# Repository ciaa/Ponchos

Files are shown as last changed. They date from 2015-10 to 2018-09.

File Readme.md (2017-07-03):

Ponchos
=======
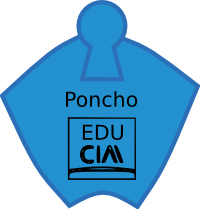
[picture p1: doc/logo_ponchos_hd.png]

Repositorio de Ponchos para la EDU-CIAA.

Llamamos **Ponchos** a los módulos conectables para montarse sobre el 
módulo procesador EDU-CIAA. 
Esperamos que el nombre “Poncho” se utilice como “Shield” en Arduino 
entre la comunidad del proyecto CIAA.

La documentación adicional sobre Ponchos se encuentra en la 
[Wiki del proyecto CIAA](http://www.proyecto-ciaa.com.ar/devwiki/doku.php?id=desarrollo:edu-ciaa:ponchos).

---

Estructura de directorios
-------------------------

* kicad: Bibliotecas de Kicad que utilizan los Ponchos.
  *libPonchos: Símbolos de esquemático (.lib) para crear un Poncho.
  *libModelos: Símbolos de esquemático (.lib) que usan los modelos.
  *Poncho_Esqueleto.pretty: Módulos que ayudan a crear un Poncho.
  *Poncho_Modelos.pretty: Módulos que utilizan los modelos.

* doc: Documentación común a todos los Ponchos.

* modelos: Ponchos básicos de ejemplo.
  * doc: Documentación particular.
  * Poncho_Grande: Un Poncho del mismo tamaño que la CIAA, con área de prototipado.
  * Poncho_Chico: Un Poncho que usa ambos conectores, pero ningún agujero de sujeción.

* ethernet_LAN8720A: Poncho Ethernet con el LAN8720A de MicroChip.
  * doc: Documentación particular del Poncho Ethernet.
  * info: Información adicional.
  * kicad: Archivos Kicad del Poncho Ethernet
    * hdatos: Hojas de datos relacionadas.
    * 3D: Modelos 3D. 

Ponchos nuevos
--------------

Al poner un Poncho en este repositorio intentar respetar como está organizado (abierto a debate). 
Las pautas al momento son las siguientes:

* Se abre un subdirectorio con el nombre del poncho: Por ejemplo, xyz.
* Dentro se ponen los archivos kicad y subdirectorios para la documentación, hojas de datos, etc.
* Los símbolos utilizados se ponen a partir de la raíz principal del repo en /kicad/libXyz.
* Los módulos utilizados se ponen a partir de la raíz principal del repo en /kicad/Poncho_Xyz.pretty

Idioma
------
El idioma de documentación de las EDU-CIAA es el castellano, por lo tanto los 
ponchos seguirán esa misma pauta. Se recomienda usar UTF-8 para los textos.

---
Proyecto CIAA http://www.proyecto-ciaa.com.ar/

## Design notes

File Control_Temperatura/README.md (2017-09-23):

# TPdesign_poncho
Nombre corto del proyecto: 
Interfaz de termocupla K mas salidas a Relay

Autor:
Francisco Suárez

Fecha de este documento::

28 Mayo de 2017

Licencia:
BSD
GPL V3, Open Hardware

Descripción:
Es una poncho destinado a intermediar con termocuplas mas el control de dos interruptores a traves de relays, pensado para hacer control de temperatura en un tanque de agua a travez de resistencias.

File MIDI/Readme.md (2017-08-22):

Poncho MIDI
===========
Poncho interfaz MIDI para la EDU-CIAA.

Este poncho fue diseñado con el objetivo de otorgar al proyecto CIAA de una interfaz MIDI acorde a las especificaciones eléctricas presentes en la _Especificación detallada del estándar MIDI 1.0_ y su posterior modificación en la _Actualización de Especificación Electrica (CA-033)_ del año 2014.

La documentación de las especificaciones citadas puede encontrarse en [Especificaciones Oficiales de la Asociación MIDI](https://www.midi.org/specifications).

Además de **12 pulsadores**, **3 encoders** (con pulsadores cada uno) y los **conectores para** las funcionalidades **MIDI IN**, **MIDI THRU** y **MIDI OUT**; se incluye un par de conectores tipo header para _stackear_ otros módulos para agregar funcionalidad a través de **_I2C_** o **entradas y salida analógicas** en caso de no poder acceder a conectores del tipo [Elevated socket](https://www.digikey.com/product-detail/en/samtec-inc/ESQ-120-14-G-D/SAM8767-ND/2640978) para fabricar el poncho y permitir otro nivel de _stacking_.

<p align="center">
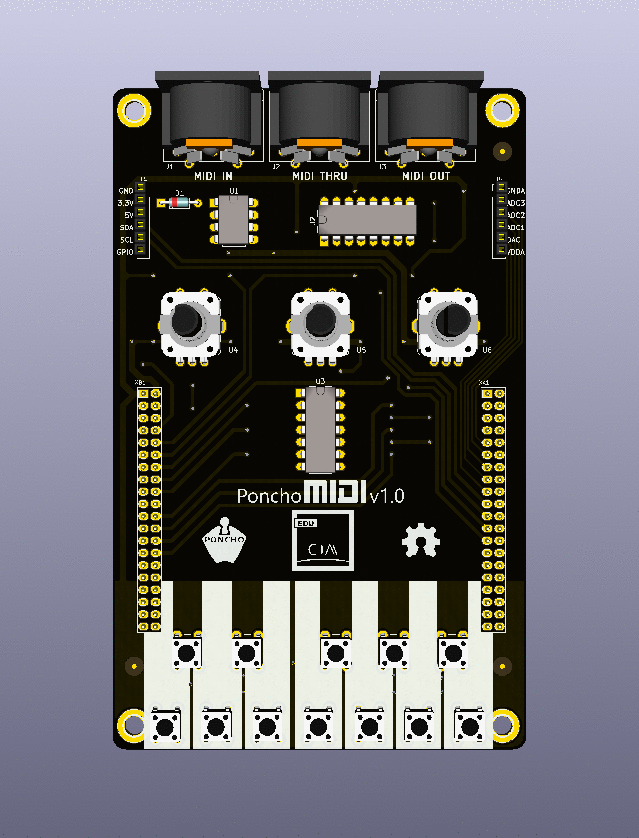
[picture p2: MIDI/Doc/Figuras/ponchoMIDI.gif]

</p>

---

Releases
--------

* **v1.0**
  * Release inicial para fabricación de serie piloto para validación de diseño.

* **v0.9**
  * Primera y última versión del poncho manteniendo como requisito la posibilidad de manufactura casera y artesanal. Si bien su realización sería compleja, el circuito presenta vias redundantes para cambiar de capa y que eliminan la necesidad de utilizar orificios metalizados.

Requisitos de diseño
--------------------

* Requisitos comunes a todos:
  * Licencia abierta (se tiene que poder publicar los archivos KiCad y la funcionalidad del circuito).
  * Utilizar Kicad 4.0.x. 
  * Consolidar toda la documentación en forma organizada dentro del directorio de proyecto de KiCad.
  * Aplicar una licencia o aclarar el Copyright.
  * Considerar en cada caso, los aspectos vistos referente a documentación.
  * Realizar diseño jerárquico salvo en circuitos muy pequeños.
  * Siempre que sea posible, considerar para los diseños componentes que se consigan en el mercado local.
  * Se utilizará como proveedor de referencia a Mayer (para las reglas de diseño).
  * Indicar que tipo/calidad de placa se considera para el diseño, intentando siempre que sea posible, seleccionar la de menor costo. 

* Requisitos específicos:
  * Debe realizarse en un circuito de 2 capas.
  * Debe cumplir con los requerimientos y recomendaciones de **(CA-033) MIDI 1.0 Electrical Specification Update [2014]**, que modifica a **MIDI 1.0 Detailed Specification (Document Version 4.2)** en el apartado de hardware.
  * Debe contener conectores para funcionalidades: MIDI IN, MIDI THRU y MIDI OUT.
  * Debe integrar 12 interruptores SPST, NO y sin retención.
  * Debe integrar 3 encoders rotativos con interruptor SPST, NO y sin retención incluido.
  * Debe facilitar la utilización de los conversores A/D de la EDU-CIAA.
  * Debe facilitar la utilización del conversor D/A de la EDU-CIAA.
  * Debe ocupar, como máximo, la superficie del poncho grande.

Asignación de pines
-------------------
<p align="center">

| Elemento	| Nombre EDU-CIAA	| Puerto	|
| --- |:---:|:---:|
| pulsador 0 	| GPIO8			| P6_12		|
| pulsador 1 	| GPIO7			| P6_11		|
| pulsador 2 	| GPIO5			| P6_9		|
| pulsador 3	| GPIO3			| P6_7		|
| pulsador 4	| GPIO1			| P6_4		|
| pulsador 5	| LCD1  		| P6_4		|
| pulsador 6	| CAN_TD 		| P3_2 		|
| pulsador 7	| T_COL1 		| P7_4 		|
| pulsador 8	| T_FIL0 		| P4_0 		|
| pulsador 9	| T_FIL3 		| P4_3 		|
| pulsador 10	| T_FIL2 		| P4_2 		|
| pulsador 11	| T_COL0 		| P1_5 		|
| encoder0_sw	| CRS_DV		| P1_16 	|
| encoder1_sw	| MDIO			| P1_17 	|
| encoder2_sw	| TXD0			| P1_18 	|
| encoder0_A	| SPI_MISO		| P1_3 		|
| encoder0_B	| TXD1 			| P1_20 	|
| encoder1_A	| LCD4 			| P4_10 	|
| encoder1_B	| LCD_RS 		| P4_8 		|
| encoder2_A	| LCD_3 		| P4_6 		|
| encoder2_B	| LCD_2 		| P4_5 		|
| MIDI_IN	| RS232_RXD		| P2_4 		|
| MIDI_OUT	| RS232_TXD		| P2_3 		|

</p>

Los puertos de expansión son una extensión sin cambios de la asignación de la EDU-CIAA.

Figuras
-------

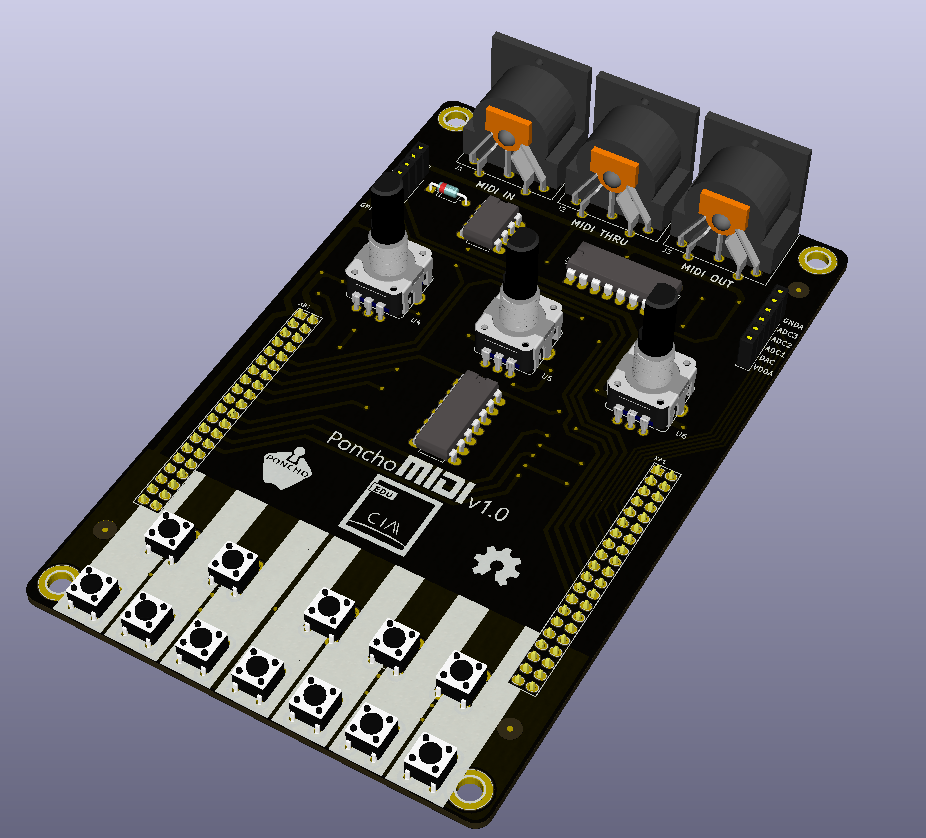
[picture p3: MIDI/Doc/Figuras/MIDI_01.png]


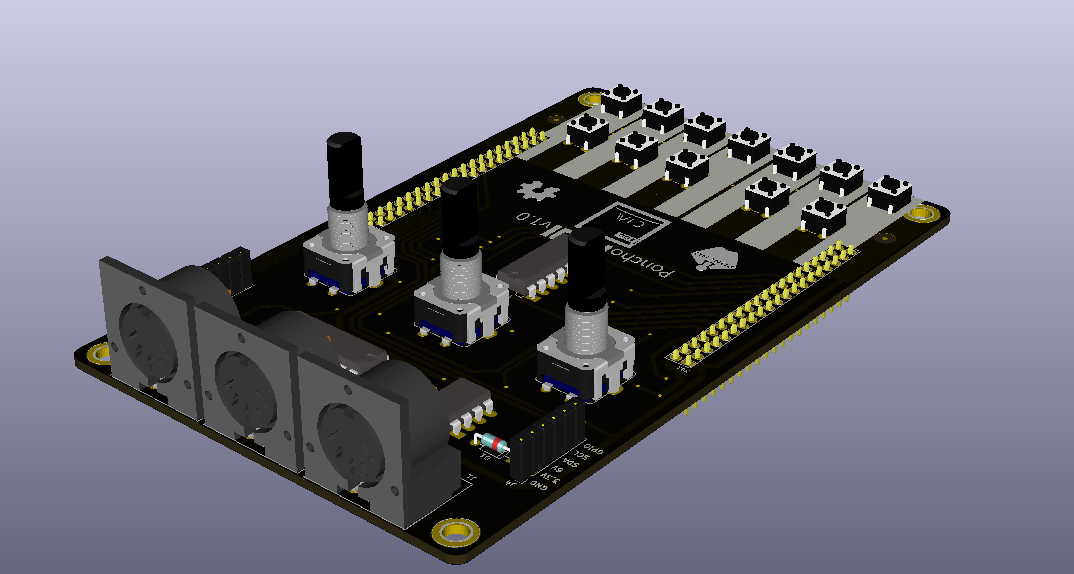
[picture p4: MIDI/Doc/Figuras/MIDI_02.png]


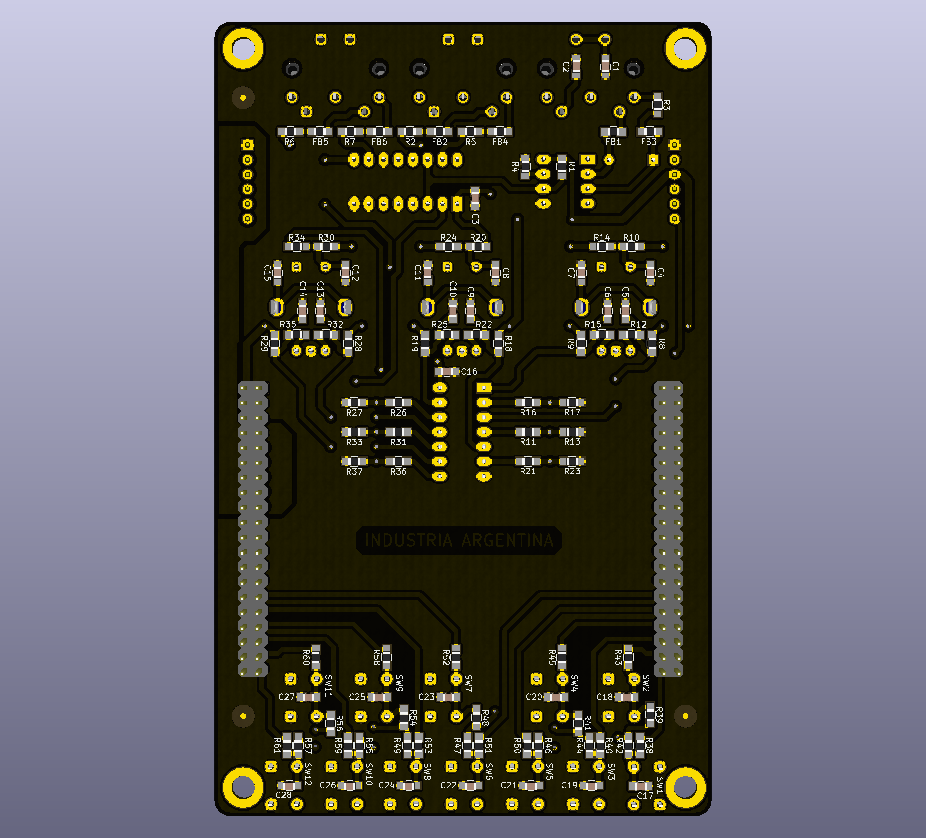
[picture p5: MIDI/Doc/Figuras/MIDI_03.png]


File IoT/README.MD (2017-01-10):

#Poncho IOT (Internet Of Things) para EDU-CIAA-NXP 

##Características Poncho

  - Módulo Wifi RN1810. Se utiliza mediante comandos por el puerto serial.
  - Dos salidas a Rele 220V-10A
  - Dos entradas optoacopladas
  - Sensor de temperatura analógico LM35
  
##Características PCB

El PCB fue pensado para ser construido manualmente, por lo que solo posee una capa (BOTTOM). La capa TOP solo indica jumpers que deben soldarse. Tambien es posible fabricarla en dos capas.
  
##Modelo 3D

<p align="center">
  
</p>

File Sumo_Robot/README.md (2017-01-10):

# PONCHO EDU-CIAA ROBOT SUMO #
 
RESPONSABLE:  
 
## ACTIVIDAD ##
Realizar un Poncho para la Edu-CIAA que permita controlar un robot sumo. 
 
## PAUTAS ##
  * PCB de doble capa (se manda a fabricar).  
  * Ver restricciones de Mayer S.A, de 12 Mils, pero se podría ver uno más barato. 
  * Manejo de dos motores en ambos sentidos, con relés. 
  * Manejo de 4 sensores de línea infrarrojos. 
  * Entrada de dos pulsadores. 
  * Manejo de un relé o salida transistor adicional. 
  * Posibilidad de manejar un servo. 
  * Posibilidad de conectar uno o dos módulos de ultrasonido FR04. 
  * Opción acelerómetro I2C. 
  * Considerar alimentación de 12 Volts. 
  * Considerar protecciones en el manejo de potencia: Motores, bobinas de relés y 
servos.

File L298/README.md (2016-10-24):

Desarrollo de un Modulo para motores basado en el L298.
Por: Juan Carlos Suarez Baron

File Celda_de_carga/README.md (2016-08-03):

# LoadCellShield

Proyecto de modulo externo (Poncho) de una celda de carga para la EDU-CIAA, durante el curso de Diseño de PCB del CESE.

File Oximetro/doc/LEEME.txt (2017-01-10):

Poncho oxímetro
=============

La función del poncho es implementar un oximetro de pulso basado en el integrado AFE4490 de Texas Instruments y usando como configuración del sensor el estándar introducido por Nellcor. 

URL: (URL en la wiki de la CIAA)
FUNCIÓN: Poncho de oxímetro de pulso.
AUTORES/INSTITUCIONES: Fernando Meira- CESE

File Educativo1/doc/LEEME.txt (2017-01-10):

EDUPONCHO
=============

Este circuito tiene una  variedad de componentes para realizar ensayos variados y poder aplicar los conceptos aprendidos en la carrera.
Implementa entradas Analógicas, salidas PWM, salidas a relé y  entradas optoacopladas.

URL: (URL en la wiki de la CIAA)
FUNCIÓN: Poncho Educativo.
AUTORES/INSTITUCIONES: Evangelista Guillermo- CESE

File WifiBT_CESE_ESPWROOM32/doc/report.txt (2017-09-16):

Info: Reading netlist file "E:\Embebidos\Materias\Diseño de PCB\Proyectos\PonchoEDUCIAA_WIFI_BLT\PonchoEDUCIAA_WIFI_BLT.net".

Info: Using references to match components and footprints.

Info: Checking netlist component footprint "C1:/591B3730:Capacitors_SMD:C_0603_HandSoldering".

Info: Checking netlist component footprint "C2:/591B36A3:Capacitors_SMD:C_0603_HandSoldering".

Info: Checking netlist component footprint "C3:/591B3654:Capacitors_SMD:C_0603_HandSoldering".

Info: Checking netlist component footprint "C4:/591B3D46:Capacitors_SMD:C_0603_HandSoldering".

Info: Checking netlist component footprint "C5:/591BA60B:Capacitors_SMD:C_0603_HandSoldering".

Info: Checking netlist component footprint "D1:/5915C6BB:LEDs:LED_0805".

Replacing component "D1:/5915C6BB" footprint "LEDs:LED_0402" with "LEDs:LED_0805".

Changing component "D1:/5915C6BB" pin "2" net name from "" to "Net-(D1-Pad2)".

Changing component "D1:/5915C6BB" pin "1" net name from "" to "GND".

Info: Checking netlist component footprint "D2:/5915C18C:LEDs:LED_0805".

Replacing component "D2:/5915C18C" footprint "LEDs:LED_0402" with "LEDs:LED_0805".

Changing component "D2:/5915C18C" pin "2" net name from "" to "Net-(D2-Pad2)".

Changing component "D2:/5915C18C" pin "1" net name from "" to "GND".

Info: Checking netlist component footprint "D3:/5915C2A8:LEDs:LED_0805".

Replacing component "D3:/5915C2A8" footprint "LEDs:LED_0402" with "LEDs:LED_0805".

Changing component "D3:/5915C2A8" pin "2" net name from "" to "Net-(D3-Pad2)".

Changing component "D3:/5915C2A8" pin "1" net name from "" to "GND".

Info: Checking netlist component footprint "F1:/592DFF9B:PonchoEDUCIAA_WIFI_BLTH:Fiducial_1mm".

Info: Checking netlist component footprint "F2:/592E0238:PonchoEDUCIAA_WIFI_BLTH:Fiducial_1mm".

Info: Checking netlist component footprint "F3:/592E4AA5:PonchoEDUCIAA_WIFI_BLTH:Fiducial_1mm".

Info: Checking netlist component footprint "J1:/591B2551:PonchoEDUCIAA_WIFI_BLTH:CON_PALETA_3".

Info: Checking netlist component footprint "R1:/5915C673:Resistors_SMD:R_0805_HandSoldering".

Info: Checking netlist component footprint "R2:/591B3C47:Resistors_SMD:R_0805_HandSoldering".

Info: Checking netlist component footprint "R3:/591B39FC:Resistors_SMD:R_0805_HandSoldering".

Info: Checking netlist component footprint "R4:/5915C27A:Resistors_SMD:R_0805_HandSoldering".

Info: Checking netlist component footprint "R5:/5915BEE9:Resistors_SMD:R_0805_HandSoldering".

Info: Checking netlist component footprint "R6:/591BB74F:Resistors_SMD:R_0805_HandSoldering".

Info: Checking netlist component footprint "R7:/591BB4D7:Resistors_SMD:R_0805_HandSoldering".

Info: Checking netlist component footprint "R8:/594ED4F2:Resistors_SMD:R_0805_HandSoldering".

Info: Checking netlist component footprint "SW1:/591BAB0F:Buttons_Switches_THT:SW_PUSH_6mm".

Info: Checking netlist component footprint "SW2:/591BBB9C:Buttons_Switches_THT:SW_Micro_SPST".

Info: Checking netlist component footprint "U1:/5911A5F3:PonchoEDUCIAA_WIFI_BLTH:ESP32-WROOM".

Info: Checking netlist component footprint "XA1:/5911AAD2:PonchoEDUCIAA_WIFI_BLTH:Conn_Poncho_Derecha".

Removing unused component "G1:".

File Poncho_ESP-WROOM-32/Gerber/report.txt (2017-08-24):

Se ha creado el archivo de trazado 'D:\Proyectos\Poncho_ESP-WROOM-32\Gerber\Poncho_ESP32-F.Cu.gbr'.
Se ha creado el archivo de trazado 'D:\Proyectos\Poncho_ESP-WROOM-32\Gerber\Poncho_ESP32-B.Cu.gbr'.
Se ha creado el archivo de trazado 'D:\Proyectos\Poncho_ESP-WROOM-32\Gerber\Poncho_ESP32-B.Paste.gbr'.
Se ha creado el archivo de trazado 'D:\Proyectos\Poncho_ESP-WROOM-32\Gerber\Poncho_ESP32-F.Paste.gbr'.
Se ha creado el archivo de trazado 'D:\Proyectos\Poncho_ESP-WROOM-32\Gerber\Poncho_ESP32-B.SilkS.gbr'.
Se ha creado el archivo de trazado 'D:\Proyectos\Poncho_ESP-WROOM-32\Gerber\Poncho_ESP32-F.SilkS.gbr'.
Se ha creado el archivo de trazado 'D:\Proyectos\Poncho_ESP-WROOM-32\Gerber\Poncho_ESP32-B.Mask.gbr'.
Se ha creado el archivo de trazado 'D:\Proyectos\Poncho_ESP-WROOM-32\Gerber\Poncho_ESP32-F.Mask.gbr'.
Se ha creado el archivo de trazado 'D:\Proyectos\Poncho_ESP-WROOM-32\Gerber\Poncho_ESP32-Edge.Cuts.gbr'.

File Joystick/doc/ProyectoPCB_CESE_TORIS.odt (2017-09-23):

Curso de Diseño de PCBs - CESE

Hoja de presentación de proyecto

Nombre corto del proyecto:

Joystick con edu-ciaa

Autor:

Alan Toris

Fecha de este documento:

14 de Mayo de 2017

Licencia:

BSD

Repositorio de trabajo:

https://gitlab.com/alantoris/poncho-joystick-edu-ciaa

Descripción:

Este circuito implementa un poncho de la edu-ciaa con funcionalidad de Joystick que puede ser usado como interface de control de otros sistemas como juegos en pantallas o proyectos con motores.

Requisitos del profesor:

Colocar los requisitos acordados con el profesor. Por ejemplo funciones mínimas, número de capas, tipo de fabricación, tipo de componentes y tecnología de montaje, circuitos de referencia charlados en clase, etc.

Requisitos comunes a todos:

1. Licencia abierta (se tiene que poder publicar los archivos KiCad y la funcionalidad del circuito).
2. Utilizar Kicad 4.0.x.
3. Consolidar toda la documentación en forma organizada dentro del directorio de proyecto de KiCad.
4. Aplicar una licencia o aclarar el Copyright.
5. Considerar en cada caso, los aspectos vistos referente a documentación.
6. Realizar diseño jerárquico salvo en circuitos muy pequeños.
7. Siempre que sea posible, considerar para los diseños componentes que se consigan en el mercado local.
8. Se utilizará como proveedor de referencia a Mayer (para las reglas de diseño).
9. Indicar que tipo/calidad de placa se considera para el diseño, intentando siempre que sea posible, seleccionar la de menor costo.

Tareas y Alcance:

Las tareas y alcance del proyecto serán:

1. Búsqueda de los esquemáticos de referencia.
2. Adaptaciones y agrupacion de los esquemático.
3. Ingreso de esquemático a Kicad.
4. Revisión del esquemático por Fabrizio Gelsi.
5. Cálculo de presupuesto y proveedores de componentes.
6. Selección de footprints.
7. Ubicación de componentes.
8. Ruteo.
9. Generación de Gerbers.

Enlaces:

Esquematico de un Joystick básico compatible con Arduino:

http://image.dfrobot.com/image/data/DFR0008/Input%20Shield%20V2%20sch.pdf
Se cambiara los pines de coneccion al modulo zigbee por pines de coneccion a un modulo acelerometro para agregar una funcionalidad de movimiento al Joystick.
Esquematico de un motor vibrador:

https://github.com/Arduinolibrary/DFRobot_Vibration_Module/raw/master/Vibration%20Schematic.pdf

Esquematico de un modulo speaker digital:

https://github.com/Arduinolibrary/DFRobot_Vibration_Module/raw/master/Vibration%20Schematic.pdf

Imágenes:

Modulo en los cuales se basa el proyecto:

Joystick básico compatible con Arduino:

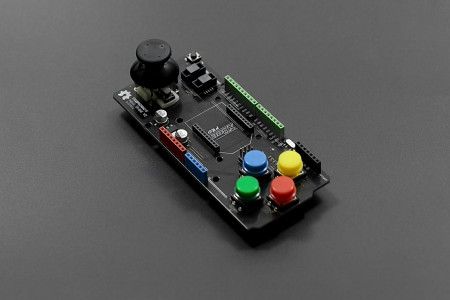
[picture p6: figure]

Modulo de motor vibrador:

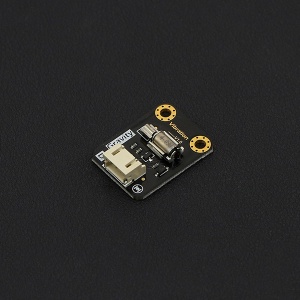
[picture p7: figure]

Modulo de speaker digital:

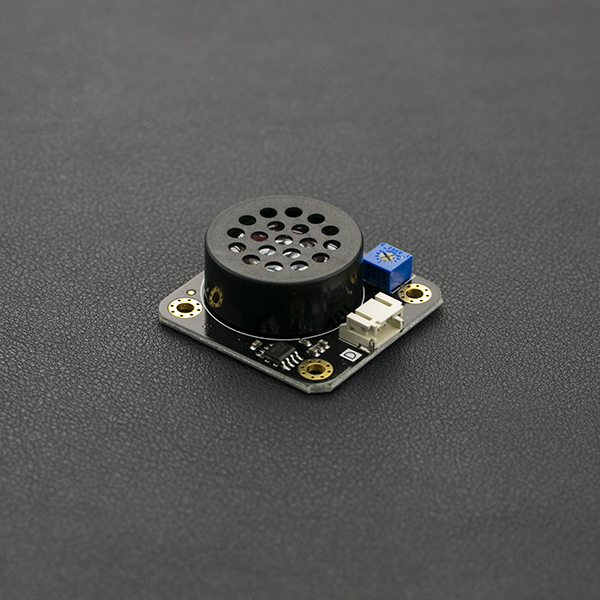
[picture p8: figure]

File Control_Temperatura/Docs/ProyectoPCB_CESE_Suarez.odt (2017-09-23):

Curso de Diseño de PCBs - CESE

Hoja de presentación de proyecto

Nombre corto del proyecto:

Interfaz de termocupla K mas salidas a Relay

Autor:

Francisco Suárez

Fecha de este documento::

28 Mayo de 2017

Licencia:

BSD

GPL V3, Open Hardware

Repositorio de trabajo:

https://github.com/fransuarez/TPdesign_poncho.git

Descripción:

Es una poncho destinado a intermediar con termocuplas mas el control de dos interruptores a traves de relays, pensado para hacer control de temperatura en un tanque de agua a travez de resistencias.

Requisitos del profesor:

Requisitos comunes:

1. Licencia abierta (se tiene que poder publicar los archivos KiCad y la funcionalidad del circuito).
2. Utilizar Kicad 4.0.x.
3. Consolidar toda la documentación en forma organizada dentro del directorio de proyecto de KiCad.
4. Aplicar una licencia o aclarar el Copyright.
5. Considerar en cada caso, los aspectos vistos referente a documentación.
6. Realizar diseño jerárquico salvo en circuitos muy pequeños.
7. Siempre que sea posible, considerar para los diseños componentes que se consigan en el mercado local.
8. Se utilizará como proveedor de referencia a Mayer (para las reglas de diseño).
9. Indicar que tipo/calidad de placa se considera para el diseño, intentando siempre que sea posible, seleccionar la de menor costo.

10. Pcb de dos capas.

Tareas y Alcance:

Indicar hasta donde se pretende llegar con el diseño y que tareas involucra. Por ejemplo:

1. Búsqueda de esquemáticos de referencia. (Obligatorio)
2. Adaptaciones de esquemático.
3. Ingreso de esquemático a Kicad. (Obligatorio)
4. Revisión del esquemático por un tercero. (Obligatorio)
5. Cálculo de presupuesto y proveedores de componentes. (Obligatorio)
6. Selección de footprints. (Obligatorio)
7. Ubicación de componentes. (Necesario para una buena calificación)
8. Ruteo. (Depende lo acordado)
9. Generación de Gerbers. (Depende lo acordado)

Enlaces:

http://ospid.com/blog/download/

https://github.com/osPID

Imágenes:

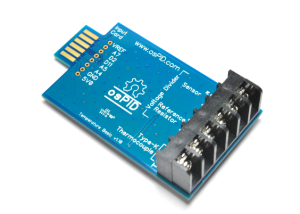
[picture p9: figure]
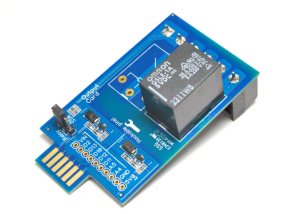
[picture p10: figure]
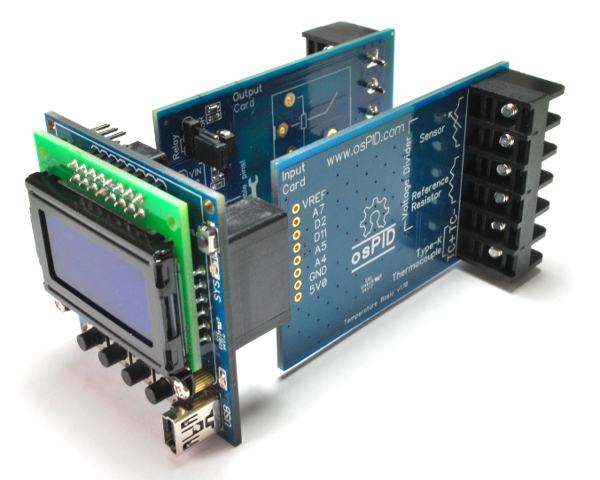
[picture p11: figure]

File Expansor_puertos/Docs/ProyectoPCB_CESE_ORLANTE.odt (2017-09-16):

Curso de Diseño de PCBs - CESE

Hoja de presentación de proyecto

Nombre corto del proyecto:

EduCiaa Port's Expander

Autor:

Orlante Mariano Damián

Fecha de este documento:

15 Mayo de 2017

Licencia:

BSD

Repositorio de trabajo:

https://marianoo2001@gitlab.com/marianoo2001/EduCiaaPE.git

Descripción:

Este circuito implementa un expansor de entradas y salidas digitales, y adaptador de nivel de tensión Low Voltage (3V3) a RS232 para puerto serie.

Las entradas digitales son del tipo a transistor NPN “sinking” y se activan con tensión de continua externa en el rango de entre 3,5 a 25VDC. Las entradas se pueden activar a través de contactos secos o salidas transistorizadas “sourcing”.

Las salidas digitales son del tipo a transistor NPN “sinking” a colector abierto. Una salida activada implica que el dispositivo entrega masa a la carga externa. Se deberá alimentar la carga con una tensión de entre 3,5 a 45VDC. alimentará con baterías y podrá usarse en aplicaciones con la EDU-CIAA.

Requisitos del profesor:

1. Licencia BSD.
2. Utilizar Kicad 4.0.x.
3. Consolidar toda la documentación en forma organizada dentro del directorio de proyecto de KiCad.
4. Aplicar una licencia o aclarar el Copyright.
5. Considerar en cada caso, los aspectos vistos referente a documentación.
6. Realizar diseño jerárquico salvo en circuitos muy pequeños.
7. Siempre que sea posible, considerar para los diseños componentes que se consigan en el mercado local.
8. Se utilizará como proveedor de referencia a Mayer (para las reglas de diseño).
9. Placa de dos capas, con componentes SMD, mascara antisoldante, serigrafías y todo realizado sobre soporte de FR4.
10. Al menos 8 entradas digitales.
11. Al menos 8 salidas digitales.
12. Al menos un puerto serie nivel RS232.

Tareas y Alcance:

1. Búsqueda de esquemáticos de referencia.
2. Adaptaciones de esquemático.
3. Ingreso de esquemático a Kicad.
4. Revisión del esquemático por un tercero.
5. Cálculo de presupuesto y proveedores de componentes.
6. Selección de footprints.
7. Ubicación de componentes.
8. Ruteo.
9. Generación de Gerbers.

Enlaces:

http://www.st.com/content/ccc/resource/technical/document/application_note/38/85/01/85/d2/2d/4d/45/CD00165404.pdf/files/CD00165404.pdf/jcr:content/translations/en.CD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

Imágenes:

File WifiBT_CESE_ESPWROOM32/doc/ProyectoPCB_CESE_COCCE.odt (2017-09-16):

Curso de Diseño de PCBs - CESE

Hoja de presentación de proyecto

Nombre corto del proyecto:

Poncho EDU-CIAA wifi-bluetooth

Autor:

Julio Gastón Coccé

Fecha de este documento::

11 de Mayo de 2017

Licencia:

BSD

Repositorio de trabajo:

https://github.com/gcocce/poncho_EDU-CIAA_wifi_blth

Descripción:

El circuito de este proyecto permite realizar un poncho para la EDU-CIAA usando el módulo ESP-WROOM-32 que cuenta con conectividad WIFI y BLUETOOTH. El circuito se alimenta con energía de la placa EDU-CIAA y se comunicará con la EDU-CIAA por UART.

Requisitos del profesor:

Colocar los requisitos acordados con el profesor. Por ejemplo funciones mínimas, número de capas, tipo de fabricación, tipo de componentes y tecnología de montaje, circuitos de referencia charlados en clase, etc.

Requisitos comunes a todos:

- Licencia abierta (se tiene que poder publicar los archivos KiCad y la funcionalidad del circuito).
- Utilizar Kicad 4.0.x.
- Consolidar toda la documentación en forma organizada dentro del directorio de proyecto de KiCad.
- Aplicar una licencia o aclarar el Copyright.
- Considerar en cada caso, los aspectos vistos referente a documentación.
- Realizar diseño jerárquico salvo en circuitos muy pequeños.
- Siempre que sea posible, considerar para los diseños componentes que se consigan en el mercado local.
- Se utilizará como proveedor de referencia a Mayer (para las reglas de diseño).
- Indicar que tipo/calidad de placa se considera para el diseño, intentando siempre que sea posible, seleccionar la de menor costo.

Tareas y Alcance:

Indicar hasta donde se pretende llegar con el diseño y que tareas involucra. Por ejemplo:

- Búsqueda de esquemáticos de referencia. (Obligatorio)
- Adaptaciones de esquemático.
- Ingreso de esquemático a Kicad. (Obligatorio)
- Revisión del esquemático por un tercero. (Obligatorio)
- Cálculo de presupuesto y proveedores de componentes. (Obligatorio)
- Selección de footprints. (Obligatorio)
- Ubicación de componentes. (Necesario para una buena calificación)
- Ruteo. (Depende lo acordado)
- Generación de Gerbers. (Depende lo acordado)
- Fabricación de prototipo. (Depende lo acordado, normalmente no se incluye)
- Validación funcional. (Depende lo acordado, normalmente no se incluye)

Enlaces:

https://espressif.com/en/producttype/esp-wroom-32

Imágenes:

Colocar imágenes ilustrativas, por ejemplo diseño o estado actual, producto similar o a copiar, etc.

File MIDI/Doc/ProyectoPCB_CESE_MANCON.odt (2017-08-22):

Nombre corto del proyecto:

Poncho MIDI

Autor:

Carlos I. Mancón

Fecha de este documento::

14 de Mayo de 2017

Licencia:

BSD

Repositorio de trabajo:

https://github.com/cmancon/Ponchos

Descripción:

Este circuito implementa una interfaz MIDI conforme a la especificación de dicho estándar y un conjunto de actuadores para el disparo de paquetes e interacción con dispositivos compatibles. Se alimentará a través de USB o fuente externa.

Requisitos:

Requisitos comunes a todos:

1. Licencia abierta (se tiene que poder publicar los archivos KiCad y la funcionalidad del circuito).
2. Utilizar Kicad 4.0.x.
3. Consolidar toda la documentación en forma organizada dentro del directorio de proyecto de KiCad.
4. Aplicar una licencia o aclarar el Copyright.
5. Considerar en cada caso, los aspectos vistos referente a documentación.
6. Realizar diseño jerárquico salvo en circuitos muy pequeños.
7. Siempre que sea posible, considerar para los diseños componentes que se consigan en el mercado local.
8. Se utilizará como proveedor de referencia a Mayer (para las reglas de diseño).
9. Indicar que tipo/calidad de placa se considera para el diseño, intentando siempre que sea posible, seleccionar la de menor costo.
  Requisitos específicos
10. Debe realizarse en un circuito de 2 capas.
11. Debe cumplir con los requerimientos y recomendaciones de "(CA-033) MIDI 1.0 Electrical Specification Update [2014]", que modifica a "MIDI 1.0 Detailed Specification (Document Version 4.2)" en el apartado de hardware.
12. Debe contener conectores para funcionalidades: MIDI IN, MIDI THRU y MIDI OUT.
13. Debe integrar 12 interruptores SPST, NO y sin retención.
14. Debe integrar 3 encoders rotativos con interruptor SPST, NO y sin retención incluido.
15. Debe facilitar la utilización de los conversores A/D de la EDU-CIAA.
16. Debe facilitar la utilización del conversor D/A de la EDU-CIAA.
17. Debe ocupar, como máximo, la superficie del poncho grande.

Tareas y Alcance:

1. Búsqueda de esquemáticos de referencia.
2. Adaptaciones de esquemático.
3. Ingreso de esquemático a Kicad.
4. Revisión del esquemático por un tercero.
5. Cálculo de presupuesto y proveedores de componentes.
6. Selección de footprints.
7. Ubicación de componentes.
8. Ruteo.
9. Generación de Gerbers.

Enlaces:

https://www.midi.org/specifications

https://www.sparkfun.com/products/12898

https://www.olimex.com/Products/Duino/Shields/SHIELD-MIDI/open-source-hardware

Imágenes:

Ejemplos de productos similares:

Sparkfun

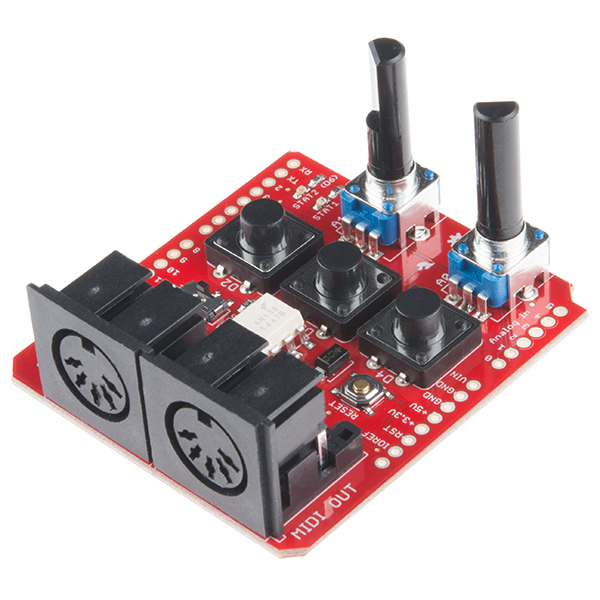
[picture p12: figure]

OLIMEX

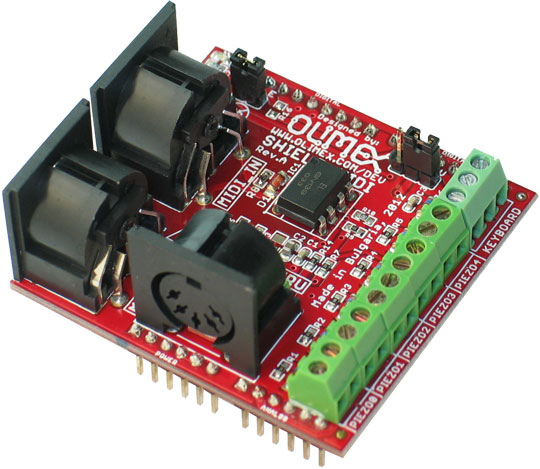
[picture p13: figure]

Curso de Diseño de PCBs - CESE Hoja de presentación de proyecto

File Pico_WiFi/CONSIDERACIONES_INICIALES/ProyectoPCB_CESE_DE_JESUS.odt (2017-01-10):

Curso de Diseño de PCBs - CESE

Hoja de presentación de proyecto

Nombre corto del proyecto:

Poncho wifi para la Pico-CIAA

Autor:

Sergio De Jesús

Fecha de este documento::

11 de noviembre de 2016

Licencia:

BSD

Repositorio de trabajo:

https://github.com/sergiordj/Poncho_wifi_picociaa

Descripción:

Se trata de una placa sencilla que contiene un módulo wifi ESP8266, conectores para la asociación a la picociaa y elementos de manejo del ESP.

Requisitos del profesor:

Colocar los requisitos acordados con el profesor. Por ejemplo funciones mínimas, número de capas, tipo de fabricación, tipo de componentes y tecnología de montaje, circuitos de referencia charlados en clase, etc.

Requisitos comunes a todos:

1. Licencia abierta (se tiene que poder publicar los archivos KiCad y la funcionalidad del circuito).
2. Utilizar Kicad 4.0.x.
3. Consolidar toda la documentación en forma organizada dentro del directorio de proyecto de KiCad.
4. Aplicar una licencia o aclarar el Copyright.
5. Considerar en cada caso, los aspectos vistos referente a documentación.
6. Realizar diseño jerárquico salvo en circuitos muy pequeños.
7. Siempre que sea posible, considerar para los diseños componentes que se consigan en el mercado local.
8. Se utilizará como proveedor de referencia a Mayer (para las reglas de diseño).
9. Indicar que tipo/calidad de placa se considera para el diseño, intentando siempre que sea posible, seleccionar la de menor costo.
10. Incluir en el diseño la plantilla de la pico-ciaa para el diseño de futuros ponchos.

Tareas y Alcance:

Indicar hasta donde se pretende llegar con el diseño y que tareas involucra. Por ejemplo:

1. Diseño de plantilla para ponchos de pico-ciaa
2. Búsqueda de esquemáticos de referencia.
3. Adaptaciones de esquemático.
4. Ingreso de esquemático a Kicad.
5. Revisión del esquemático por un tercero.
6. Cálculo de presupuesto y proveedores de componentes.
7. Selección de footprints.
8. Ubicación de componentes.
9. Ruteo.
10. Generación de Gerbers.

Enlaces:

https://github.com/ciaa/Hardware/tree/master/PCB/pico

https://github.com/ciaa/Ponchos

https://espressif.com/en/products/hardware/esp8266ex/overview

https:// (https://en.ai-thinker.com/)en.ai-thinker.com

Imágenes:

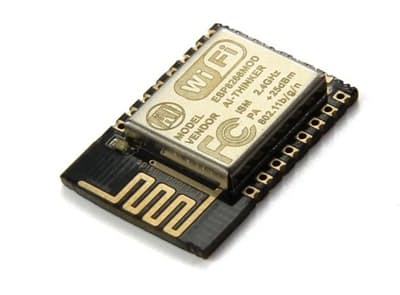
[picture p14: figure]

Módulo que será instalado en el poncho

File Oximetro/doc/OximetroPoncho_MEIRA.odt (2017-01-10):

Curso de Diseño de PCBs - CESE

Hoja de presentación de proyecto

Nombre corto del proyecto:

Poncho oxímetro

Autor:

Meira Fernando

Fecha de este documento::

19 de Diciembre de 2016

Licencia:

BSD

Repositorio de trabajo:

https://github.com/Fermeira/Oximetro_CESE.git

Descripción:

La función del poncho es implementar un oximetro de pulso basado en el integrado AFE4490 de Texas Instruments y usando como configuración del sensor el estándar introducido por Nellcor.

Requisitos del profesor:

Este es un circuito de dos capas, y solo una cara con componentes. Son componentes mixtos. SMT 0805 (capacitores y resistencias), 0603 (leds) y throughole para conectores, buzzer, reles y potenciometros.

Requisitos comunes a todos:

1. Licencia abierta (se tiene que poder publicar los archivos KiCad y la funcionalidad del circuito).
2. Utiliza Kicad 4.0.4.
3. Consolidar toda la documentación en forma organizada dentro del directorio de proyecto de KiCad.
4. Aplicar una licencia o aclarar el Copyright.
5. Considerar en cada caso, los aspectos vistos referente a documentación.
6. Realizar diseño jerárquico salvo en circuitos muy pequeños.
7. Siempre que sea posible, considerar para los diseños componentes que se consigan en el mercado local.
8. Se utilizará como proveedor de referencia a Mayer (para las reglas de diseño).
9. Indicar que tipo/calidad de placa se considera para el diseño, intentando siempre que sea posible, seleccionar la de menor costo.

Tareas y Alcance:

Indicar hasta donde se pretende llegar con el diseño y que tareas involucra. Por ejemplo:

1. Búsqueda de esquemáticos de referencia. (Obligatorio)
2. Adaptaciones de esquemático.
3. Ingreso de esquemático a Kicad. (Obligatorio)
4. Revisión del esquemático por un tercero. (Obligatorio)
5. Cálculo de presupuesto y proveedores de componentes. (Obligatorio)
6. Selección de footprints. (Obligatorio)
7. Ubicación de componentes. (Depende lo acordado)
8. Ruteo. (Depende lo acordado)

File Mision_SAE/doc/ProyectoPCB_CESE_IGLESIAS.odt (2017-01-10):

Curso de Diseño de PCBs - CESE

Hoja de presentación de proyecto

Nombre corto del proyecto:

Poncho Misión SAE

Autor:

Julián Iglesias

Fecha de este documento::

21 Noviembre de 2016

Licencia:

BSD

Repositorio de trabajo:

https://gitlab.com/julianmiglesias/MisionSAE

Descripción:

El Poncho misión SAE "Ingeniería Satelital en la Escuela" es una reimplementación en Kicad del Poncho utilizado para la actividad mencionada. Más información sobre el tema en http://www.suremptec.com/es/noticias-y-eventos/127-exitoso-cierre-de-la-primera-edicion-de-la-mision-sae.html . El Poncho posee un módulo ZigBee, un sensor de presión y un módulo acelerómetro.

Requisitos del profesor:

1. Diseño a dos capas.
2. Diseño del footprint de los módulos de sensores.
3. 4 agujeros de sujeción para la batería.
4. Placement de resistores del lado inferior.
5. Dejar libre el botón de reset.

Requisitos comunes a todos:

1. Licencia abierta (se tiene que poder publicar los archivos KiCad y la funcionalidad del circuito).
2. Utilizar Kicad 4.0.x.
3. Consolidar toda la documentación en forma organizada dentro del directorio de proyecto de KiCad.
4. Aplicar una licencia o aclarar el Copyright.
5. Considerar en cada caso, los aspectos vistos referente a documentación.
6. Realizar diseño jerárquico salvo en circuitos muy pequeños.
7. Siempre que sea posible, considerar para los diseños componentes que se consigan en el mercado local.
8. Se utilizará como proveedor de referencia a Mayer (para las reglas de diseño).
9. Indicar que tipo/calidad de placa se considera para el diseño, intentando siempre que sea posible, seleccionar la de menor costo.

Tareas y Alcance:

Indicar hasta donde se pretende llegar con el diseño y que tareas involucra. Por ejemplo:

1. Búsqueda de esquemáticos de referencia. (Obligatorio)
2. Adaptaciones de esquemático.
3. Ingreso de esquemático a Kicad. (Obligatorio)
4. Revisión del esquemático por un tercero. (Obligatorio)
5. Cálculo de presupuesto y proveedores de componentes. (Obligatorio)
6. Selección de footprints. (Obligatorio)
7. Ubicación de componentes. (Depende lo acordado)
8. Ruteo. (Depende lo acordado)
9. Generación de Gerbers. (Depende lo acordado)
10. Fabricación de prototipo. (Depende lo acordado)
11. Validación funcional. (Depende lo acordado)

Enlaces:

Colocar enlaces relevantes de referencia si los hay.

Imágenes:

Colocar imágenes ilustrativas, por ejemplo diseño o estado actual, producto similar o a copiar, etc.

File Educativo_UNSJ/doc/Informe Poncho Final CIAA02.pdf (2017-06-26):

### “Poncho educativo para la EDU-CIAA desarrollado por la UNSJ”

Autor: Sarmiento, Leandro Gustavo

Catedra: Microcontroladores

Carrera: Ingeniería Electrónica

Profesores: Dr. Ing. Eugenio Orosco, Ing. Carlos Gil, Ing. Gustavo Ensinck.

Laboratorio de Electrónica Digital

Dpto. de Electrónica y Automática

Facultad de Ingeniería – Universidad Nacional de San Juan (FI-UNSJ)

Resumen: En el marco de un proyecto de cátedra, se realizaron el diseño y la construcción de una placa tipo "poncho" complementando la reciente adquisición de EDU-CIAA para la enseñanza en el ámbito universitario. El poncho consta de elemento digitales y analógicos tales como: potenciómetro, buzzer, UART/RS-232, LCD 16x2, teclado matricial 4x3, y pinout para comunicaciones varias y pines de propósito general. Además, se desarrolló software mediante ejemplo para su uso y enseñanza en las cátedras relacionadas a los sistemas embebidos, en las carreras Ing. Electrónica y Bioingeniería. El diseño del hardware parte de la premisa de maximizar compatibilidad con los formatos pre-establecidos por el proyecto CIAA. El formato elegido es el poncho grande, el cual es de hardware libre como también lo es el presente proyecto. Se cumplió el objetivo principal planteado de aportar al proyecto EDU-CIAA funcionalidad adicional en el ámbito universitario.

Introducción

En este proyecto estudiantil se realizó un Poncho educativo para la EDU-CIAA desarrollado como un proyecto de cátedra. El concepto de poncho se refiere a módulos electrónicos montados sobre el módulo procesador principal, en este caso la EDU-CIAA.

La amplitud de campos de aplicación de la EDU-CIAA es muy extensa, sin embargo, ésta plataforma comprende lo que puede entenderse como un “módulo procesador” y no puede utilizarse por sí sola debido a que carece de interfaces. Es por eso que necesitamos otros módulos electrónicos que permitan ser la interfaz entre la EDU-CIAA y el mundo real. Estas interfaces pueden ser, de usuario, de comunicación, adquisición de datos a través de sensores, etc.

En base a la experiencia en otras plataformas (Arduino, Raspberry Pi, etc.), encontramos que utilizar estas interfaces es la forma en que se obtienen mejores y más rápidos resultados a la hora de desarrollar una aplicación nueva. De esta forma no se pierde tiempo y esfuerzo en desarrollar módulos de hardware ad-hoc y se implementan desarrollos modulares mediantes placas montadas sobre una placa base.

Interfaces prediseñadas, probadas y con cierto background de desarrollo (ejemplos, drivers, manuales, etc.) permiten disminuir la barrera de ingreso a la utilización de la EDU-CIAA / CIAA y concentrarse en el diseño de software. De esta manera facilitan la enseñanza de programación y acerca la aplicación de la electrónica a gente de otras ramas.

El diseño de los esquemáticos y del pcb se realizó con el software libre KiCad el cual también es utilizado en el proyecto EDU-CIAA. Al no tener experiencia en este software, se aprendió todo lo relacionado con este desde lo más básico a lo más avanzado para cumplimentar todas las tareas propuestas. El desarrollo de los drivers se hizo en lenguaje C con la ayuda de LPCOpen, esta es una extensa colección de bibliotecas de software libre y programas de ejemplo que permiten a los desarrolladores crear productos multifuncionales basados en microcontroladores LPC con editando de los códigos con el IDE LPCXpresso.

Especificaciones de diseño planteadas.

La idea de anexarle un poncho a la EDU-CIAA es brindarle más funcionalidad a la placa base para poder implementar diversos programas en el ámbito de la enseñanza a alumnos universitarios. En la Figura 1 se muestra el desarrollo final y las especificaciones de diseño propuestas son las siguientes:

- Potenciómetro
- Buzzer
- Display LCD 16x2.
- Teclado matricial 4 x 3.
- UART – RS232
- Salidas de propósitos generales.
- I2C
- SPI
- CAN

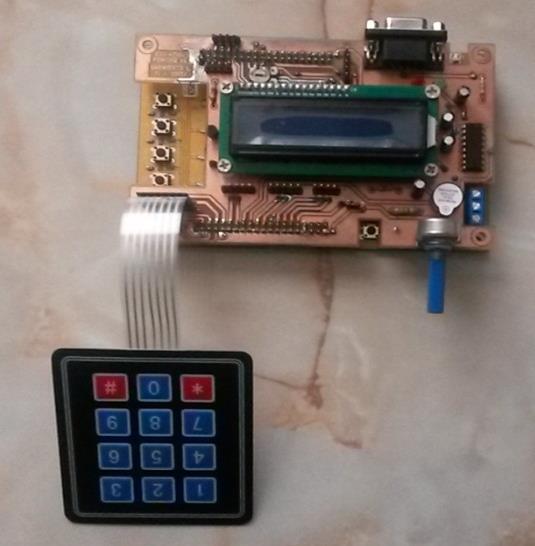
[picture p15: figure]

Figura 1. Vista general de placa base EDU-CIAA y poncho con teclado y otros elementos.

Desarrollo del hardware.

En el presente desarrollo se utilizó el modelo de Poncho Grande el cual se encuentra en el repositorio de ponchos del Proyecto CIAA cuyo autor es el Ing. Diego Brengi. Una vez que se obtuvo el modelo se empezó a editar el esquemático y posteriormente el pcb. Con la premisa que el proyecto de la CIAA se diseñó mediante el software KiCad, por lo que el punto de inicio en este proyecto fue aprender el uso de esta aplicación de diseño.

El programa KiCad tiene licencia GPL y sus principales ventajas son: disponibilidad de código fuente; gratuidad; formatos abiertos y documentables; formato en modo texto (ASCII); multiplataforma; utilizado en la mayoría de los proyectos actuales libre fuente actuales. Y desventajas como: documentación cambiante; cambios constantes en formatos (mejoras); diferencias entre distintas versiones; necesita seguir mejorando su interfaz; necesita incorporar funcionalidades para optimizar tiempos y para circuitos más complejos.

En virtud que el proyecto de cátedra incluye el objetivo de aprendizaje y difusión de las herramientas relacionadas al proyecto CIAA, tal como el desarrollo del hardware basado en KiCad, se presenta a continuación a modo informativo las partes principales de dicho software.

En la Figura 2(a) se muestran el administrado de proyecto, Eschema y Pcbnew, siendo el punto de entrada y manejos de archivos relacionados al proyecto, el diseño de los esquemáticos y del diseño de la placa de circuito impreso (PCB), respectivamente. Luego, el visor 3D es para observar el aspecto físico y el GerbView muestra el diseño en formato estándar Gerber (Figura 2(b)). Finalmente, en la Figura 2(c) se detallan el editor de Footprint y el de librería, para generar componentes nuevos o editar existentes. Toda la documentación oficial del programa se encuentra en http://kicad-pcb.org/help/documentation/.

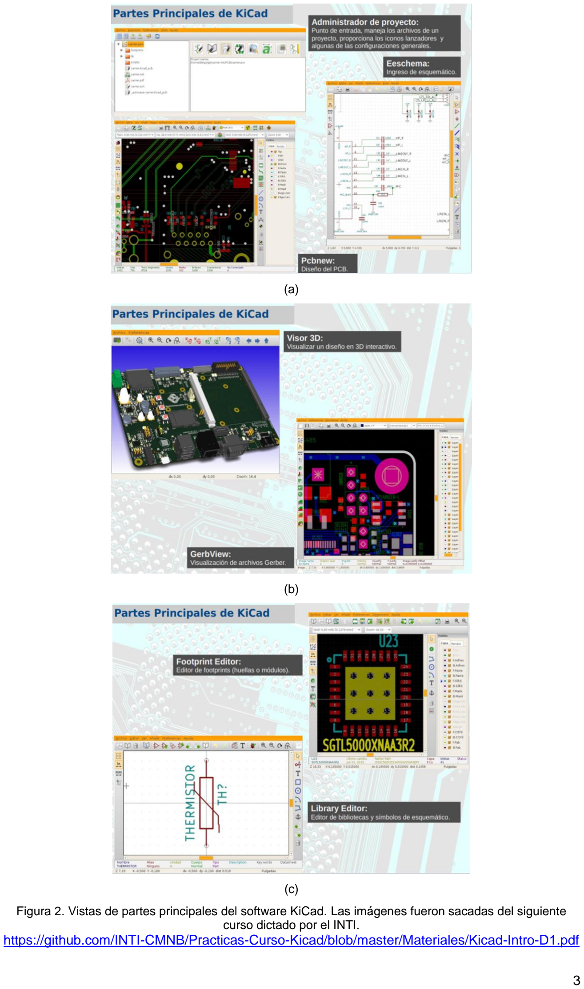
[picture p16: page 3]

(a)

(b)

(c)

Figura 2. Vistas de partes principales del software KiCad. Las imágenes fueron sacadas del siguiente curso dictado por el INTI. https://github.com/INTI-CMNB/Practicas-Curso-Kicad/blob/master/Materiales/Kicad-Intro-D1.pdf

Esquemáticos de poncho educativo.

ADC/DAC: Los tres ADC y el DAC se conectan a un conector de cuatro terminales (Figura 3). El ADC3 tiene la particularidad que a través de una Jumper se conecta al punto medio de un potenciómetro circular lineal. Esto se diseñó así para que el alumno pueda interactuar con dicho sensor para simular por ejemplo rotaciones angulares.

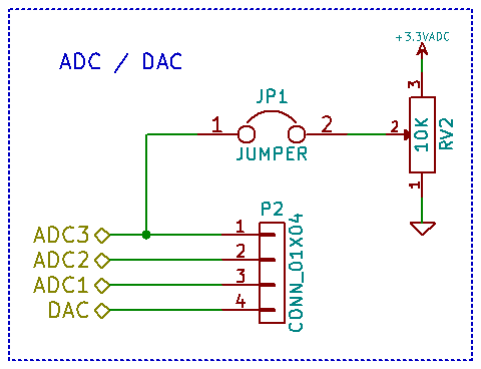
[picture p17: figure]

Figura 3. Esquemático ADC/DAC. LCD: Para la interacción visual con la EDU-CIAA se diseñó el circuito típico para manejar un LCD en la configuración de 4 bits. Además, se conectó un preset para poder ajustar el contraste del display (Figura 4).

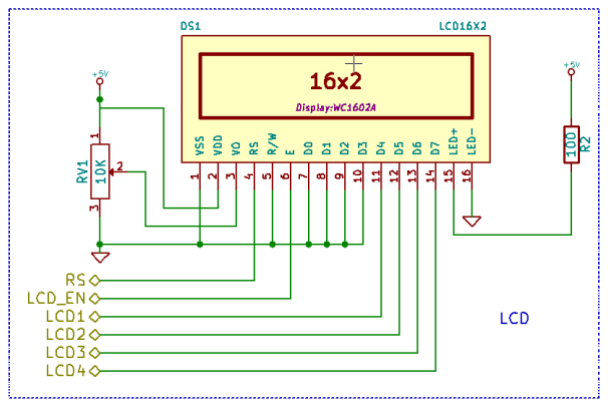
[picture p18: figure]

Figura 4. Esquemático para LCD. Teclado: El teclado matricial de 4x3 se diseñó de tal manera que las líneas tanto de las columnas como las filas están conectadas a un conector de siete terminales en el cual se conecta un teclado de membrana quedando externo al poncho (Figura 5).

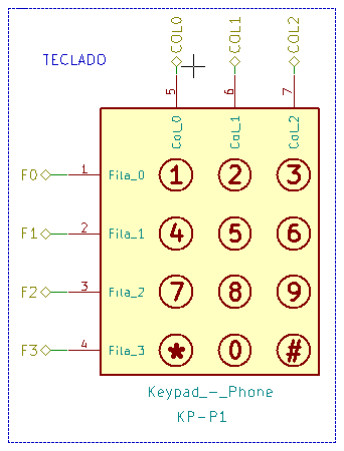
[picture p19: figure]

Figura 5. Esquemático de conexión a teclado matricial 4x3.

GPIO: Las Entrada/Salida de Propósito General son pines genéricos, cuyo comportamiento (incluyendo si es un pin de entrada o salida) se puede programar por el usuario en tiempo de ejecución (Figura 6). Se determinó poner dos conectores de cuatro terminales cada uno y el GPIO8 se usó para la configuración en la base de un transistor el cual enciende o apaga un Buzzer.

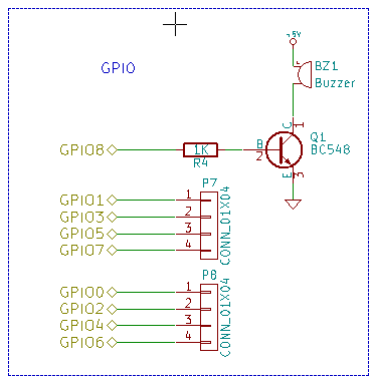
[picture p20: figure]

Figura 6. Esquemático de pines GPIO y Buzzer. RS232: Para la comunicación serie se decidió incorporar el circuito típico para la transmisión con la ayuda de un CI MAX232 añadiendo dos Leds para indicar lumínicamente cuando transmite y cuando recibe datos. El conector DB9 también se ubica en la placa el cual es hembra (Figura 7).

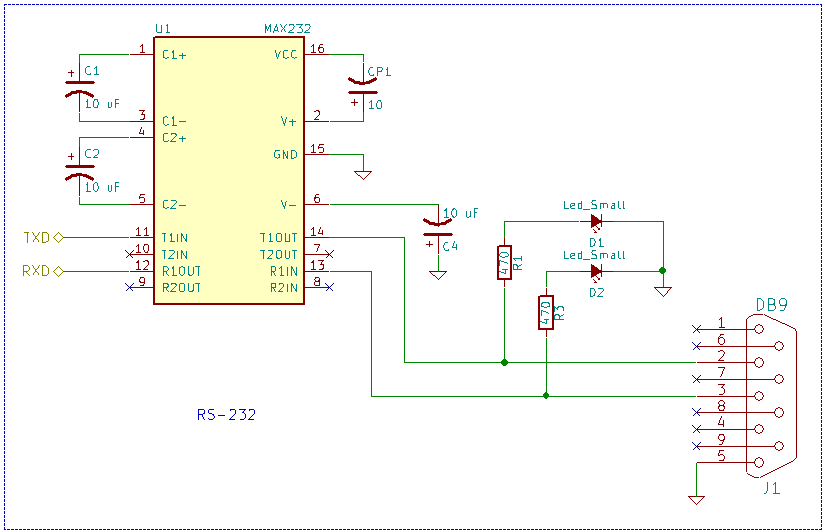
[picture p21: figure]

Figura 7. Esquemático para conexionados de RS-232. CAN Bus: El bus CAN es un protocolo de comunicaciones basado en una topología bus para la transmisión de mensajes en entornos distribuidos las señales además de las tensiones y de una señal de masa se conectan a un conector de cinco terminales (Figura 8(a)).

SPI: El Bus SPI es un estándar de comunicaciones, usado principalmente para la transferencia de información entre circuitos integrados en equipos electrónicos. El bus de interfaz de periféricos serie o bus SPI es un estándar para controlar casi cualquier dispositivo electrónico digital que acepte un flujo de bits serie regulado por un reloj (comunicación sincrónica) por ende estas líneas se conectan junto a señales de tensión y masa a un conector de cinco terminales (Figura 8(b)).

I

2C: Este Bus de datos serial se utiliza principalmente internamente para la comunicación entre
diferentes partes de un circuito. | El I²C está diseñado como un bus maestro-esclavo. La
transferencia de datos es siempre inicializada por un maestro; el esclavo reacciona. | Por

ende estas líneas se conectan junto a señales de tensión y masa a un conector de cinco terminales (Figura 8(c)).

Ethernet: Estos terminales no se usaron porque no aspiramos a tener comunicación Ethernet pero en un futuro tenemos ganas de diseñar un poncho para poder utilizar este tipo de comunicación ya que se puede usar tranquilamente para diseñar un sistema embebido IOT (Internet of Things) (Figura 8(d)).

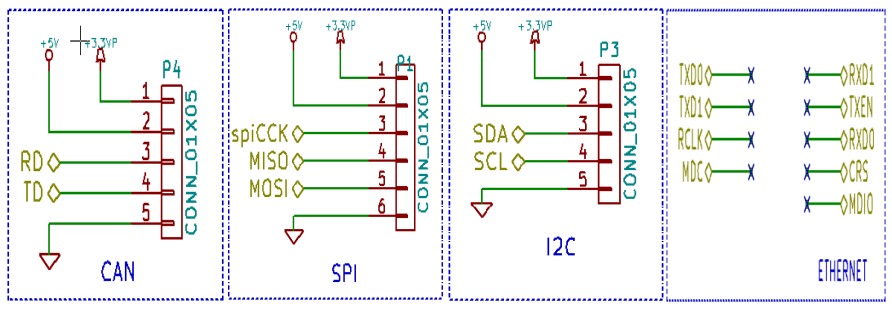
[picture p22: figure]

(a) | (b) | (c) | (d)

Figura 8. Esquemáticos de comunicaciones digitales. Placa de circuito impreso de poncho educativo (PCB).

Para llevar acabo el diseño del PCB se uso la plantilla de “poncho grande” proporcionada por el proyecto en la pagina web en la seccion ponchos. La misma se diseñó de dos capas y la distribución de los componentes se estudió las recomendaciones de diseño del tutorial en http://alternatezone.com/electronics/files/PCBDesignTutorialRevA.pdf. En las imágenes de la Figura 9 se ven la parte de inferior (a) y la parte superior (b) del diseño final del poncho educativo.

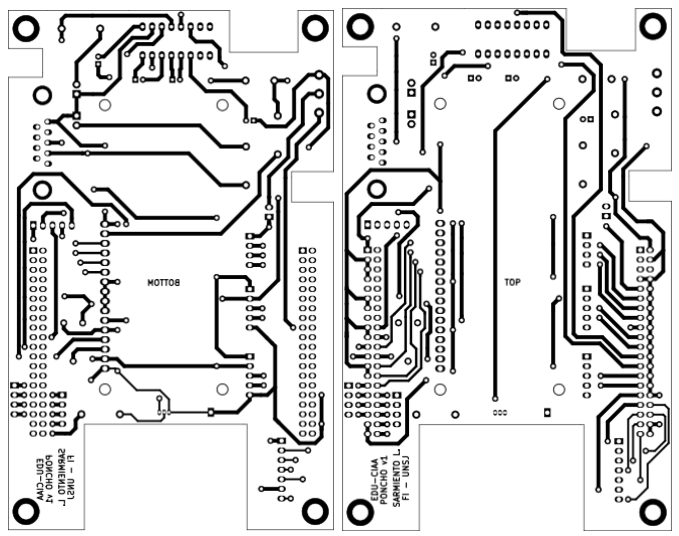
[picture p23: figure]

(a) (b)

Figura 9, Diseño final de placa circuito impreso parte de inferior (a) y la parte superior (b)

Desarrollo de Drivers.

El desarrollo de los drivers se hizo en lenguaje C con la ayuda de LPCOpen, esta es una extensa colección de bibliotecas de software libre y programas de ejemplo que permiten a los desarrolladores crear productos multifuncionales basados n microcontroladores LPC con la edición de los códigos con el IDE LPCXpresso. Los drivers de los periféricos se desarrollaron en lenguaje C, de autoría del presente grupo de trabajo (autor y asesores), y se destacan los aportes de las personas de la comunidad de embebidos32.

https://groups.google.com/forum/#!forum/embebidos32

Los proyectos ejemplos se encuentran en el siguiente repositorio donde se respetan los derechos de autor (GPL) de todos los contribuyentes al proyecto en el desarrollo de los drivers.

https://github.com/leansarmi/Projects

Conclusion y discusiones.

Se cumplieron las pautas de diseño y funcionalidad en el desarrollo del hardware y del software. Se espera que se pueda utilizar el poncho en materias de enseñanza de microcontroladores, donde en la presente institución se dictan en carreras de Ingeniería Electrónica y Bioingeniería. También se espera emplearlo con profesionales y estudiantes de otras áreas y de todo el país, ya que el diseño del hardware es libre.

Con la funcionalidad ampliada de la EDU-CIAA se podrá ampliar los alcances de la CIAA, bajar costos de desarrollo y aprendizaje, democratizar el uso de la CIAA en empresas e individuos y reducir tiempo de enseñanza.

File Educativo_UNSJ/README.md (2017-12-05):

# Poncho Educativo de la UNSJ #
* Autor: Sarmiento, Leandro Gustavo
* Facultad de Ingeniería – Universidad Nacional de San Juan (FI-UNSJ)

El poncho consta de elemento digitales y analógicos tales
como: potenciómetro, buzzer, UART/RS-232, LCD 16x2, teclado matricial 4x3, y pinout para
comunicaciones varias y pines de propósito general.

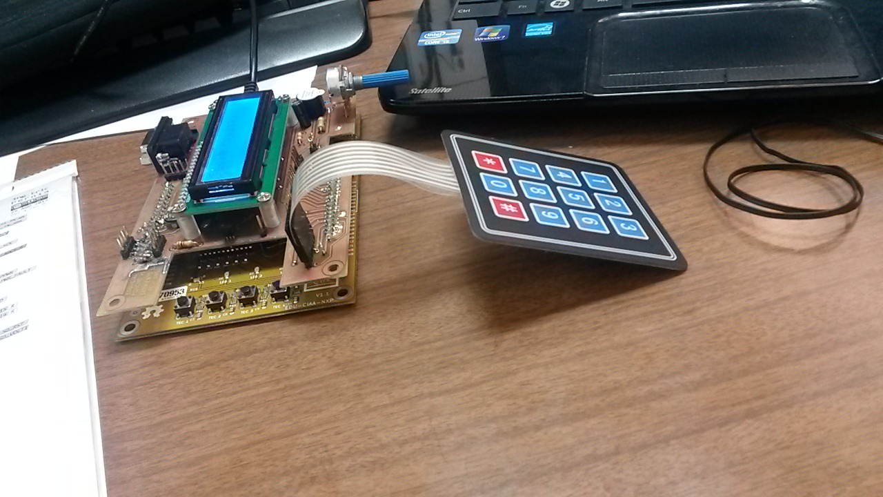
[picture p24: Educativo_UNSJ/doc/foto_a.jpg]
Foto Poncho Educativo UNSJ


Ver información sobre el Poncho en el siguiente PDF:
* [Reporte Poncho Educativo UNSJ.PDF](https://github.com/ciaa/Ponchos/raw/master/Educativo_UNSJ/doc/Informe%20Poncho%20Final%20CIAA02.pdf)
* [Wiki Proyeto CIAA](http://www.proyecto-ciaa.com.ar/devwiki/doku.php?id=repo:ponchos:educativounsj)

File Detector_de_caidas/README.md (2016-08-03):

# fall_detector
Poncho para la plataforma CIAA con el cual se podrán detectar e informar caídas.

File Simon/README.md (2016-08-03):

CREACION DEL ARCHIVO: 30/06/16

AUTOR: Juan Agustin Bassi

Aclaraciones de caracter general para el proyecto "PONCHO SIMON" para la plataforma educativa EDU-CIAA NXP.

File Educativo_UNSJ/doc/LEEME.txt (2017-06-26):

Poncho Educativo para la EDU-CIAA desarrollado por la UNSJ
==========================================================

<<En el marco de un proyecto de cátedra, se realizó el diseño y la construcción de una placa tipo "poncho" complementando la reciente adquisición de EDU-CIAA para la enseñanza en el ámbito universitario. El poncho consta de elemento digitales y analógicos tales como: potenciómetro, buzzer, UART/RS-232, LCD 16x2, teclado matricial 4x3, y pinout para comunicaciones varias y pines de propósito general. Además, se desarrolló software mediante ejemplo para su uso y enseñanza en las cátedras relacionadas a los sistemas embebidos, en las carreras Ing. Electrónica y Bioingeniería. El diseño del hardware parte de la premisa de maximizar compatibilidad con los formatos pre-establecidos por el proyecto CIAA. El formato elegido es el poncho grande, el cual es de hardware libre como también lo es el presente proyecto. Se cumplió el objetivo principal planteado de aportar al proyecto EDU-CIAA funcionalidad adicional en el ámbito universitario.>>

URL: (URL en la wiki de la CIAA)
FUNCIÓN: Enseñar el "ABC" (puntapié inicial) respecto a la programacion de la EDU-CIAA mediante el uso de los perifericos que se encuentran en el poncho educativo.
AUTORES/INSTITUCIONES: 

Autor: Sarmiento, Leandro Gustavo
Catedra: Microcontroladores
Carrera: Ingeniería Electrónica
Profesores: Dr. Ing. Eugenio Orosco, Ing. Carlos Gil, Ing. Gustavo Ensinck.
Laboratorio de Electrónica Digital
Dpto. de Electrónica y Automática
Facultad de Ingeniería – Universidad Nacional de San Juan (FI-UNSJ)

<<Detalle y explicación de directorios o archivos adicionales que se incorporen.>>

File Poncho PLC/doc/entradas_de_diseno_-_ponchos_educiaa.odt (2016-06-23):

Nombre del Pocho: | IDE4PLC
Responsable de Diseño: | MARIANO BUSTOS
Sub-responsable de Diseño:

Se deben definir los requerimientos antes de comenzar el trabajo ya que los mismos se convertirán en entradas de diseño contra la cuales luego se podrán evaluar/verificar los resultados obtenidos. Aún aunque se trate de un proyecto final, es aconsejable que nos acostumbremos a trabajar de esta manera.

Uso previsto: Funcionalidad que agregará a la EDU-CIAA | DOTAR A LA EDU-CIAA DE LAS INTERFACES NECESARIOS PARA PODER HACER PRACTICAS EN ESCUELAS SECUNDARIAS UTILIZANDO EL SOFTWARE IDE4PLC
Versión de Kicad empleada Versión recomendada 4.0.0-rc1-stable | 4.0.1-stable
Requerimientos de desempeño: Indicar características técnicos generales y de desempeño en condiciones normales de funcionamiento. Indicar en caso que corresponda valores admisibles para los parámetros más relevantes de diseño. (Rangos y Tolerancias). | Es deseable que el poncho incluya : 8 Salidas Digitales 7 entradas digitales Conexión para LCD Conexión para Puerto RS-232 Conexión para SPI/I2C Se buscara adaptar los diseños originales de la placa CIAA, migrando los componentes necesarios para que cada usuario/institución pueda conseguirlos localmente.
Requerimientos físicos: Dimensiones, compatibilidad de conectores, tipo de pcb en caso que aplique. | Se usara como base el Template “Poncho Grande” y una vez seleccionado los componentes definitivos se ajustaran las dimensiones finales.
Requerimientos de seguridad y EMC: Indicar detalle o norma aplicable en caso que corresponda. | La utilización principal es didáctica, con lo cual no se orientará a la aprobación de ninguna norma específica.
Compatibilidad con otros ponchos: Indicar si el diseño es funcional para su integración al uso de otros ponchos sobre la EDU-CIAA o si el diseño pin a pin compatible con otro poncho ya diseñado. | No contemplado en el diseño inicial.
Funcionalidad General y Firmware del sistema: Indicar Requerimientos de ensayo (testing) de las funcionalidades del poncho. Indicar si deben desarrollarse módulos de firmware extra o se pueden emplear los existentes (detallar cuáles). | Sería recomendable que se desarrolle una aplicación para el ensayo de las funcionalidades a nivel general, para que el usuario al recibir o armar el poncho pueda verificar el correcto funcionamiento del mismo.
Documentación de diseños previos: Indicar si se emplea algún proyecto previo incluso si se trata de proyecto CIAA. | Se utilizan como base los siguientes proyectos: TEMPLATE PONCHO GRANDE CIAA-NXP
Requerimientos normativos: Indicar si la aplicación en la cual se prevé emplear el poncho tiene algún Requerimiento de este tipo. | No corresponde.

Observaciones y Detalles extras:

Elaboró | | | Mariano Bustos | Revisó
29 | 01 | 2016

Formulario Versión: DATOS DE ENTRADA DE DISEÑO POCHOS EDU-CIAA Fecha: 26/10/15 Página 2 de 2 Rev 1.3

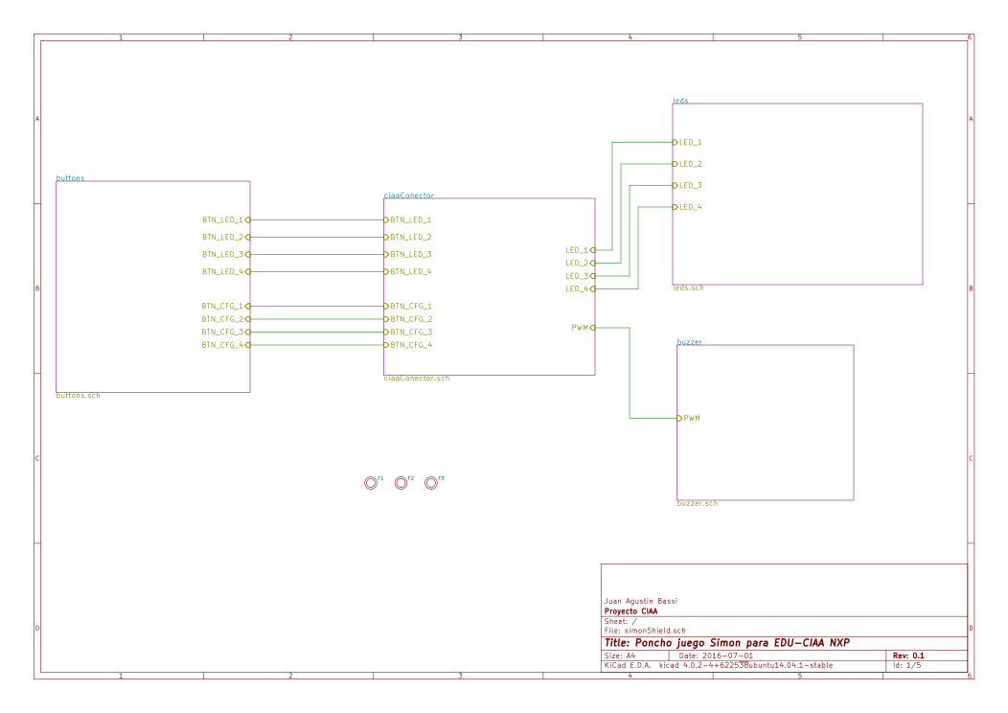
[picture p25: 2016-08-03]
Simon/doc/schematic.png

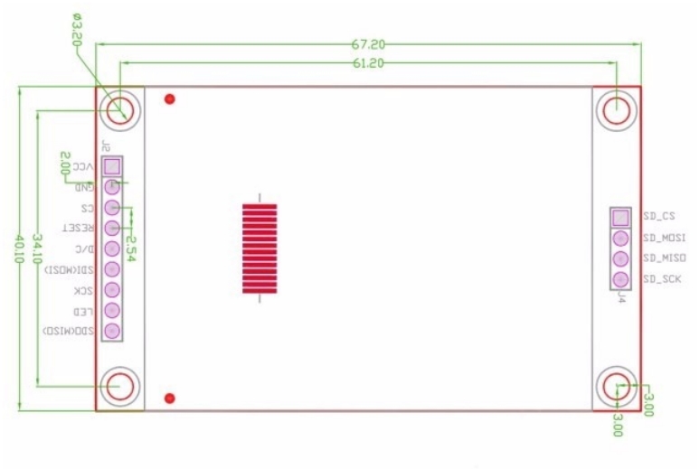
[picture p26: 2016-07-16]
Osciloscopio/hdatos/Display pinout y dimensiones.jpg

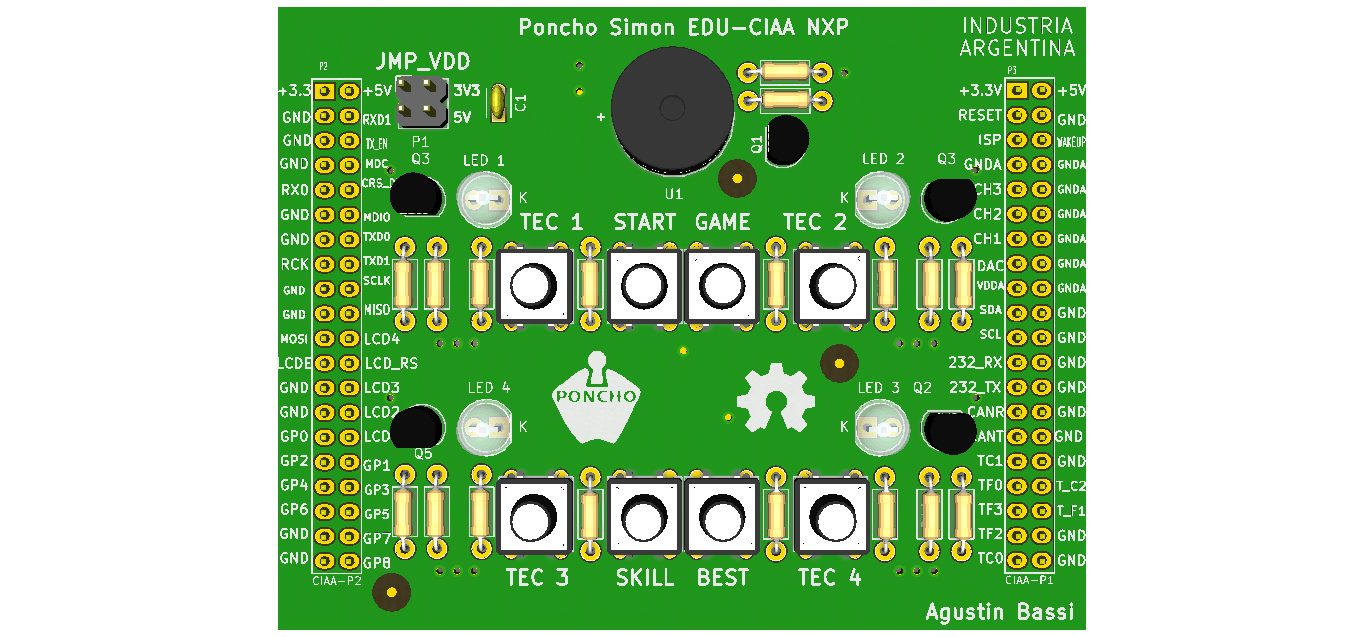
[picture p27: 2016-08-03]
Simon/doc/simonShieldTop2.png

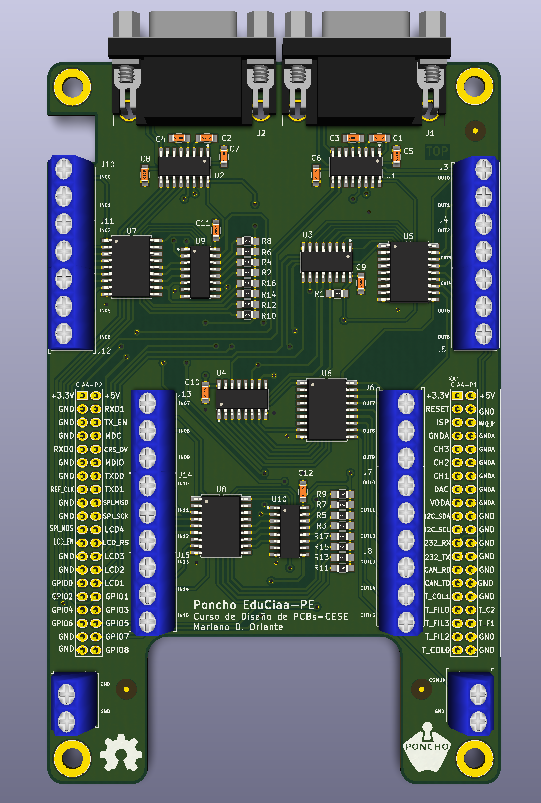
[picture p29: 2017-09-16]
Expansor_puertos/Docs/Vistas 3D/EduCiaa_PE (3D Front View).png

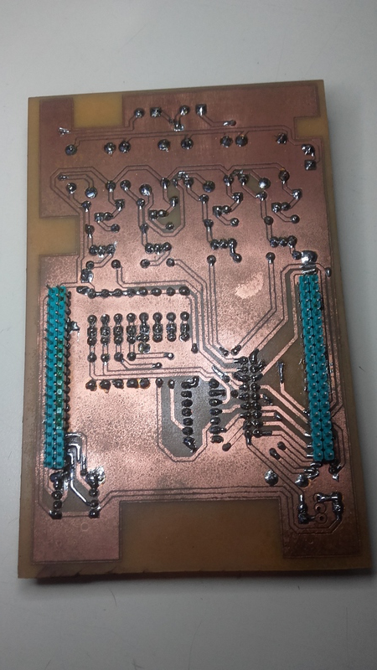
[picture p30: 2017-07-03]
Sumo_Robot/doc/fotos/LG_20170701_154517.jpg

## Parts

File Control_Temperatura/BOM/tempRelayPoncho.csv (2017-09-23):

Source: | /home/fran/CIAA/Repositorios/TPpcbdesign/tempRelayPoncho.sch
Date: | Tue 08 Aug 2017 09:52:31 PM ART
Tool: | Eeschema 4.0.6-e0-6349~53~ubuntu16.04.1
Generator: | /home/fran/CIAA/Repositorios/TPpcbdesign/tools/bom_csv_grouped_by_value.py
Component Count: | 37
Individual Components:
Item | Qty | Reference(s) | Value | LibPart | Footprint | Datasheet | Descripcion | Description | Digikey# | Manf | Manf# | Mouser#
 |  | C1 | 10u | TempRelay:C | footprints:C_0805_HandSoldering | c02e-2905.pdf |  | Multilayer Ceramic Capacitors MLCC - SMD/SMT 0805 10uF 6.3volts X5R 20% | 490-1718-1-ND | Murata | GRM21BR60J106ME19L | 81-GRM21BR60J106ME19
 |  | C2 | 100n | TempRelay:C | footprints:C_0805_HandSoldering | c02e-2905.pdf |  | Multilayer Ceramic Capacitors MLCC - SMD/SMT 0.1uF 10Volts U2J 5% | 490-11592-1-ND | Murata | GRM21B7U1A104JA01L | 81-GRM21B7U1A104JA1L
 |  | C3 | 10u | TempRelay:C | footprints:C_0805_HandSoldering | c02e-2905.pdf |  | Multilayer Ceramic Capacitors MLCC - SMD/SMT 0805 10uF 6.3volts X5R 20% | 490-1718-1-ND | Murata | GRM21BR60J106ME19L | 81-GRM21BR60J106ME19
 |  | C4 | 10u | TempRelay:C | footprints:C_0805_HandSoldering | c02e-2905.pdf |  | Multilayer Ceramic Capacitors MLCC - SMD/SMT 0805 10uF 6.3volts X5R 20% | 490-1718-1-ND | Murata | GRM21BR60J106ME19L | 81-GRM21BR60J106ME19
 |  | C5 | 100n | TempRelay:C | footprints:C_0805_HandSoldering | c02e-2905.pdf |  | Multilayer Ceramic Capacitors MLCC - SMD/SMT 0.1uF 10Volts U2J 5% | 490-11592-1-ND | Murata | GRM21B7U1A104JA01L | 81-GRM21B7U1A104JA1L
 |  | C6 | 100n | TempRelay:C | footprints:C_0805_HandSoldering | c02e-2905.pdf |  | Multilayer Ceramic Capacitors MLCC - SMD/SMT 0.1uF 10Volts U2J 5% | 490-11592-1-ND | Murata | GRM21B7U1A104JA01L | 81-GRM21B7U1A104JA1L
 |  | D1 | RELAY_1 | TempRelay:LED_ALT | footprints:LED-0805 | qtlp630c-2.pdf |  | Red 645nm LED Indication - Discrete 1.9V 0805 (2012 Metric) | 1080-1412-2-ND | Everlight Electronics Co Ltd | QTLP630C7TR | Value
 |  | D2 | RELAY_2 | TempRelay:LED_ALT | footprints:LED-0805 | qtlp630c-2.pdf |  | Red 645nm LED Indication - Discrete 1.9V 0805 (2012 Metric) | 1080-1412-2-ND | Everlight Electronics Co Ltd | QTLP630C7TR | Value
 |  | D3 | MRA4003T3G | TempRelay:DIODE | footprints:DO-214AA(SMB) | MRA4003T3-D.PDF |  | Diode Standard 300V 1A SMA | MRA4003T3GOSTR-ND | ON Semiconductor | MRA4003T3G | Value
 |  | D4 | MRA4003T3G | TempRelay:DIODE | footprints:DO-214AA(SMB) | MRA4003T3-D.PDF |  | Diode Standard 300V 1A SMA | MRA4003T3GOSTR-ND | ON Semiconductor | MRA4003T3G | Value
 |  | D5 | SSR_OUT | TempRelay:LED_ALT | footprints:LED-0805 | qtlp630c-2.pdf |  | Red 645nm LED Indication - Discrete 1.9V 0805 (2012 Metric) | 1080-1412-2-ND | Everlight Electronics Co Ltd | QTLP630C7TR | Value
 |  | F1 | FIDUCIAL | TempRelay:FIDUCIAL | footprints:Fiducial_1mm |  | FIDUCIAL
 |  | F2 | FIDUCIAL | TempRelay:FIDUCIAL | footprints:Fiducial_1mm |  | FIDUCIAL
 |  | F3 | FIDUCIAL | TempRelay:FIDUCIAL | footprints:Fiducial_1mm |  | FIDUCIAL
 |  | J1 | Screw_Terminal_1x02 | TempRelay:Screw_Terminal_1x02 | footprints:TerminalBlock_Pheonix_MKDS1.5-2pol | MKDS Phoenix 1-5.pdf |  | 2 Position Wire to Board Terminal Block Horizontal with Board 0.138 | 277-5719-ND | Phoenix Contact | 1751248 | Value
 |  | J2 | Screw_Terminal_1x02 | TempRelay:Screw_Terminal_1x02 | footprints:TerminalBlock_Pheonix_MKDS1.5-2pol | MKDS Phoenix 1-5.pdf |  | 2 Position Wire to Board Terminal Block Horizontal with Board 0.138 | 277-5719-ND | Phoenix Contact | 1751248 | Value
 |  | J3 | Screw_Terminal_1x02 | TempRelay:Screw_Terminal_1x02 | footprints:TerminalBlock_Pheonix_MKDS1.5-2pol | MKDS Phoenix 1-5.pdf |  | 2 Position Wire to Board Terminal Block Horizontal with Board 0.138 | 277-5719-ND | Phoenix Contact | 1751248 | Value
 |  | J4 | Screw_Terminal_1x02 | TempRelay:Screw_Terminal_1x02 | footprints:TerminalBlock_Pheonix_MKDS1.5-2pol | MKDS Phoenix 1-5.pdf |  | 2 Position Wire to Board Terminal Block Horizontal with Board 0.138" (3.50mm) Through Hole | 277-5719-ND | Phoenix Contact | 1751248 | Value
 |  | J5 | Screw_Terminal_1x02 | TempRelay:Screw_Terminal_1x02 | footprints:TerminalBlock_Pheonix_MKDS1.5-2pol | MKDS Phoenix 1-5.pdf |  | 2 Position Wire to Board Terminal Block Horizontal with Board 0.138" (3.50mm) Through Hole | 277-5719-ND | Phoenix Contact | 1751248 | Value
 |  | J6 | Screw_Terminal_1x02 | TempRelay:Screw_Terminal_1x02 | footprints:TerminalBlock_Pheonix_MKDS1.5-2pol | MKDS Phoenix 1-5.pdf |  | 2 Position Wire to Board Terminal Block Horizontal with Board 0.138" (3.50mm) Through Hole | 277-5719-ND | Phoenix Contact | 1751248 | Value
 |  | Q1 | MMBT3904 | TempRelay:MMBT3904 | footprints:SOT23_NPN | 2N3904-82270.pdf |  | Bipolar (BJT) Transistor NPN 40V 200mA 300MHz 350mW | MMBT3904FSCT-ND | ON Semiconductor | MMBT3904 | Value
 |  | Q2 | MMBT3904 | TempRelay:MMBT3904 | footprints:SOT23_NPN | 2N3904-82270.pdf |  | Bipolar (BJT) Transistor NPN 40V 200mA 300MHz 350mW | MMBT3904FSCT-ND | ON Semiconductor | MMBT3904 | Value
 |  | R1 | 10k | TempRelay:R | footprints:R_0805_HandSoldering | Yageo_08112016_RC0805-968729.pdf |  | Thick Film Resistors - SMD 10K OHM 1% | 311-10.0KCRCT-ND | Yageo | RC0805FR-0710KL | 603-RC0805FR-0710KL
 |  | R2 | 1k | TempRelay:R | footprints:R_0805_HandSoldering | ../Datasheets/Yageo_08112016_RC0805-968729.pdf |  | Thick Film Resistors - SMD 1K OHM 1% | 311-1.00KCRCT-ND | Yageo | RC0805FR-071KL | 603-RC0805FR-071KL
 |  | R3 | 1k | TempRelay:R | footprints:R_0805_HandSoldering | ../Datasheets/Yageo_08112016_RC0805-968729.pdf |  | Thick Film Resistors - SMD 1K OHM 1% | 311-1.00KCRCT-ND | Yageo | RC0805FR-071KL | 603-RC0805FR-071KL
 |  | R4 | 1k | TempRelay:R | footprints:R_0805_HandSoldering | ../Datasheets/Yageo_08112016_RC0805-968729.pdf |  | Thick Film Resistors - SMD 1K OHM 1% | 311-1.00KCRCT-ND | Yageo | RC0805FR-071KL | 603-RC0805FR-071KL
 |  | R5 | 1k | TempRelay:R | footprints:R_0805_HandSoldering | ../Datasheets/Yageo_08112016_RC0805-968729.pdf |  | Thick Film Resistors - SMD 1K OHM 1% | 311-1.00KCRCT-ND | Yageo | RC0805FR-071KL | 603-RC0805FR-071KL
 |  | R6 | 10k | TempRelay:R | footprints:R_0805_HandSoldering | ../Datasheets/Yageo_08112016_RC0805-968729.pdf |  | Thick Film Resistors - SMD 10K OHM 1% | 311-10.0KCRCT-ND | Yageo | RC0805FR-0710KL | 603-RC0805FR-0710KL
 |  | R7 | 10k | TempRelay:R | footprints:R_0805_HandSoldering | ../Datasheets/Yageo_08112016_RC0805-968729.pdf |  | Thick Film Resistors - SMD 10K OHM 1% | 311-10.0KCRCT-ND | Yageo | RC0805FR-0710KL | 603-RC0805FR-0710KL
 |  | R8 | 1k | TempRelay:R | footprints:R_0805_HandSoldering | ../Datasheets/Yageo_08112016_RC0805-968729.pdf |  | Thick Film Resistors - SMD 1K OHM 1% | 311-1.00KCRCT-ND | Yageo | RC0805FR-071KL | 603-RC0805FR-071KL
 |  | R9 | 100 | TempRelay:R | footprints:R_0805_HandSoldering | ../Datasheets/Yageo_08112016_RC0805-968729.pdf |  | 1Thick Film Resistors - SMD 100 OHM 1% | 311-100CRCT-ND | Yageo | RC0805FR-07100RL | 603-RC0805FR-07100RL
 |  | U1 | NUP2105LT1G | TempRelay:NUP2105LT1G | footprints:SOT23_NPN | NUP2105L-D-771105.pdf |  | TVS DIODE 24VWM 44VC | NUP2105LT1GOSCT-ND | ON Semiconductor | NUP2105LT1G | Value
 |  | U2 | MAX31855KASA+ | TempRelay:MAX31855KASA+ | footprints:SOIC-8 | MAX31855.pdf |  | Sensor Interface Thermocouple To Digital Converter | MAX31855KASA+-ND | Maxim Integrated | MAX31855KASA+ | Value
 |  | U3 | MCP601R | TempRelay:MCP601R | footprints:SOT-23-5_HandSoldering | MCP601,2,3,4.pdf |  | Operational Amplifiers - Op Amps Single 2.7V | Value | Microchip Technology | MCP601T-I/OT | 579-MCP601T-I/OT
 |  | U4 | G5LE-1A-5DC | TempRelay:G5LE-1A-5DC | footprints:Relay_G5LE-1A-5DC-5mm | G5LE_0813-267607.pdf |  | General Purpose Relays SPST-NO 5VDC 79.4mA | Z3115-ND | Omron Electronics | G5LE-1A DC5 | 653-G5LE-1ADC5
 |  | U6 | G5LE-1A-5DC | TempRelay:G5LE-1A-5DC | footprints:Relay_G5LE-1A-5DC-5mm | G5LE_0813-267607.pdf |  | General Purpose Relays SPST-NO 5VDC 79.4mA | Z3115-ND | Omron Electronics | G5LE-1A DC5 | 653-G5LE-1ADC5
 |  | XA1 | Conn_Poncho2P_2x_20x2 | TempRelay:Conn_Poncho2P_2x_20x2 | footprints:Conn_Poncho_Completo
Collated Components:
Item | Qty | Reference(s) | Value | LibPart | Footprint | Datasheet | Descripcion | Description | Digikey# | Manf | Manf# | Mouser#
1 | 3 | C1, C3, C4 | 10u | TempRelay:C | footprints:C_0805_HandSoldering | c02e-2905.pdf |  | Multilayer Ceramic Capacitors MLCC - SMD/SMT 0805 10uF 6.3volts X5R 20% | 490-1718-1-ND | Murata | GRM21BR60J106ME19L | 81-GRM21BR60J106ME19
2 | 3 | C2, C5, C6 | 100n | TempRelay:C | footprints:C_0805_HandSoldering | c02e-2905.pdf |  | Multilayer Ceramic Capacitors MLCC - SMD/SMT 0.1uF 10Volts U2J 5% | 490-11592-1-ND | Murata | GRM21B7U1A104JA01L | 81-GRM21B7U1A104JA1L
3 | 1 | D1 | RELAY_1 | TempRelay:LED_ALT | footprints:LED-0805 | qtlp630c-2.pdf |  | Red 645nm LED Indication - Discrete 1.9V 0805 (2012 Metric) | 1080-1412-2-ND | Everlight Electronics Co Ltd | QTLP630C7TR | Value
4 | 1 | D2 | RELAY_2 | TempRelay:LED_ALT | footprints:LED-0805 | qtlp630c-2.pdf |  | Red 645nm LED Indication - Discrete 1.9V 0805 (2012 Metric) | 1080-1412-2-ND | Everlight Electronics Co Ltd | QTLP630C7TR | Value
5 | 2 | D3, D4 | MRA4003T3G | TempRelay:DIODE | footprints:DO-214AA(SMB) | MRA4003T3-D.PDF |  | Diode Standard 300V 1A SMA | MRA4003T3GOSTR-ND | ON Semiconductor | MRA4003T3G | Value
6 | 1 | D5 | SSR_OUT | TempRelay:LED_ALT | footprints:LED-0805 | qtlp630c-2.pdf |  | Red 645nm LED Indication - Discrete 1.9V 0805 (2012 Metric) | 1080-1412-2-ND | Everlight Electronics Co Ltd | QTLP630C7TR | Value
7 | 3 | F1, F2, F3 | FIDUCIAL | TempRelay:FIDUCIAL | footprints:Fiducial_1mm |  | FIDUCIAL
8 | 6 | J1, J2, J3, J4, J5, J6 | Screw_Terminal_1x02 | TempRelay:Screw_Terminal_1x02 | footprints:TerminalBlock_Pheonix_MKDS1.5-2pol | MKDS Phoenix 1-5.pdf |  | 2 Position Wire to Board Terminal Block Horizontal with Board 0.138 | 277-5719-ND | Phoenix Contact | 1751248 | Value
9 | 2 | Q1, Q2 | MMBT3904 | TempRelay:MMBT3904 | footprints:SOT23_NPN | 2N3904-82270.pdf |  | Bipolar (BJT) Transistor NPN 40V 200mA 300MHz 350mW | MMBT3904FSCT-ND | ON Semiconductor | MMBT3904 | Value
10 | 3 | R1, R6, R7 | 10k | TempRelay:R | footprints:R_0805_HandSoldering | Yageo_08112016_RC0805-968729.pdf |  | Thick Film Resistors - SMD 10K OHM 1% | 311-10.0KCRCT-ND | Yageo | RC0805FR-0710KL | 603-RC0805FR-0710KL
11 | 5 | R2, R3, R4, R5, R8 | 1k | TempRelay:R | footprints:R_0805_HandSoldering | ../Datasheets/Yageo_08112016_RC0805-968729.pdf |  | Thick Film Resistors - SMD 1K OHM 1% | 311-1.00KCRCT-ND | Yageo | RC0805FR-071KL | 603-RC0805FR-071KL
12 | 1 | R9 | 100 | TempRelay:R | footprints:R_0805_HandSoldering | ../Datasheets/Yageo_08112016_RC0805-968729.pdf |  | 1Thick Film Resistors - SMD 100 OHM 1% | 311-100CRCT-ND | Yageo | RC0805FR-07100RL | 603-RC0805FR-07100RL
13 | 1 | U1 | NUP2105LT1G | TempRelay:NUP2105LT1G | footprints:SOT23_NPN | NUP2105L-D-771105.pdf |  | TVS DIODE 24VWM 44VC | NUP2105LT1GOSCT-ND | ON Semiconductor | NUP2105LT1G | Value
14 | 1 | U2 | MAX31855KASA+ | TempRelay:MAX31855KASA+ | footprints:SOIC-8 | MAX31855.pdf |  | Sensor Interface Thermocouple To Digital Converter | MAX31855KASA+-ND | Maxim Integrated | MAX31855KASA+ | Value
15 | 1 | U3 | MCP601R | TempRelay:MCP601R | footprints:SOT-23-5_HandSoldering | MCP601,2,3,4.pdf |  | Operational Amplifiers - Op Amps Single 2.7V | Value | Microchip Technology | MCP601T-I/OT | 579-MCP601T-I/OT
16 | 2 | U4, U6 | G5LE-1A-5DC | TempRelay:G5LE-1A-5DC | footprints:Relay_G5LE-1A-5DC-5mm | G5LE_0813-267607.pdf |  | General Purpose Relays SPST-NO 5VDC 79.4mA | Z3115-ND | Omron Electronics | G5LE-1A DC5 | 653-G5LE-1ADC5
17 | 1 | XA1 | Conn_Poncho2P_2x_20x2 | TempRelay:Conn_Poncho2P_2x_20x2 | footprints:Conn_Poncho_Completo

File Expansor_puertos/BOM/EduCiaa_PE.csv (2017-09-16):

Source: | C:/Users/DELL/Desktop/DiseÃ±oCircuitos/EDUCIAA_PE/EduCiaa_PE.sch
Date: | 15-07-17 17:03
Tool: | Eeschema 4.0.6
Generator: | C:/Users/DELL/Desktop/DiseñoCircuitos/EDUCIAA_PE/tools/bom_csv_grouped_by_value.py
Component Count: | 59
Individual Components:
Item | Qty | Reference(s) | Value | LibPart | Footprint | Datasheet | Descripcion | Digikey# | Manf | Manf#
 |  | C1 | 100nF | EduCiaaPE:C | Footprints:C_0805_HandSoldering | UPY-GPHC_X7R_6.3V-to-50V_18.pdf |  | 311-1142-1-ND | Yageo | CC0805KRX7R7BB104
 |  | C2 | 100nF | EduCiaaPE:C | Footprints:C_0805_HandSoldering | UPY-GPHC_X7R_6.3V-to-50V_18.pdf |  | 311-1142-1-ND | Yageo | CC0805KRX7R7BB104
 |  | C3 | 100nF | EduCiaaPE:C | Footprints:C_0805_HandSoldering | UPY-GPHC_X7R_6.3V-to-50V_18.pdf |  | 311-1142-1-ND | Yageo | CC0805KRX7R7BB104
 |  | C4 | 100nF | EduCiaaPE:C | Footprints:C_0805_HandSoldering | UPY-GPHC_X7R_6.3V-to-50V_18.pdf |  | 311-1142-1-ND | Yageo | CC0805KRX7R7BB104
 |  | C5 | 100nF | EduCiaaPE:C | Footprints:C_0805_HandSoldering | UPY-GPHC_X7R_6.3V-to-50V_18.pdf |  | 311-1142-1-ND | Yageo | CC0805KRX7R7BB104
 |  | C6 | 100nF | EduCiaaPE:C | Footprints:C_0805_HandSoldering | UPY-GPHC_X7R_6.3V-to-50V_18.pdf |  | 311-1142-1-ND | Yageo | CC0805KRX7R7BB104
 |  | C7 | 100nF | EduCiaaPE:C | Footprints:C_0805_HandSoldering | UPY-GPHC_X7R_6.3V-to-50V_18.pdf |  | 311-1142-1-ND | Yageo | CC0805KRX7R7BB104
 |  | C8 | 100nF | EduCiaaPE:C | Footprints:C_0805_HandSoldering | UPY-GPHC_X7R_6.3V-to-50V_18.pdf |  | 311-1142-1-ND | Yageo | CC0805KRX7R7BB104
 |  | C9 | 100nF | EduCiaaPE:C | Footprints:C_0805_HandSoldering | UPY-GPHC_X7R_6.3V-to-50V_18.pdf |  | 311-1142-1-ND | Yageo | CC0805KRX7R7BB104
 |  | C10 | 100nF | EduCiaaPE:C | Footprints:C_0805_HandSoldering | UPY-GPHC_X7R_6.3V-to-50V_18.pdf |  | 311-1142-1-ND | Yageo | CC0805KRX7R7BB104
 |  | C11 | 100nF | EduCiaaPE:C | Footprints:C_0805_HandSoldering | UPY-GPHC_X7R_6.3V-to-50V_18.pdf |  | 311-1142-1-ND | Yageo | CC0805KRX7R7BB104
 |  | C12 | 100nF | EduCiaaPE:C | Footprints:C_0805_HandSoldering | UPY-GPHC_X7R_6.3V-to-50V_18 |  | 311-1142-1-ND | Yageo | CC0805KRX7R7BB104
 |  | F1 | FIDUCIAL | EduCiaaPE:FIDUCIAL | Footprints:Fiducial_1mm |  | FIDUCIAL
 |  | F2 | FIDUCIAL | EduCiaaPE:FIDUCIAL | Footprints:Fiducial_1mm |  | FIDUCIAL
 |  | F3 | FIDUCIAL | EduCiaaPE:FIDUCIAL | Footprints:Fiducial_1mm |  | FIDUCIAL
 |  | J1 | DB9 | EduCiaaPE:DB9 | Footprints:DB9_F_TH | ENG_CD_1734354_A1.pdf |  | A35107-ND | TE Connectivity AMP Connectors | 1734354-1
 |  | J2 | DB9 | EduCiaaPE:DB9 | Footprints:DB9_F_TH | ENG_CD_1734354_A1.pdf |  | A35107-ND | TE Connectivity AMP Connectors | 1734354-1
 |  | J3 | TB_1X2 | EduCiaaPE:TB_1X2 | Footprints:bornier2 | osttcxx2162.pdf |  | ED2609-ND | On Shore Technology Inc. | OSTTC022162
 |  | J4 | TB_1X2 | EduCiaaPE:TB_1X2 | Footprints:bornier2 | osttcxx2162.pdf |  | ED2609-ND | On Shore Technology Inc. | OSTTC022162
 |  | J5 | TB_1X3 | EduCiaaPE:TB_1X3 | Footprints:bornier3 | osttcxx2162.pdf |  | ED2610-ND | On Shore Technology Inc. | OSTTC032162
 |  | J6 | TB_1X3 | EduCiaaPE:TB_1X3 | Footprints:bornier3 | osttcxx2162.pdf |  | ED2610-ND | On Shore Technology Inc. | OSTTC032162
 |  | J7 | TB_1X3 | EduCiaaPE:TB_1X3 | Footprints:bornier3 | osttcxx2162.pdf |  | ED2610-ND | On Shore Technology Inc. | OSTTC032162
 |  | J8 | TB_1X3 | EduCiaaPE:TB_1X3 | Footprints:bornier3 | osttcxx2162.pdf |  | ED2610-ND | On Shore Technology Inc. | OSTTC032162
 |  | J9 | TB_1X2 | EduCiaaPE:TB_1X2 | Footprints:bornier2 | osttcxx2162.pdf |  | ED2609-ND | On Shore Technology Inc. | OSTTC022162
 |  | J10 | TB_1X2 | EduCiaaPE:TB_1X2 | Footprints:bornier2 | osttcxx2162.pdf |  | ED2609-ND | On Shore Technology Inc. | OSTTC022162
 |  | J11 | TB_1X2 | EduCiaaPE:TB_1X2 | Footprints:bornier2 | osttcxx2162.pdf |  | ED2609-ND | On Shore Technology Inc. | OSTTC022162
 |  | J12 | TB_1X3 | EduCiaaPE:TB_1X3 | Footprints:bornier3 | osttcxx2162.pdf |  | ED2610-ND | On Shore Technology Inc. | OSTTC032162
 |  | J13 | TB_1X3 | EduCiaaPE:TB_1X3 | Footprints:bornier3 | osttcxx2162.pdf |  | ED2610-ND | On Shore Technology Inc. | OSTTC032162
 |  | J14 | TB_1X3 | EduCiaaPE:TB_1X3 | Footprints:bornier3 | osttcxx2162.pdf |  | ED2610-ND | On Shore Technology Inc. | OSTTC032162
 |  | J15 | TB_1X3 | EduCiaaPE:TB_1X3 | Footprints:bornier3 | osttcxx2162.pdf |  | ED2610-ND | On Shore Technology Inc. | OSTTC032162
 |  | J16 | TB_1X2 | EduCiaaPE:TB_1X2 | Footprints:bornier2 | osttcxx2162.pdf |  | ED2609-ND | On Shore Technology Inc. | OSTTC022162
 |  | R1 | 10K | EduCiaaPE:R | Footprints:R_0805_HandSoldering | PYu-R_INT-thick_7.pdf |  | 311-10KARCT-ND | Yageo | RC0805JR-0710KL
 |  | R2 | 10K | EduCiaaPE:R | Footprints:R_0805_HandSoldering | PYu-R_INT-thick_7.pdf |  | 311-10KARCT-ND | Yageo | RC0805JR-0710KL
 |  | R3 | 10K | EduCiaaPE:R | Footprints:R_0805_HandSoldering | PYu-R_INT-thick_7.pdf |  | 311-10KARCT-ND | Yageo | RC0805JR-0710KL
 |  | R4 | 10K | EduCiaaPE:R | Footprints:R_0805_HandSoldering | PYu-R_INT-thick_7.pdf |  | 311-10KARCT-ND | Yageo | RC0805JR-0710KL
 |  | R5 | 10K | EduCiaaPE:R | Footprints:R_0805_HandSoldering | PYu-R_INT-thick_7.pdf |  | 311-10KARCT-ND | Yageo | RC0805JR-0710KL
 |  | R6 | 10K | EduCiaaPE:R | Footprints:R_0805_HandSoldering | PYu-R_INT-thick_7.pdf |  | 311-10KARCT-ND | Yageo | RC0805JR-0710KL
 |  | R7 | 10K | EduCiaaPE:R | Footprints:R_0805_HandSoldering | PYu-R_INT-thick_7.pdf |  | 311-10KARCT-ND | Yageo | RC0805JR-0710KL
 |  | R8 | 10K | EduCiaaPE:R | Footprints:R_0805_HandSoldering | PYu-R_INT-thick_7.pdf |  | 311-10KARCT-ND | Yageo | RC0805JR-0710KL
 |  | R9 | 10K | EduCiaaPE:R | Footprints:R_0805_HandSoldering | PYu-R_INT-thick_7.pdf |  | 311-10KARCT-ND | Yageo | RC0805JR-0710KL
 |  | R10 | 10K | EduCiaaPE:R | Footprints:R_0805_HandSoldering | PYu-R_INT-thick_7.pdf |  | 311-10KARCT-ND | Yageo | RC0805JR-0710KL
 |  | R11 | 10K | EduCiaaPE:R | Footprints:R_0805_HandSoldering | PYu-R_INT-thick_7.pdf |  | 311-10KARCT-ND | Yageo | RC0805JR-0710KL
 |  | R12 | 10K | EduCiaaPE:R | Footprints:R_0805_HandSoldering | PYu-R_INT-thick_7.pdf |  | 311-10KARCT-ND | Yageo | RC0805JR-0710KL
 |  | R13 | 10K | EduCiaaPE:R | Footprints:R_0805_HandSoldering | PYu-R_INT-thick_7.pdf |  | 311-10KARCT-ND | Yageo | RC0805JR-0710KL
 |  | R14 | 10K | EduCiaaPE:R | Footprints:R_0805_HandSoldering | PYu-R_INT-thick_7.pdf |  | 311-10KARCT-ND | Yageo | RC0805JR-0710KL
 |  | R15 | 10K | EduCiaaPE:R | Footprints:R_0805_HandSoldering | PYu-R_INT-thick_7.pdf |  | 311-10KARCT-ND | Yageo | RC0805JR-0710KL
 |  | R16 | 10K | EduCiaaPE:R | Footprints:R_0805_HandSoldering | PYu-R_INT-thick_7.pdf |  | 311-10KARCT-ND | Yageo | RC0805JR-0710KL
 |  | R17 | 10K | EduCiaaPE:R | Footprints:R_0805_HandSoldering | PYu-R_INT-thick_7.pdf |  | 311-10KARCT-ND | Yageo | RC0805JR-0710KL
 |  | U1 | MAX3232 | EduCiaaPE:MAX3232 | Footprints:SOIC-16N | max3232.pdf |  | 296-13095-1-ND | Texas Instruments | MAX3232CDWR
 |  | U2 | MAX3232 | EduCiaaPE:MAX3232 | Footprints:SOIC-16N | max3232.pdf |  | 296-13095-1-ND | Texas Instruments | MAX3232CDWR
 |  | U3 | 74HC595 | EduCiaaPE:74HC595 | Footprints:SOIC-16N | MM74HC595.pdf |  | MM74HC595MXCT-ND | Fairchild/ON Semiconductor | MM74HC595MX
 |  | U4 | 74HC595 | EduCiaaPE:74HC595 | Footprints:SOIC-16N | MM74HC595.pdf |  | MM74HC595MXCT-ND | Fairchild/ON Semiconductor | MM74HC595MX
 |  | U5 | ULN2803A | EduCiaaPE:ULN2803A | Footprints:SOIC-18 | uln2803a.pdf |  | 296-15777-1-ND | Texas Instruments | ULN2803ADWR
 |  | U6 | ULN2803A | EduCiaaPE:ULN2803A | Footprints:SOIC-18 | uln2803a.pdf |  | 296-15777-1-ND | Texas Instruments | ULN2803ADWR
 |  | U7 | ULN2803A | EduCiaaPE:ULN2803A | Footprints:SOIC-18 | uln2803a.pdf |  | 296-15777-1-ND | Texas Instruments | ULN2803ADWR
 |  | U8 | ULN2803A | EduCiaaPE:ULN2803A | Footprints:SOIC-18 | uln2803a.pdf |  | 296-15777-1-ND | Texas Instruments | ULN2803ADWR
 |  | U9 | 74HC165 | EduCiaaPE:74HC165 | Footprints:SOIC-16N | sn74hc165.pdf |  | 296-8249-5-ND | Texas Instruments | SN74HC165D
 |  | U10 | 74HC165 | EduCiaaPE:74HC165 | Footprints:SOIC-16N | sn74hc165.pdf |  | 296-8249-5-ND | Texas Instruments | SN74HC165D
 |  | XA1 | Conn_Poncho2P_2x_20x2 | EduCiaaPE:Conn_Poncho2P_2x_20x2 | Poncho_Esqueleto:Conn_Poncho_Completo
Collated Components:
Item | Qty | Reference(s) | Value | LibPart | Footprint | Datasheet | Descripcion | Digikey# | Manf | Manf#
1 | 12 | C1, C2, C3, C4, C5, C6, C7, C8, C9, C10, C11, C12 | 100nF | EduCiaaPE:C | Footprints:C_0805_HandSoldering | UPY-GPHC_X7R_6.3V-to-50V_18.pdf |  | 311-1142-1-ND | Yageo | CC0805KRX7R7BB104
2 | 3 | F1, F2, F3 | FIDUCIAL | EduCiaaPE:FIDUCIAL | Footprints:Fiducial_1mm |  | FIDUCIAL
3 | 2 | J1, J2 | DB9 | EduCiaaPE:DB9 | Footprints:DB9_F_TH | ENG_CD_1734354_A1.pdf |  | A35107-ND | TE Connectivity AMP Connectors | 1734354-1
4 | 6 | J3, J4, J9, J10, J11, J16 | TB_1X2 | EduCiaaPE:TB_1X2 | Footprints:bornier2 | osttcxx2162.pdf |  | ED2609-ND | On Shore Technology Inc. | OSTTC022162
5 | 8 | J5, J6, J7, J8, J12, J13, J14, J15 | TB_1X3 | EduCiaaPE:TB_1X3 | Footprints:bornier3 | osttcxx2162.pdf |  | ED2610-ND | On Shore Technology Inc. | OSTTC032162
6 | 17 | R1, R2, R3, R4, R5, R6, R7, R8, R9, R10, R11, R12, R13, R14, R15, R16, R17 | 10K | EduCiaaPE:R | Footprints:R_0805_HandSoldering | PYu-R_INT-thick_7.pdf |  | 311-10KARCT-ND | Yageo | RC0805JR-0710KL
7 | 2 | U1, U2 | MAX3232 | EduCiaaPE:MAX3232 | Footprints:SOIC-16N | max3232.pdf |  | 296-13095-1-ND | Texas Instruments | MAX3232CDWR
8 | 2 | U3, U4 | 74HC595 | EduCiaaPE:74HC595 | Footprints:SOIC-16N | MM74HC595.pdf |  | MM74HC595MXCT-ND | Fairchild/ON Semiconductor | MM74HC595MX
9 | 4 | U5, U6, U7, U8 | ULN2803A | EduCiaaPE:ULN2803A | Footprints:SOIC-18 | uln2803a.pdf |  | 296-15777-1-ND | Texas Instruments | ULN2803ADWR
10 | 2 | U9, U10 | 74HC165 | EduCiaaPE:74HC165 | Footprints:SOIC-16N | sn74hc165.pdf |  | 296-8249-5-ND | Texas Instruments | SN74HC165D
11 | 1 | XA1 | Conn_Poncho2P_2x_20x2 | EduCiaaPE:Conn_Poncho2P_2x_20x2 | Poncho_Esqueleto:Conn_Poncho_Completo

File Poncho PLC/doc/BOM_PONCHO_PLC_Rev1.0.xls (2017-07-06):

Lista de materiales |  |  |  | DISEÑO ASISTIDO Y SIMULACIÓN ELECTRÓNICA
Proyecto: |  | PONCHO PLC
Curso: |  | PROYECTO CIAA
Año: |  | 2017
Autor: |  | MARIANO BUSTOS
Moneda: |  | U$D O $ | Tipo de cambio:
 | CANT. | References | Value |  | Footprint |  | Unit Price | Subtotal | Proveedor
1 | 1 | XA1 | Conn_Poncho2P_2x_20x2 |  | Conector_EDU_CIAA |  |  | 0.000
2 | 4 | K1,K3,K4,K2 | RELAY_C |  | Relay_C |  | 15.000 | 60.000
3 | 4 | U6,U5,U4,U3 | MCP1416 |  | SOT-23-5 |  |  | 0.000
4 | 2 | U2,U1 | TLP627-4 |  | DIP_16-300 |  |  | 0.000
5 | 4 | TH4,TH3,TH2,TH1 | PTS12066V100 |  | PTC_1210 |  |  | 0.000
6 | 8 | R45,R44,R41,R40,R37,R36,R35,R34 | 330 |  | R_1206 |  |  | 0.000
7 | 15 | R43,R42,R39,R38,R33,R32,R31,R30,R29,R27,R25,R23,R21,R19,R17 | 100k |  | R_1206 |  |  | 0.000
8 | 7 | R28,R26,R24,R22,R20,R18,R16 | 2.2k |  | R_1206 |  |  | 0.000
9 | 7 | R15,R14,R13,R12,R11,R10,R9 | 4.7k |  | R_1206 |  |  | 0.000
10 | 7 | R8,R7,R6,R5,R4,R3,R2 | 3.3k |  | R_1206 |  |  | 0.000
11 | 1 | R1 | 100 |  | R_1206 |  |  | 0.000
12 | 4 | Q8,Q7,Q6,Q5 | 2N7002 |  | SOT23 |  |  | 0.000
13 | 4 | Q4,Q3,Q2,Q1 | FQT13N06L |  | SOT-223 |  |  | 0.000
14 | 4 | JP4,JP3,JP2,JP1 | Jumper |  | Pin_strip_2 |  |  | 0.000
15 | 1 | J2 | RS-232 |  | HEADER-4H |  |  | 0.000
16 | 1 | DS1 | WC1602A |  | LCD_16x2 |  |  | 0.000
17 | 4 | D18,D15,D14,D19 | LL4148 |  | SOD80C |  |  | 0.000
18 | 15 | D17,D16,D13,D12,D11,D10,D9,D8,D7,D6,D5,D4,D3,D2,D1 | LED red |  | LED_1206 |  |  | 0.000
19 | 4 | C8,C7,C6,C5 | 1uF |  | C_1206 |  |  | 0.000
20 | 4 | C4,C3,C2,C1 | 100nF |  | C_1206 |  |  | 0.000
21 | 6 | J8,J10,J11,J9,J4,J3 | TB_1X3 |  | BORNERA3 |  |  | 0.000
22 | 3 | J7,J6,J5 | TB_1X2 |  | BORNERA2 |  |  | 0.000
23 | 1 | RV1 | 10K |  | TRIMER_V |  |  | 0.000
24 | 1 | J1 | I2C |  | pin_strip_4 |  |  | 0.000
25 |  |  |  |  |  |  |  | 0.000
26 |  |  |  |  |  |  |  | 0.000
27 |  |  |  |  |  |  |  | 0.000
28 |  |  |  |  |  |  |  | 0.000
29 |  |  |  |  |  |  |  | 0.000
30 |  |  |  |  |  |  |  | 0.000
 |  |  |  |  |  | COSTO TOTAL: |  | 60
 |  | Notas

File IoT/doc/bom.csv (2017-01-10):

Id | Designator | Package | Quantity | Designation | Supplier and ref
1 | XA1 | Conn_Poncho_Mediano | 1 | Conn_Poncho2P_2x_20x2
2 | U5,U4 | Relay5vSI | 2 | RELAY
3 | D6,D1,D2,D7 | Diode_DO-35_SOD27_Horizontal_RM10 | 4 | 1N4007
4 | D3 | Diode_DO-35_SOD27_Horizontal_RM10 | 1 | 1N4728A
5 | C1,C4,C5 | C_Disc_D6_P5 | 3 | 100nF
6 | C2,C3,C6 | C_Radial_D5_L11_P2 | 3 | 2.2uF
7 | D4,D5,D8 | LED-3MM | 3 | LED
8 | J1 | bornier3 | 1 | TB_1X3
9 | J2,J3 | bornier2 | 2 | TB_1X2
10 | R1,R2 | Resistor_Horizontal_RM7mm | 2 | 3.3k
11 | R3,R4 | Resistor_Horizontal_RM7mm | 2 | 4.7k
12 | R5,R6,R8,R9,R12,R14 | Resistor_Horizontal_RM7mm | 6 | 10k
13 | R7,R15 | Resistor_Horizontal_RM7mm | 2 | 150
14 | R10,R11 | Resistor_Horizontal_RM7mm | 2 | 330
15 | R13 | Resistor_Horizontal_RM7mm | 1 | 100k
16 | U1,U3 | DIP-6_W7.62mm_LongPads | 2 | 4N25
17 | U2 | TO-92_Rugged | 1 | LM35
18 | U6 | RN1810 | 1 | RN1810E
19 | Q1,Q2 | TO-92_Rugged | 2 | BC548
20 | MP? | Plantilla_EDU-CIAA | 1 | Plantilla_EDU-CIAA
21 | G*** | Logo_Poncho | 1 | LOGO

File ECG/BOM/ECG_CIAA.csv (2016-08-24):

Source: | /home/jorge/Escritorio/ECG CIAA/ECG_CIAA.sch
Date: | dom 07 ago 2016 18:56:07 ART
Tool: | Eeschema 4.0.2+e4-6225~38~ubuntu16.04.1-stable
Generator: | /home/jorge/Escritorio/ECG CIAA/ECGtools/bom_csv_grouped_by_value.py
Component Count: | 34
Individual Components:
Item | Qty | Reference(s) | Value | LibPart | Footprint | Datasheet | Degikey# | Descripcion | Digikey# | Manf | Manf#
 |  | C1 | 1nF | device:C | ECG:C_0805 |  |  |  | 732-7813-2-ND | Wurth | 885012007008
 |  | C2 | 10nF | device:C | ECG:C_0805 |  |  |  | 732-8021-2-ND | Wurth | 732-8018-2-ND
 |  | C3 | 1.5nF | device:C | ECG:C_0805 |  |  |  | 732-8018-2-ND | Wurth | 885012207008
 |  | C4 | 0.33uF | device:C | ECG:C_0805 |  |  |  | 732-7651-2-ND | Wurth | 885012207019
 |  | C5 | 0.33uF | device:C | ECG:C_0805 |  |  |  | 732-7651-2-ND | Wurth | 885012207019
 |  | C6 | 0.1uF | device:C | ECG:C_0805 |  |  |  | 399-7999-2-ND | Kamet | C0805C104K8RACTU
 |  | C7 | 0.1uF | device:C | ECG:C_0805 |  |  |  | 399-7999-2-ND | Kamet | C0805C104K8RACTU
 |  | D1 | LED | device:LED | ECG:LED_0805 |  |  |  | 475-1410-2-ND | OSRAM | LG R971-KN-1
 |  | F1 | FIDUCIAL | ej2cese:FIDUCIAL | ECG:Fiducial_1mm |  |  | FIDUCIAL
 |  | F2 | FIDUCIAL | ej2cese:FIDUCIAL | ECG:Fiducial_1mm |  |  | FIDUCIAL
 |  | F3 | FIDUCIAL | ej2cese:FIDUCIAL | ECG:Fiducial_1mm |  |  | FIDUCIAL
 |  | F4 | FIDUCIAL | ej2cese:FIDUCIAL | ECG:Fiducial_1mm |  |  | FIDUCIAL
 |  | P1 | CONN_01X03 | conn:CONN_01X03 | Connect:bornier3 | http://www.on-shore.com/wp-content/uploads/2015/09/osttcxx0162.pdf |  |  | ED2601-ND | OSTT | OSTTC030152
 |  | P2 | Conn_Poncho2P_2x_20x2 | ej2cese:Conn_Poncho2P_2x_20x2 | ej2cese:Conn_Poncho_Derecha | http://portal.fciconnect.com/Comergent//fci/drawing/57102.pdf |  |  | 609-2589-ND | FCI | 57102
 |  | R1 | 0 | device:R | ECG:R_0805 |  |  |  | 311-0.0ARTR-ND | Yageo | RC0805JR-070RL
 |  | R2 | No montar | device:R | ECG:R_0805
 |  | R3 | 10M | device:R | ECG:R_0805 |  |  |  | RMCF0805JT10M0TR-ND | LTR | RMCF0805JT10M0
 |  | R4 | 10M | device:R | ECG:R_0805 |  |  |  | RMCF0805JT10M0TR-ND | LDR | RMCF0805JT10M0
 |  | R5 | 180K | device:R | ECG:R_0805 |  |  |  | 311-180KARTR-ND | Yageo | RC0805JR-07180KL
 |  | R6 | 180K | device:R | ECG:R_0805 |  |  |  | 311-180KARTR-ND | Yageo | RC0805JR-07180KL
 |  | R7 | 360K | device:R | ECG:R_0805 |  |  |  | 311-360KCRTR-ND | Yageo | RC0805FR-07360KL
 |  | R8 | 1M | device:R | ECG:R_0805 |  |  |  | 311-1.00MCRTR-ND | Yageo | RC0805FR-071ML
 |  | R9 | 1M | device:R | ECG:R_0805 |  |  |  | RHM1.0MBUTR-ND | Rohm | LTR10EZPJ105
 |  | R11 | 100K | device:R | ECG:R_0805 |  | 311-100KCRTR-ND |  |  | Yageo | RC0805FR-07100KL
 |  | R12 | 1M | device:R | ECG:R_0805 |  |  |  | 311-1.00MCRTR-ND | Yageo | RC0805FR-071ML
 |  | R13 | 10M | device:R | ECG:R_0805 |  |  |  | RMCF0805JT10M0TR-ND | Yageo | RMCF0805JT10M0
 |  | R14 | 10M | device:R | ECG:R_0805 |  |  |  | RMCF0805JT10M0TR-ND | Yageo | RMCF0805JT10M0
 |  | R15 | 1.4M | device:R | ECG:R_0805 |  |  |  | P1.4BTTR-ND | Panasonic | ERJ-6ENF1404V
 |  | R16 | 10M | device:R | ECG:R_0805 |  |  |  | RMCF0805JT10M0TR-ND | Yageo | RMCF0805JT10M0
 |  | R17 | 10M | device:R | ECG:R_0805 |  |  |  | RMCF0805JT10M0TR-ND | Yageo | RMCF0805JT10M0
 |  | R19 | 0 | device:R | ECG:R_0805 |  |  |  | 311-0.0ARTR-ND | Yageo | RC0805JR-070RL
 |  | R20 | No montar | device:R | ECG:R_0805
 |  | R22 | 1K | device:R | ECG:R_0805 |  |  |  | 311-1.0KARTR-ND | Yageo | RC0805JR-071KL
 |  | U1 | AD8232 | ECG_LIB:AD6232 | ECG:LFCSP_WQ | https://ay12-14.moodle.wisc.edu/prod/pluginfile.php/189091/mod_resource/content/1/AD8232.pdf |  |  | AD8232ACPZ-R7TR-ND | Analog Device | AD8232
Collated Components:
Item | Qty | Reference(s) | Value | LibPart | Footprint | Datasheet | Degikey# | Descripcion | Digikey# | Manf | Manf#
1 | 1 | C1 | 1nF | device:C | ECG:C_0805 |  |  |  | 732-7813-2-ND | Wurth | 885012007008
2 | 1 | C2 | 10nF | device:C | ECG:C_0805 |  |  |  | 732-8021-2-ND | Wurth | 732-8018-2-ND
3 | 1 | C3 | 1.5nF | device:C | ECG:C_0805 |  |  |  | 732-8018-2-ND | Wurth | 885012207008
4 | 2 | C4, C5 | 0.33uF | device:C | ECG:C_0805 |  |  |  | 732-7651-2-ND | Wurth | 885012207019
5 | 2 | C6, C7 | 0.1uF | device:C | ECG:C_0805 |  |  |  | 399-7999-2-ND | Kamet | C0805C104K8RACTU
6 | 1 | D1 | LED | device:LED | ECG:LED_0805 |  |  |  | 475-1410-2-ND | OSRAM | LG R971-KN-1
7 | 4 | F1, F2, F3, F4 | FIDUCIAL | ej2cese:FIDUCIAL | ECG:Fiducial_1mm |  |  | FIDUCIAL
8 | 1 | P1 | CONN_01X03 | conn:CONN_01X03 | Connect:bornier3 | http://www.on-shore.com/wp-content/uploads/2015/09/osttcxx0162.pdf |  |  | ED2601-ND | OSTT | OSTTC030152
9 | 1 | P2 | Conn_Poncho2P_2x_20x2 | ej2cese:Conn_Poncho2P_2x_20x2 | ej2cese:Conn_Poncho_Derecha | http://portal.fciconnect.com/Comergent//fci/drawing/57102.pdf |  |  | 609-2589-ND | FCI | 57102
10 | 2 | R1, R19 | 0 | device:R | ECG:R_0805 |  |  |  | 311-0.0ARTR-ND | Yageo | RC0805JR-070RL
11 | 2 | R2, R20 | No montar | device:R | ECG:R_0805
12 | 1 | R3 | 10M | device:R | ECG:R_0805 |  |  |  | RMCF0805JT10M0TR-ND | LTR | RMCF0805JT10M0
13 | 5 | R4, R13, R14, R16, R17 | 10M | device:R | ECG:R_0805 |  |  |  | RMCF0805JT10M0TR-ND | LDR | RMCF0805JT10M0
14 | 2 | R5, R6 | 180K | device:R | ECG:R_0805 |  |  |  | 311-180KARTR-ND | Yageo | RC0805JR-07180KL
15 | 1 | R7 | 360K | device:R | ECG:R_0805 |  |  |  | 311-360KCRTR-ND | Yageo | RC0805FR-07360KL
16 | 3 | R8, R9, R12 | 1M | device:R | ECG:R_0805 |  |  |  | 311-1.00MCRTR-ND | Yageo | RC0805FR-071ML
17 | 1 | R11 | 100K | device:R | ECG:R_0805 |  | 311-100KCRTR-ND |  |  | Yageo | RC0805FR-07100KL
18 | 1 | R15 | 1.4M | device:R | ECG:R_0805 |  |  |  | P1.4BTTR-ND | Panasonic | ERJ-6ENF1404V
19 | 1 | R22 | 1K | device:R | ECG:R_0805 |  |  |  | 311-1.0KARTR-ND | Yageo | RC0805JR-071KL
20 | 1 | U1 | AD8232 | ECG_LIB:AD6232 | ECG:LFCSP_WQ | https://ay12-14.moodle.wisc.edu/prod/pluginfile.php/189091/mod_resource/content/1/AD8232.pdf |  |  | AD8232ACPZ-R7TR-ND | Analog Device | AD8232

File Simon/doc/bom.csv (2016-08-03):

Id | Designator | Package | Quantity | Designation | Supplier and ref
1 | R14,R12,R14,R18 | Resistor_Horizontal_RM7mm | 4 | 680
2 | R13,R11,R13,R17 | Resistor_Horizontal_RM7mm | 4 | 10K
3 | R2,R1,R9,R1,R2,R3,R4,R6,R7 | Resistor_Horizontal_RM7mm | 9 | 3K3
4 | SW2,SW1,SW1,SW2,SW3,SW4,SW6,SW7 | SW_PUSH_SMALL | 8 | SW_PUSH
5 | Q3,Q1,Q3,Q2,Q5 | TO-92_Molded_Narrow | 5 | BC547
6 | D2,D2,D1,D4 | LED-5MM | 4 | LED
7 | C1 | C_Disc_D3_P2.5 | 1 | C_100nF
8 | P1 | Pin_Header_Straight_2x02 | 1 | PWR_JUMPER
9 | U1 | MagneticBuzzer_ProSignal_ABT-410-RC | 1 | BUZZER
10 | XA1,XA2 | Pin_Header_Straight_2x20 | 2 | Conn_Poncho2P_2x_20x2
11 | R10 | Resistor_Horizontal_RM7mm | 1 | 1K

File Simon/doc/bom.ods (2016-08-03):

Source: | /home/mint/googleDrive/estudios/cese/disenoPcb/proyectos/simonShield/simonShield.sch
Date: | jue 07 jul 2016 02:16:50 ART
Tool: | Eeschema 4.0.2-4+6225~38~ubuntu14.04.1-stable
Generator: | /home/mint/googleDrive/estudios/cese/disenoPcb/proyectos/simonShield/tools/bom_csv_grouped_by_value.py
Component Count: | 43
Individual Components:
Item | Qty | Reference(s) | Value | LibPart | Footprint | Datasheet | Descripcion | Digikey#
 |  | C1 | C_100nF | simonLib:C_100nF | footprints:C_Disc_D3_P2.5 |  |  | BC1160TR-ND
 |  | D1 | LED | simonLib:LED_5_MM | footprints:LED-5MM |  |  | 1497-1031-ND
 |  | D2 | LED | simonLib:LED_5_MM | footprints:LED-5MM |  |  | 1497-1031-ND
 |  | D3 | LED | simonLib:LED_5_MM | footprints:LED-5MM |  |  | 1497-1031-ND
 |  | D4 | LED | simonLib:LED_5_MM | footprints:LED-5MM |  |  | 1497-1031-ND
 |  | F1 | FIDUCIAL | ej2cese:FIDUCIAL | footprints:Fiducial_1mm |  | FIDUCIAL
 |  | F2 | FIDUCIAL | ej2cese:FIDUCIAL | footprints:Fiducial_1mm |  | FIDUCIAL
 |  | F3 | FIDUCIAL | ej2cese:FIDUCIAL | footprints:Fiducial_1mm |  | FIDUCIAL
 |  | P1 | PWR_JUMPER | simonLib:PWR_JUMPER | footprints:Pin_Header_Straight_2x02 |  |  | 952-2121-ND
 |  | Q1 | BC547 | simonLib:BC547 | footprints:TO-92_Molded_Narrow |  |  | BC33725TACT-ND
 |  | Q2 | BC547 | simonLib:BC547 | footprints:TO-92_Molded_Narrow |  |  | BC33725TACT-ND
 |  | Q3 | BC547 | simonLib:BC547 | footprints:TO-92_Molded_Narrow |  |  | BC33725TACT-ND
 |  | Q4 | BC547 | simonLib:BC547 | footprints:TO-92_Molded_Narrow |  |  | BC33725TACT-ND
 |  | Q5 | BC547 | simonLib:BC547 | footprints:TO-92_Molded_Narrow |  |  | BC33725TACT-ND
 |  | R1 | 3K3 | simonLib:R | footprints:Resistor_Horizontal_RM7mm |  |  | 680EBK-ND
 |  | R2 | 3K3 | simonLib:R | footprints:Resistor_Horizontal_RM7mm |  |  | 680EBK-ND
 |  | R3 | 3K3 | simonLib:R | footprints:Resistor_Horizontal_RM7mm |  |  | 680EBK-ND
 |  | R4 | 3K3 | simonLib:R | footprints:Resistor_Horizontal_RM7mm |  |  | 680EBK-ND
 |  | R5 | 3K3 | simonLib:R | footprints:Resistor_Horizontal_RM7mm |  |  | 680EBK-ND
 |  | R6 | 3K3 | simonLib:R | footprints:Resistor_Horizontal_RM7mm |  |  | 680EBK-ND
 |  | R7 | 3K3 | simonLib:R | footprints:Resistor_Horizontal_RM7mm |  |  | 680EBK-ND
 |  | R8 | 3K3 | simonLib:R | footprints:Resistor_Horizontal_RM7mm |  |  | 680EBK-ND
 |  | R9 | 3K3 | simonLib:R | footprints:Resistor_Horizontal_RM7mm |  |  | 680EBK-ND
 |  | R10 | 1K | simonLib:R | footprints:Resistor_Horizontal_RM7mm |  |  | 680EBK-ND
 |  | R11 | 10K | simonLib:R | footprints:Resistor_Horizontal_RM7mm |  |  | 680EBK-ND
 |  | R12 | 680 | simonLib:R | footprints:Resistor_Horizontal_RM7mm |  |  | 680EBK-ND
 |  | R13 | 10K | simonLib:R | footprints:Resistor_Horizontal_RM7mm |  |  | 680EBK-ND
 |  | R14 | 680 | simonLib:R | footprints:Resistor_Horizontal_RM7mm |  |  | 680EBK-ND
 |  | R15 | 10K | simonLib:R | footprints:Resistor_Horizontal_RM7mm |  |  | 680EBK-ND
 |  | R16 | 680 | simonLib:R | footprints:Resistor_Horizontal_RM7mm |  |  | 680EBK-ND
 |  | R17 | 10K | simonLib:R | footprints:Resistor_Horizontal_RM7mm |  |  | 680EBK-ND
 |  | R18 | 680 | simonLib:R | footprints:Resistor_Horizontal_RM7mm |  |  | 680EBK-ND
 |  | SW1 | SW_PUSH | simonLib:SW_PUSH | footprints:SW_PUSH_SMALL |  |  | 450-1804-ND
 |  | SW2 | SW_PUSH | simonLib:SW_PUSH | footprints:SW_PUSH_SMALL |  |  | 450-1804-ND
 |  | SW3 | SW_PUSH | simonLib:SW_PUSH | footprints:SW_PUSH_SMALL |  |  | 450-1804-ND
 |  | SW4 | SW_PUSH | simonLib:SW_PUSH | footprints:SW_PUSH_SMALL |  |  | 450-1804-ND
 |  | SW5 | SW_PUSH | simonLib:SW_PUSH | footprints:SW_PUSH_SMALL |  |  | 450-1804-ND
 |  | SW6 | SW_PUSH | simonLib:SW_PUSH | footprints:SW_PUSH_SMALL |  |  | 450-1804-ND
 |  | SW7 | SW_PUSH | simonLib:SW_PUSH | footprints:SW_PUSH_SMALL |  |  | 450-1804-ND
 |  | SW8 | SW_PUSH | simonLib:SW_PUSH | footprints:SW_PUSH_SMALL |  |  | 450-1804-ND
 |  | U1 | BUZZER | simonLib:BUZZER | footprints:MagneticBuzzer_ProSignal_ABT-410-RC |  |  | 445-2525-1-ND
 |  | XA1 | Conn_Poncho2P_2x_20x2 | simonLib:Conn_Poncho2P_2x_20x2 | footprints:Pin_Header_Straight_2x20 |  |  | 952-2121-ND
 |  | XA2 | Conn_Poncho2P_2x_20x2 | simonLib:Conn_Poncho2P_2x_20x2 | footprints:Pin_Header_Straight_2x20 |  |  | 952-2121-ND
Collated Components:
Item | Qty | Reference(s) | Value | LibPart | Footprint | Datasheet | Descripcion | Digikey#
1 | 1 | C1 | C_100nF | simonLib:C_100nF | footprints:C_Disc_D3_P2.5 |  |  | BC1160TR-ND
2 | 4 | D1, D2, D3, D4 | LED | simonLib:LED_5_MM | footprints:LED-5MM |  |  | 1497-1031-ND
3 | 3 | F1, F2, F3 | FIDUCIAL | ej2cese:FIDUCIAL | footprints:Fiducial_1mm |  | FIDUCIAL
4 | 1 | P1 | PWR_JUMPER | simonLib:PWR_JUMPER | footprints:Pin_Header_Straight_2x02 |  |  | 952-2121-ND
5 | 5 | Q1, Q2, Q3, Q4, Q5 | BC547 | simonLib:BC547 | footprints:TO-92_Molded_Narrow |  |  | BC33725TACT-ND
6 | 9 | R1, R2, R3, R4, R5, R6, R7, R8, R9 | 3K3 | simonLib:R | footprints:Resistor_Horizontal_RM7mm |  |  | 680EBK-ND
7 | 1 | R10 | 1K | simonLib:R | footprints:Resistor_Horizontal_RM7mm |  |  | 680EBK-ND
8 | 4 | R11, R13, R15, R17 | 10K | simonLib:R | footprints:Resistor_Horizontal_RM7mm |  |  | 680EBK-ND
9 | 4 | R12, R14, R16, R18 | 680 | simonLib:R | footprints:Resistor_Horizontal_RM7mm |  |  | 680EBK-ND
10 | 8 | SW1, SW2, SW3, SW4, SW5, SW6, SW7, SW8 | SW_PUSH | simonLib:SW_PUSH | footprints:SW_PUSH_SMALL |  |  | 450-1804-ND
11 | 1 | U1 | BUZZER | simonLib:BUZZER | footprints:MagneticBuzzer_ProSignal_ABT-410-RC |  |  | 445-2525-1-ND
12 | 2 | XA1, XA2 | Conn_Poncho2P_2x_20x2 | simonLib:Conn_Poncho2P_2x_20x2 | footprints:Pin_Header_Straight_2x20 |  |  | 952-2121-ND

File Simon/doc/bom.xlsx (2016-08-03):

 |  |  |  |  |  |  | Board Qty: | 100
 |  |  |  |  |  |  | Total Cost: | $0.00 |  |  |  | $0.00 |  |  |  |  |  | $0.00 |  |  |  |  |  | $0.00
 |  |  |  |  |  |  | Unit Cost: | $0.00
Global Part Info |  |  |  |  |  |  |  |  | Digi-Key |  |  |  |  |  | Mouser |  |  |  |  |  | Newark
Refs | Value | Desc | Footprint | Manf | Manf# | Qty | Unit$ | Ext$ | Avail | Purch | Unit$ | Ext$ | Cat# | Doc | Avail | Purch | Unit$ | Ext$ | Cat# | Doc | Avail | Purch | Unit$ | Ext$ | Cat# | Doc
R_THT_SMALL1-R_THT_SMALL17 | R |  | footprints:Resistor_Horizontal_RM7mm |  |  | 0 | $0.00 | $0.00
P1 | PWR_JUMPER |  | footprints:Pin_Header_Straight_2x02 |  |  | 0 | $0.00 | $0.00
C1 | C_100nF |  | footprints:C_Disc_D3_P2.5 |  |  | 0 | $0.00 | $0.00
Q1-Q5 | BC547 |  | footprints:TO-92_Molded_Narrow |  |  | 0 | $0.00 | $0.00
XA1,XA2 | Conn_Poncho2P_2x_20x2 |  | footprints:Pin_Header_Straight_2x20 |  |  | 0 | $0.00 | $0.00
R_THT_SMALL18 | R |  |  |  |  | 0 | $0.00 | $0.00
SW1-SW8 | SW_PUSH |  | footprints:SW_PUSH_SMALL |  |  | 0 | $0.00 | $0.00
U1 | BUZZER |  | footprints:MagneticBuzzer_ProSignal_ABT-410-RC |  |  | 0 | $0.00 | $0.00
D1-D4 | LED_5_MM |  | footprints:LED-5MM |  |  | 0 | $0.00 | $0.00
 |  |  |  |  |  |  |  |  |  | 0 | 0 | 0 |  |  |  | 0 | 0 | 0 |  |  |  | 0 | 0 | 0
 |  |  |  |  |  |  |  |  |  | 0 | 0 | 0 |  |  |  | 0 | 0 | 0 |  |  |  | 0 | 0 | 0
 |  |  |  |  |  |  |  |  |  | 0 | 0 | 0 |  |  |  | 0 | 0 | 0 |  |  |  | 0 | 0 | 0
 |  |  |  |  |  |  |  |  |  | 0 | 0 | 0 |  |  |  | 0 | 0 | 0 |  |  |  | 0 | 0 | 0
 |  |  |  |  |  |  |  |  |  | 0 | 0 | 0 |  |  |  | 0 | 0 | 0 |  |  |  | 0 | 0 | 0
 |  |  |  |  |  |  |  |  |  | 0 | 0 | 0 |  |  |  | 0 | 0 | 0 |  |  |  | 0 | 0 | 0
 |  |  |  |  |  |  |  |  |  | 0 | 0 | 0 |  |  |  | 0 | 0 | 0 |  |  |  | 0 | 0 | 0
 |  |  |  |  |  |  |  |  |  | 0 | 0 | 0 |  |  |  | 0 | 0 | 0 |  |  |  | 0 | 0 | 0
 |  |  |  |  |  |  |  |  |  | 0 | 0 | 0 |  |  |  | 0 | 0 | 0 |  |  |  | 0 | 0 | 0

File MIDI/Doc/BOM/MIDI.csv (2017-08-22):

Source: | MIDI.sch
Date: | lun 17 jul 2017 17:52:08 ART
Tool: | Eeschema 4.0.6-e0-6349~53~ubuntu16.04.1
Generator: | /home/cmancon/CESE/DCI/Ejercicio_2/ej2tools/bom_csv_grouped_by_value.py
Component Count: | 134
Individual Components:
Item | Qty | Reference(s) | Value | LibPart | Footprint | Datasheet | Desc | Description | Digikey# | Manf | Manf# | Mouser# | kicost.v1:Manf#
 |  | C1 | 100nF | MIDI:C | MIDI:C_0805_HandSoldering | http://www.yageo.com/documents/recent/UPY-GPHC_X7R_6.3V-to-50V_18.pdf | CAP CER 0.1UF 50V X7R 0805 | CAP CER 0.1UF 50V X7R 0805 | 311-1140-1-ND | Yageo | CC0805KRX7R9BB104 | 603-CC805KRX7R9BB104
 |  | C2 | 100nF | MIDI:C | MIDI:C_0805_HandSoldering | http://www.yageo.com/documents/recent/UPY-GPHC_X7R_6.3V-to-50V_18.pdf | CAP CER 0.1UF 50V X7R 0805 | CAP CER 0.1UF 50V X7R 0805 | 311-1140-1-ND | Yageo | CC0805KRX7R9BB104 | 603-CC805KRX7R9BB104
 |  | C3 | 100nF | MIDI:C | MIDI:C_0805_HandSoldering | http://www.yageo.com/documents/recent/UPY-GPHC_X7R_6.3V-to-50V_18.pdf | CAP CER 0.1UF 50V X7R 0805 | CAP CER 0.1UF 50V X7R 0805 | 311-1140-1-ND | Yageo | CC0805KRX7R9BB104 | 603-CC805KRX7R9BB104
 |  | C4 | 100nF | MIDI:C | MIDI:C_0805_HandSoldering | http://www.yageo.com/documents/recent/UPY-GPHC_X7R_6.3V-to-50V_18.pdf | CAP CER 0.1UF 50V X7R 0805 | CAP CER 0.1UF 50V X7R 0805 | 311-1140-1-ND | Yageo | CC0805KRX7R9BB104 | 603-CC805KRX7R9BB104
 |  | C5 | 10nF | MIDI:C | MIDI:C_0805_HandSoldering | http://www.yageo.com/documents/recent/UPY-GPHC_X7R_6.3V-to-50V_18.pdf | CAP CER 10000PF 50V X7R 0805 | CAP CER 10000PF 50V X7R 0805 | 311-1136-1-ND | Yageo | CC0805KRX7R9BB103 | 603-CC805KRX7R9BB103
 |  | C6 | 10nF | MIDI:C | MIDI:C_0805_HandSoldering | http://www.yageo.com/documents/recent/UPY-GPHC_X7R_6.3V-to-50V_18.pdf | CAP CER 10000PF 50V X7R 0805 | CAP CER 10000PF 50V X7R 0805 | 311-1136-1-ND | Yageo | CC0805KRX7R9BB103 | 603-CC805KRX7R9BB103
 |  | C7 | 100nF | MIDI:C | MIDI:C_0805_HandSoldering | http://www.yageo.com/documents/recent/UPY-GPHC_X7R_6.3V-to-50V_18.pdf | CAP CER 0.1UF 50V X7R 0805 | CAP CER 0.1UF 50V X7R 0805 | 311-1140-1-ND | Yageo | CC0805KRX7R9BB104 | 603-CC805KRX7R9BB104
 |  | C8 | 100nF | MIDI:C | MIDI:C_0805_HandSoldering | http://www.yageo.com/documents/recent/UPY-GPHC_X7R_6.3V-to-50V_18.pdf | CAP CER 0.1UF 50V X7R 0805 | CAP CER 0.1UF 50V X7R 0805 | 311-1140-1-ND | Yageo | CC0805KRX7R9BB104 | 603-CC805KRX7R9BB104
 |  | C9 | 10nF | MIDI:C | MIDI:C_0805_HandSoldering | http://www.yageo.com/documents/recent/UPY-GPHC_X7R_6.3V-to-50V_18.pdf | CAP CER 10000PF 50V X7R 0805 | CAP CER 10000PF 50V X7R 0805 | 311-1136-1-ND | Yageo | CC0805KRX7R9BB103 | 603-CC805KRX7R9BB103
 |  | C10 | 10nF | MIDI:C | MIDI:C_0805_HandSoldering | http://www.yageo.com/documents/recent/UPY-GPHC_X7R_6.3V-to-50V_18.pdf | CAP CER 10000PF 50V X7R 0805 | CAP CER 10000PF 50V X7R 0805 | 311-1136-1-ND | Yageo | CC0805KRX7R9BB103 | 603-CC805KRX7R9BB103
 |  | C11 | 100nF | MIDI:C | MIDI:C_0805_HandSoldering | http://www.yageo.com/documents/recent/UPY-GPHC_X7R_6.3V-to-50V_18.pdf | CAP CER 0.1UF 50V X7R 0805 | CAP CER 0.1UF 50V X7R 0805 | 311-1140-1-ND | Yageo | CC0805KRX7R9BB104 | 603-CC805KRX7R9BB104
 |  | C12 | 100nF | MIDI:C | MIDI:C_0805_HandSoldering | http://www.yageo.com/documents/recent/UPY-GPHC_X7R_6.3V-to-50V_18.pdf | CAP CER 0.1UF 50V X7R 0805 | CAP CER 0.1UF 50V X7R 0805 | 311-1140-1-ND | Yageo | CC0805KRX7R9BB104 | 603-CC805KRX7R9BB104
 |  | C13 | 10nF | MIDI:C | MIDI:C_0805_HandSoldering | http://www.yageo.com/documents/recent/UPY-GPHC_X7R_6.3V-to-50V_18.pdf | CAP CER 10000PF 50V X7R 0805 | CAP CER 10000PF 50V X7R 0805 | 311-1136-1-ND | Yageo | CC0805KRX7R9BB103 | 603-CC805KRX7R9BB103
 |  | C14 | 10nF | MIDI:C | MIDI:C_0805_HandSoldering | http://www.yageo.com/documents/recent/UPY-GPHC_X7R_6.3V-to-50V_18.pdf | CAP CER 10000PF 50V X7R 0805 | CAP CER 10000PF 50V X7R 0805 | 311-1136-1-ND | Yageo | CC0805KRX7R9BB103 | 603-CC805KRX7R9BB103
 |  | C15 | 100nF | MIDI:C | MIDI:C_0805_HandSoldering | http://www.yageo.com/documents/recent/UPY-GPHC_X7R_6.3V-to-50V_18.pdf | CAP CER 0.1UF 50V X7R 0805 | CAP CER 0.1UF 50V X7R 0805 | 311-1140-1-ND | Yageo | CC0805KRX7R9BB104 | 603-CC805KRX7R9BB104
 |  | C16 | 100nF | MIDI:C | MIDI:C_0805_HandSoldering | http://www.yageo.com/documents/recent/UPY-GPHC_X7R_6.3V-to-50V_18.pdf | CAP CER 0.1UF 50V X7R 0805 | CAP CER 0.1UF 50V X7R 0805 | 311-1140-1-ND | Yageo | CC0805KRX7R9BB104 | 603-CC805KRX7R9BB104
 |  | C17 | 100nF | MIDI:C | MIDI:C_0805_HandSoldering | http://www.yageo.com/documents/recent/UPY-GPHC_X7R_6.3V-to-50V_18.pdf | CAP CER 0.1UF 50V X7R 0805 | CAP CER 0.1UF 50V X7R 0805 | 311-1140-1-ND | Yageo | CC0805KRX7R9BB104 | 603-CC805KRX7R9BB104
 |  | C18 | 100nF | MIDI:C | MIDI:C_0805_HandSoldering | http://www.yageo.com/documents/recent/UPY-GPHC_X7R_6.3V-to-50V_18.pdf | CAP CER 0.1UF 50V X7R 0805 | CAP CER 0.1UF 50V X7R 0805 | 311-1140-1-ND | Yageo | CC0805KRX7R9BB104 | 603-CC805KRX7R9BB104
 |  | C19 | 100nF | MIDI:C | MIDI:C_0805_HandSoldering | http://www.yageo.com/documents/recent/UPY-GPHC_X7R_6.3V-to-50V_18.pdf | CAP CER 0.1UF 50V X7R 0805 | CAP CER 0.1UF 50V X7R 0805 | 311-1140-1-ND | Yageo | CC0805KRX7R9BB104 | 603-CC805KRX7R9BB104
 |  | C20 | 100nF | MIDI:C | MIDI:C_0805_HandSoldering | http://www.yageo.com/documents/recent/UPY-GPHC_X7R_6.3V-to-50V_18.pdf | CAP CER 0.1UF 50V X7R 0805 | CAP CER 0.1UF 50V X7R 0805 | 311-1140-1-ND | Yageo | CC0805KRX7R9BB104 | 603-CC805KRX7R9BB104
 |  | C21 | 100nF | MIDI:C | MIDI:C_0805_HandSoldering | http://www.yageo.com/documents/recent/UPY-GPHC_X7R_6.3V-to-50V_18.pdf | CAP CER 0.1UF 50V X7R 0805 | CAP CER 0.1UF 50V X7R 0805 | 311-1140-1-ND | Yageo | CC0805KRX7R9BB104 | 603-CC805KRX7R9BB104
 |  | C22 | 100nF | MIDI:C | MIDI:C_0805_HandSoldering | http://www.yageo.com/documents/recent/UPY-GPHC_X7R_6.3V-to-50V_18.pdf | CAP CER 0.1UF 50V X7R 0805 | CAP CER 0.1UF 50V X7R 0805 | 311-1140-1-ND | Yageo | CC0805KRX7R9BB104 | 603-CC805KRX7R9BB104
 |  | C23 | 100nF | MIDI:C | MIDI:C_0805_HandSoldering | http://www.yageo.com/documents/recent/UPY-GPHC_X7R_6.3V-to-50V_18.pdf | CAP CER 0.1UF 50V X7R 0805 | CAP CER 0.1UF 50V X7R 0805 | 311-1140-1-ND | Yageo | CC0805KRX7R9BB104 | 603-CC805KRX7R9BB104
 |  | C24 | 100nF | MIDI:C | MIDI:C_0805_HandSoldering | http://www.yageo.com/documents/recent/UPY-GPHC_X7R_6.3V-to-50V_18.pdf | CAP CER 0.1UF 50V X7R 0805 | CAP CER 0.1UF 50V X7R 0805 | 311-1140-1-ND | Yageo | CC0805KRX7R9BB104 | 603-CC805KRX7R9BB104
 |  | C25 | 100nF | MIDI:C | MIDI:C_0805_HandSoldering | http://www.yageo.com/documents/recent/UPY-GPHC_X7R_6.3V-to-50V_18.pdf | CAP CER 0.1UF 50V X7R 0805 | CAP CER 0.1UF 50V X7R 0805 | 311-1140-1-ND | Yageo | CC0805KRX7R9BB104 | 603-CC805KRX7R9BB104
 |  | C26 | 100nF | MIDI:C | MIDI:C_0805_HandSoldering | http://www.yageo.com/documents/recent/UPY-GPHC_X7R_6.3V-to-50V_18.pdf | CAP CER 0.1UF 50V X7R 0805 | CAP CER 0.1UF 50V X7R 0805 | 311-1140-1-ND | Yageo | CC0805KRX7R9BB104 | 603-CC805KRX7R9BB104
 |  | C27 | 100nF | MIDI:C | MIDI:C_0805_HandSoldering | http://www.yageo.com/documents/recent/UPY-GPHC_X7R_6.3V-to-50V_18.pdf | CAP CER 0.1UF 50V X7R 0805 | CAP CER 0.1UF 50V X7R 0805 | 311-1140-1-ND | Yageo | CC0805KRX7R9BB104 | 603-CC805KRX7R9BB104
 |  | C28 | 100nF | MIDI:C | MIDI:C_0805_HandSoldering | http://www.yageo.com/documents/recent/UPY-GPHC_X7R_6.3V-to-50V_18.pdf | CAP CER 0.1UF 50V X7R 0805 | CAP CER 0.1UF 50V X7R 0805 | 311-1140-1-ND | Yageo | CC0805KRX7R9BB104 | 603-CC805KRX7R9BB104
 |  | D1 | 1N4148 | MIDI:DIODE | MIDI:D_DO-35_SOD27_P7.62mm_Horizontal | https://www.fairchildsemi.com/datasheets/1N/1N914.pdf | DIODE GEN PURP 100V 200MA DO35 | DIODE GEN PURP 100V 200MA DO35 | 1N4148FS-ND | Fairchild/ON Semiconductor | 1N4148 | 512-1N4148
 |  | F1 | CONN_1 | MIDI:CONN_1 | MIDI:Fiducial_1mm_BOT |  |  |  |  |  |  |  | 1000
 |  | F2 | CONN_1 | MIDI:CONN_1 | MIDI:Fiducial_1mm_BOT |  |  |  |  |  |  |  | 1000
 |  | F3 | CONN_1 | MIDI:CONN_1 | MIDI:Fiducial_1mm_BOT |  |  |  |  |  |  |  | 1000
 |  | F4 | CONN_1 | MIDI:CONN_1 | MIDI:Fiducial_1mm_TOP |  |  |  |  |  |  |  | 1000
 |  | F5 | CONN_1 | MIDI:CONN_1 | MIDI:Fiducial_1mm_TOP |  |  |  |  |  |  |  | 1000
 |  | F6 | CONN_1 | MIDI:CONN_1 | MIDI:Fiducial_1mm_TOP |  |  |  |  |  |  |  | 1000
 |  | FB1 | 1k @100MHz | MIDI:FILTER | MIDI:FB_0805_HandSoldering | http://ds.yuden.co.jp/TYCOMPAS/ut/detail.do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 | FERRITE BEAD 1 KOHM 0805 1LN | FERRITE BEAD 1 KOHM 0805 1LN | 587-1904-1-ND | Taiyo Yuden | BK2125HS102-T | 963-BK2125HS102-T
 |  | FB2 | 1k @100MHz | MIDI:FILTER | MIDI:FB_0805_HandSoldering | http://ds.yuden.co.jp/TYCOMPAS/ut/detail.do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 | FERRITE BEAD 1 KOHM 0805 1LN | FERRITE BEAD 1 KOHM 0805 1LN | 587-1904-1-ND | Taiyo Yuden | BK2125HS102-T | 963-BK2125HS102-T
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

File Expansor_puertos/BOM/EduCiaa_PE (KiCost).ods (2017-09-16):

 |  |  |  |  |  |  | Board Qty: | 100
 |  |  |  |  |  |  | Total Cost: | $1,074.34 |  |  |  | $1,322.91 |  |  |  |  |  | $1,486.37 |  |  |  |  |  | $818.10 |  |  |  |  |  | $2,028.10 |  |  |  |  |  | $33,531.06
 |  |  |  |  |  |  | Unit Cost: | $10.74
Global Part Info |  |  |  |  |  |  |  |  | Digi-Key |  |  |  |  |  | Farnell |  |  |  |  |  | Mouser |  |  |  |  |  | Newark |  |  |  |  |  | Rs Components
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

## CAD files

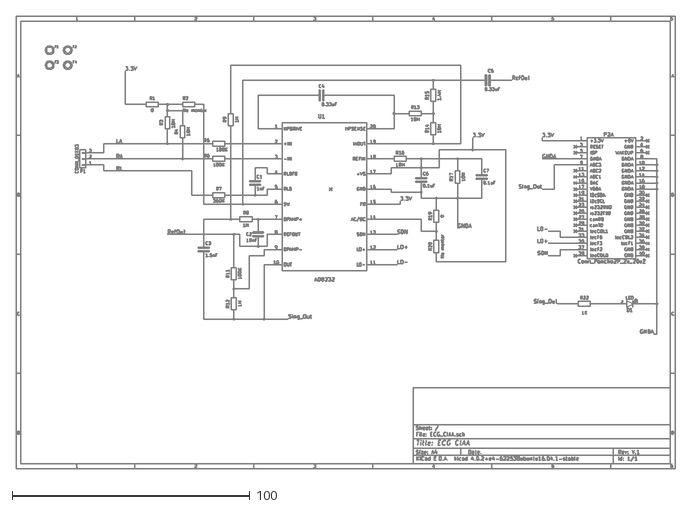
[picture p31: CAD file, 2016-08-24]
ECG/ECG_CIAA.dxf
277.0 x 190.0

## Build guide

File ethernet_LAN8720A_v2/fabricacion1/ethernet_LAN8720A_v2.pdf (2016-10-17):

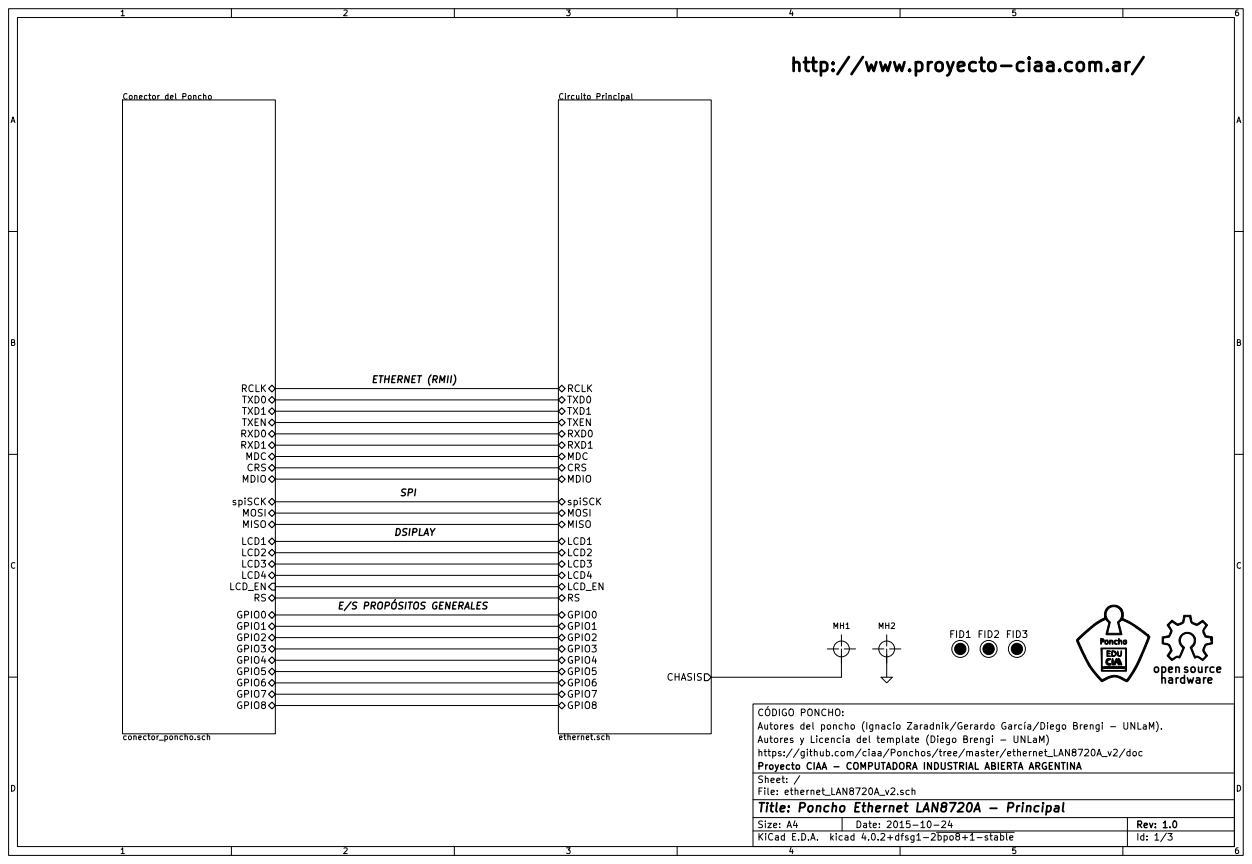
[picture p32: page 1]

http://www.proyecto-ciaa.com.ar/

CÓDIGO PONCHO:
Autores del poncho (Ignacio Zaradnik/Gerardo García/Diego Brengi - UNLaM).
Autores y Licencia del template (Diego Brengi - UNLaM)
https://github.com/ciaa/Ponchos/tree/master/ethernet_LAN8720A_v2/doc
File: ethernet_LAN8720A_v2.sch Sheet: / Proyecto CIAA - COMPUTADORA INDUSTRIAL ABIERTA ARGENTINA

Id: 1/3 Title: Poncho Ethernet LAN8720A - Principal

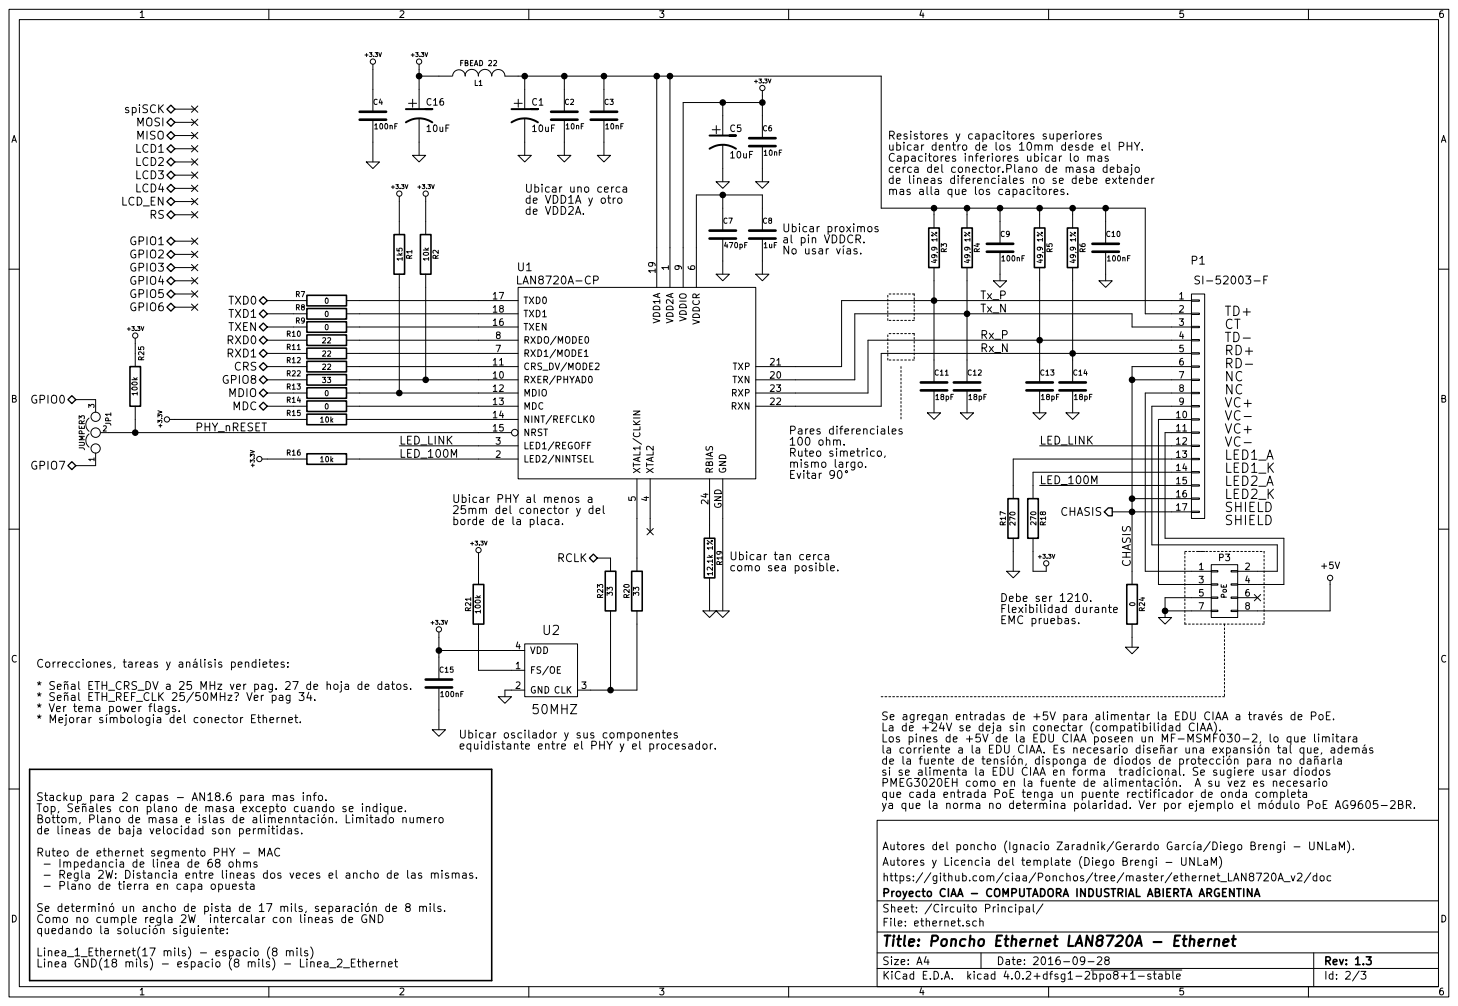
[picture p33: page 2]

Resistores y capacitores superiores ubicar dentro de los 10mm desde el PHY. Capacitores inferiores ubicar lo mas

cerca del conector.Plano de masa debajo de lineas diferenciales no se debe extender mas alla que los capacitores. Pares diferenciales 100 ohm. Ruteo simetrico,

No usar vías. Ubicar uno cerca de VDD1A y otro

9 RXER/PHYAD0 10 TXN 20 CRS_DV/MODE2 11 TXP 21 MDIO 12 RXN 22 MDC 13 RXP 23 NINT/REFCLK0 14 RBIAS 24 NRST 15 TXEN 16 TXD0 17 TXD1 18 VDD1A 19 GND GND U1
LAN8720A-CP

5 VDDCR
Autores del poncho (Ignacio Zaradnik/Gerardo García/Diego Brengi - UNLaM). VDD2A

10

mismo largo. Evitar 90° Ubicar tan cerca como sea posible.

14
15
16

equidistante entre el PHY y el procesador. Ubicar PHY al menos a
25mm del conector y del
borde de la placa.

Correcciones, tareas y análisis pendietes:
* Señal ETH_CRS_DV a 25 MHz ver pag. 27 de hoja de datos.
* Señal ETH_REF_CLK 25/50MHz? Ver pag 34.
* Ver tema power flags.
* Mejorar símbologia del conector Ethernet.

Se agregan entradas de +5V para alimentar la EDU CIAA a través de PoE.
La de +24V se deja sin conectar (compatibilidad CIAA).
Los pines de +5V de la EDU CIAA poseen un MF-MSMF030-2, lo que limitara
la corriente a la EDU CIAA. Es necesario diseñar una expansión tal que, además
de la fuente de tensión, disponga de diodos de protección para no dañarla
si se alimenta la EDU CIAA en forma tradicional. Se sugiere usar diodos
PMEG3020EH como en la fuente de alimentación. A su vez es necesario
que cada entrada PoE tenga un puente rectificador de onda completa
ya que la norma no determina polaridad. Ver por ejemplo el módulo PoE AG9605-2BR.

Ubicar oscilador y sus componentes

Stackup para 2 capas - AN18.6 para mas info.
Top, Señales con plano de masa excepto cuando se indique.
Bottom, Plano de masa e islas de alimenntación. Limitado numero
de lineas de baja velocidad son permitidas.
Ruteo de ethernet segmento PHY - MAC
- Impedancia de linea de 68 ohms
- Regla 2W: Distancia entre lineas dos veces el ancho de las mismas.
- Plano de tierra en capa opuesta
Se determinó un ancho de pista de 17 mils, separación de 8 mils.
Como no cumple regla 2W intercalar con lineas de GND
quedando la solución siguiente:
Linea_1_Ethernet(17 mils) - espacio (8 mils)
Linea GND(18 mils) - espacio (8 mils) - Linea_2_Ethernet

Autores y Licencia del template (Diego Brengi - UNLaM)
https://github.com/ciaa/Ponchos/tree/master/ethernet_LAN8720A_v2/doc
Proyecto CIAA - COMPUTADORA INDUSTRIAL ABIERTA ARGENTINA
Id: 2/3 Title: Poncho Ethernet LAN8720A - Ethernet File: ethernet.sch Sheet: /Circuito Principal/

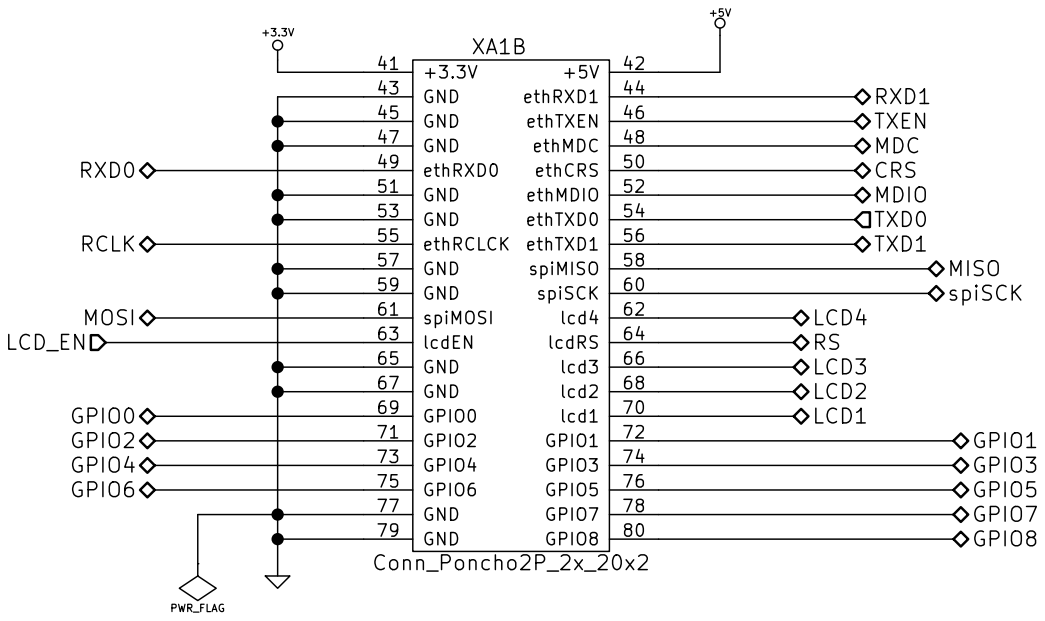
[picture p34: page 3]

CÓDIGO PONCHO:
Autores del poncho (Ignacio Zaradnik/Gerardo García/Diego Brengi - UNLaM).
Autores y Licencia del template (Diego Brengi - UNLaM)
https://github.com/ciaa/Ponchos/tree/master/ethernet_LAN8720A_v2/doc
File: conector_poncho.sch Sheet: /Conector del Poncho/ Proyecto CIAA - COMPUTADORA INDUSTRIAL ABIERTA ARGENTINA

Id: 3/3 Title: Poncho Ethernet LAN8720A - Conector

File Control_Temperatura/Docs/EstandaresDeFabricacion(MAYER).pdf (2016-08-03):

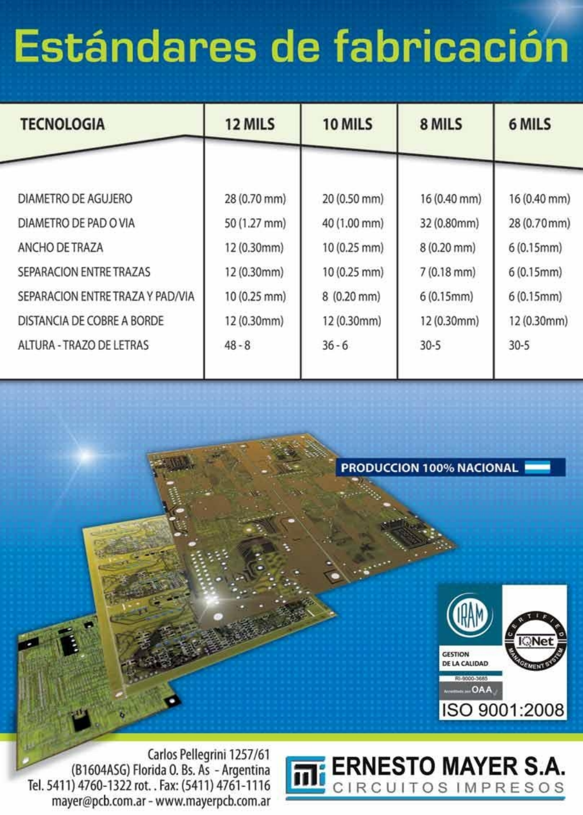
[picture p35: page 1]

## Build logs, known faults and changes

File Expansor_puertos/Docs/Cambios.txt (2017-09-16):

Historial de cambios realizados 
================================

* Fecha: 2017
* Autores: 	Ing. Mariano D. Orlante
* Descripción:	Este desarrollo se basó en el modelo de Poncho Grande realizado por el Ing. Diego Brengi
		Modelo Poncho Grande: https://github.com/ciaa/Ponchos/tree/master/modelos/Poncho_Grande
				
* Archivos: 
* Descripción: Se parte de los Modelos de Ponchos en: 
               http://www.proyecto-ciaa.com.ar/devwiki/doku.php?id=desarrollo:edu-ciaa:ponchos_modelos
               <<Colocar aquí información de cambios importantes y de gran volumen, releases, contribuciones
                de terceros, etc.>>

Ver información de los commits del repositorio git.

---------------------------------------------------------------------------------------------------
08-Ago-2017
SHA-1: 

- Se agrego la leyenda INDUSTRIA ARGENTINA en la capa bottom del PCB.
- Se ampliaron las areas de cobre por fuera del borde de la placa.
- Se agregaron labels extra para identificar las entradas y salidas, en las borneras.
- Se agrego el SCH de la Edu-Ciaa.
- Se generaron los archivos Gerber y Drill.
- Se modifico el documento de la revisión, el documento Cambios.txt y los screenshots del 3D.

---------------------------------------------------------------------------------------------------
19-Jul-2017
SHA-1: 21387561a7919b0a8a0218290007c628d3cb2c5c

* Se agregaron tiras de pines 2x20 en el  3D

---------------------------------------------------------------------------------------------------
16-Jul-2017
SHA-1: 96dd4623101b3fe907c58b85563d95b4820c1138

* Se agregaron las modificaciones sugeridas por el revisor FS.
- Se agregaron los cambios al PCB.
- Se actualizaron las vistas 3D.
- Se editó el pin 41 del componente Conector Poncho 2x20 "B" para hacerlo pasivo, 
  y poder conectarlo al pin 1 del Conector Poncho 2x20 "A".
 
---------------------------------------------------------------------------------------------------
16-Jul-2017
SHA-1: 4efcea761ab8f3286aabc14b7368e312296624ad

* Corrección de algunos detalles en la serigrafía del PCB.

---------------------------------------------------------------------------------------------------
16-Jul-2017
SHA-1: f4fe8b605ebd18cb9efb0dd490330ee07a5fdb92

* Agregado de modelos 3D (WRL) para C_0805 y R_0805.wrl

---------------------------------------------------------------------------------------------------
16-Jul-2017
SHA-1: b23e758dbb6d84c18799be8ee09fecc9bdfe5dd6

* Ruteo del PCB y agregado de descripcion de Stack-Up
- Se agrego la BOM.
- Cálculo de costos (KiCost)
- Screenshots en el directorio /Docs/Vistas 3D
- Agregado del directorio /Tools con scripts de python

---------------------------------------------------------------------------------------------------
08-Jul-2017
SHA-1: 3dae5c36f44a8bc24a52a2b5fd61f28af5cb1b56

* Se ejecutaron las correcciones sugeridas por DB el 30/06/2017

A saber:

-Se agrego el archivo hoja de proyecto en /Docs
-Se subió el archivo Revisiones(DB).odt
-Se eliminaron algunas labels locales innecesarias en los SCH.
-Se hizo el rotulo del PCB
-Se agrego un fiducial

---------------------------------------------------------------------------------------------------
24-Jun-2017
SHA-1: ce613c2a5ccbc5bfb7bb9324057b7c8801915a18

*Se agregaron los cambios sugeridos por el revisor.
Se agrego la carpeta Docs/Notas de Ingenieria con especificaciones y calculos del producto.
Se modificaron los codigos de componentes de las borneras elegidas, y se cambio la 
hoja de datos de las mismas.

---------------------------------------------------------------------------------------------------
22-Jun-2017
SHA-1: 308b83a19beeef5c71114ee984eb991c37cfbf27

* Se agregaron comentarios en los esquemáticos.
Se incorporaron todos los componentes en una libreria local.
Se agregaron Hojas de datos.
Se agregaron modelos 3D en la carpeta correspondiente.
Se genero una unica carpeta de footprints, con los footprints utilizados.
Se Modificaron los rótulos.

---------------------------------------------------------------------------------------------------
20-Jun-2017
SHA-1: 422bf3128a2cde2afb6f08b3197039d48ab62f8e

* Avances en SCH.
Presentacion de componentes en el PCB.

---------------------------------------------------------------------------------------------------
15-May-17
SHA-1: 61ef3d864cb83fa8dcbcf777c2946660038d120d

* 1er Commit del Proyecto EduCiaa PE

---------------------------------------------------------------------------------------------------

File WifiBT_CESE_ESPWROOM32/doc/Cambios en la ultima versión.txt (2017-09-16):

Se cambia el código de los leds, sus footprints y los leds para que sean compatibles con la variante recomendada.
Se actualiza el listado de componentes y la planilla del kicost.
Se agrega una zona de exclusión bajo el integrado wifi, solo arriba porque abajo se necesita conectar el negativo en el centro del integrado.
Se achica el borde de la placa para que el poncho sea más chico y se aprovechan mejor los espacio según lo sugerido. 
Se agrega zona de cobre en la capa inferior con gnd.
Se recorta la zona de cobre para que no pase bajo la antena.
Se agrega "Industria Argentina" en la capa inferior.
Se mejoró el posicionamiento y el ruteo aunque quedaron mejoras pendientes.
Se achicó el borde del PCB para aprovechar mejor el espacio.
Se exportaron nuevos archivos gerber.
Se actualiza el presupuesto con kicost. (Bajó el precio!)

Se agrega tutorial básico sobre el uso del Freerouting en la carpeta doc.

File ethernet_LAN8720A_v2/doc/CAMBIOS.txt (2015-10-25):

Cambios realizados al Poncho Ethernet
=====================================

* Fecha: 9/9/2015
* Autores: Diego Brengi.
* Archivos: Se toma como base la hoja Ethernet del esquemático de la CIAA-NXP.
* Descripción: Inicialización del repositorio GIT.Se realizan ajustes según versión de Kicad, se crea la estructura de directorios en el git y se sube.

* Fecha: 24/10/2015
* Autores: Ignacio Zaradnik.
* Archivos: Se toman los generados por el Template Poncho Grande, Chico y los previemanete trabajados
* Descripción: Se genera un nuevo proyecto tomando como base el template del poncho grande para esquematico, se agrega esquemático de Ethernet.
Se agregan notas de diseño, se cambian valores de capacitores y se agregan algunas resistencias.
Se cambia pcb generado por template Poncho grande por el del template poncho chico.

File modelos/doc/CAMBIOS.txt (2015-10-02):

Cambios realizados a los Modelos y Templates de Ponchos 
=======================================================

* Fecha: 29/9/2015
* Autores: Diego Brengi.
* Archivos: Se arranca el modelo desde cero.
* Descripción: El objetivo es un conjunto de ponchos,  muy básicos
               para que se pueda tomar después como base para otros ponchos.
               Se publica el poncho "grande" que posee una superficie igual a la EDU-CIAA,
               utiliza los cuatro agujeros de sujeción y utiliza ambos conectores de expansión.

* Fecha: 1/10/15
* Autores: Diego Brengi
* Archivos: Subdirectorio kicad y modelos.
* Descripción: Se reorganizan los directorios y los nombres de archivos para seguir las
               recomendaciones de bibliotecas para Kicad. 
               Se termina casi el 90% del Poncho Grande, una placa con área de prototipado,
               solo como ejemplo.
               Al momento hay dos tipos de simbología para el conector, una base footprint para
               una placa grande y una plantilla para poder ver fácilmente la relación con la
               placa EDU-CIAA. La plantilla está verificada con ambas EDU-CIA (NXP y FSL).

* Fecha: 2/10/15
* Autores Diego Brengi
* Descripción: Se sube un modelo llamado  Poncho Chico que utiliza ambos conectores de la EDU-CIAA
               pero no los agujeros de sujeción. También utiliza en el esquemático una simbología
               multiparte organizada por funciones.
               Se agrega además a los diseños de Poncho Grande y Poncho Chico la información para
               convertirlos en templates de Kicad, que permite utilizarlos de base y copiarlos fácilmente
               para otros proyectos.
               Se hace una reorganización general y se emprolijan varios detalles. 
* Archivos alcanzados: 
kicad/libModelos:
Misc_Poncho_Grande.lib
kicad/libPonchos:
Poncho_Esqueleto.lib
kicad/Poncho_Esqueleto.pretty:
Conn_Poncho_Chico.kicad_mod     Conn_Poncho_Izquierdo.kicad_mod  Plantilla_EDU-CIAA.kicad_mod
Conn_Poncho_Completo.kicad_mod  Conn_Poncho_Mediano.kicad_mod    
Conn_Poncho_Derecha.kicad_mod   Conn_Poncho_SinBorde.kicad_mod   Logo_Poncho.kicad_mod
modelos/Poncho_Chico:
conector_poncho.sch  meta                    Poncho_Chico.kicad_pcb  Poncho_Chico.pro  principal.sch
fp-lib-table         Poncho_Chico-cache.lib  Poncho_Chico.net        Poncho_Chico.sch
modelos/Poncho_Chico/meta:
icon.png  info.html  ponchoB.png  ponchoF.png
modelos/poncho_grande:
conector_poncho.bak  fp-lib-table  poncho_grande.bak        poncho_grande.kicad_pcb      poncho_grande.net  poncho_grande.sch  principal.sch
conector_poncho.sch  meta          poncho_grande-cache.lib  poncho_grande.kicad_pcb-bak  poncho_grande.pro  principal.bak
modelos/poncho_grande/meta:
icon.png  info.html  poncho_grande.png
modelos/Poncho_Chico:
conector_poncho.sch  meta                    Poncho_Chico.kicad_pcb  Poncho_Chico.pro  principal.sch
fp-lib-table         Poncho_Chico-cache.lib  Poncho_Chico.net        Poncho_Chico.sch
modelos/Poncho_Chico/meta:
icon.png  info.html  ponchoB.png  ponchoF.png
modelos/poncho_grande:
fp-lib-table  poncho_grande.bak    poncho_grande.kicad_pcb      poncho_grande.net  poncho_grande.sch  principal.sch
conector_poncho.sch  meta          poncho_grande-cache.lib  poncho_grande.kicad_pcb-bak  poncho_grande.pro  principal.bak
modelos/poncho_grande/meta:
icon.png  info.html  poncho_grande.png

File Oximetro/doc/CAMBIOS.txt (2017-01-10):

Historial de cambios realizados 
================================
                
 Para ver historial de cambios, revisar historial de commits de repositorio del poncho.
 Enlace: https://github.com/Fermeira/Oximetro_CESE.git

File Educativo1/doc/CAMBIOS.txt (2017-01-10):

Historial de cambios realizados 
================================
                
 Para ver historial de cambios, revisar historial de commits de repositorio del poncho.
 Enlace: https://github.com/guille411/EduPoncho

commit a6f8c1ef5a7ec2dc87f64ed69c8b34fa2c5f817f
Author: Guillermo <guille411@hotmail.com>
Date:   Mon Dec 19 21:42:47 2016 -0300

    Correcion de pistas a octoacopladores, rutas de modelos 3d, id encoder y otras correcciones menores

commit e9c2931b6838ecae41d5e5c9e6e473b8981600d3
Author: Guillermo <guille411@hotmail.com>
Date:   Tue Dec 13 22:48:40 2016 -0300

    Se corrigieron las cotas

commit 96ca4efdd7176d3772dcbab32ee2c389a8ec9e66
Author: Guillermo <guille411@hotmail.com>
Date:   Sun Dec 11 23:27:06 2016 -0300

    Reubicacion de optoacopladores, cambio de footoprins de resistencias a 0805,

commit 19a3beac1dab0ee2de5eb201ca972c01c21069f8
Author: Guillermo <guille411@hotmail.com>
Date:   Sat Dec 3 14:04:16 2016 -0300

    Se agregaron cotas, fiducidales y escrituras en cobre. Tambien se corrigiero

commit 30044835d0920b023496e882037701eafb6c62b2
Author: Guillermo <guille411@hotmail.com>
Date:   Fri Dec 2 15:52:42 2016 -0300

    Se termino de rutear la placa y se acomodaron ref de los componentes, se agr

commit b9a112bde8bfceb60255edcefa7bb1e38385f757
Author: Guillermo <guille411@hotmail.com>
Date:   Mon Nov 28 16:41:02 2016 -0300

    Se definió contorno de la placa y se ubicaron los componentes. También se ru
:...skipping...
commit 96ca4efdd7176d3772dcbab32ee2c389a8ec9e66
Author: Guillermo <guille411@hotmail.com>
Date:   Sun Dec 11 23:27:06 2016 -0300

    Reubicacion de optoacopladores, cambio de footoprins de resistencias a 0805, correcion general.Falta arreglar archivos vista 3d y completar 

commit 19a3beac1dab0ee2de5eb201ca972c01c21069f8
Author: Guillermo <guille411@hotmail.com>
Date:   Sat Dec 3 14:04:16 2016 -0300

    Se agregaron cotas, fiducidales y escrituras en cobre. Tambien se corrigieron algunos errores.

commit 30044835d0920b023496e882037701eafb6c62b2
Author: Guillermo <guille411@hotmail.com>
Date:   Fri Dec 2 15:52:42 2016 -0300

    Se termino de rutear la placa y se acomodaron ref de los componentes, se agrego nombres y fiduciales

commit b9a112bde8bfceb60255edcefa7bb1e38385f757
Author: Guillermo <guille411@hotmail.com>
Date:   Mon Nov 28 16:41:02 2016 -0300

    Se definió contorno de la placa y se ubicaron los componentes. También se ruteo la placa completa, falta revisión

commit cd3c6acffddb2071ce49db4d4d2df4f6ad6eb4e6
Author: Guillermo <guille411@hotmail.com>
Date:   Thu Nov 24 23:11:46 2016 -0300

    Se agruparon componentes por bloques funcionales. Falta definir contorno de la placa y posicion final de los bloques.

commit d8dab5fd6cc56c8a1e74660f5d9c8dac7a8ff344
Author: Guillermo <guille411@hotmail.com>
Date:   Sun Nov 20 21:34:10 2016 -0300

    Correcion de errores, asignacion de footprints y ubicacion prelimilar de componentes.

commit 11aca1d1b0662f61689178e4ff9805f52a183f19
Author: Guillermo <guille411@hotmail.com>
Date:   Mon Nov 14 23:36:16 2016 -0300

    se agregaron casi todos los footprint faltan el conector del poncho, encoder y CNY70

commit 7751c03105789901edcf36aeaca6e37e7509f47b
Author: Guillermo <guille411@hotmail.com>
Date:   Sat Nov 12 18:12:24 2016 -0300

    Se completaron los circuitos esquematicos, falta revision.

commit d611465cffcc4c0f437b2e26dbb77b9760884785
Author: Guillermo <guille411@hotmail.com>
Date:   Fri Nov 11 00:27:14 2016 -0300

    Se dividio el esquematico en bloques, se agrego conexion a reles y potenciometro

commit d8644a0f8f4160e4bf12dbf2aed8f654130f1e11
Author: Guillermo <guille411@hotmail.com>
Date:   Sat Nov 5 18:02:02 2016 -0300

    se modificó el nombre de los archivos

commit aa5e39e9e3f638fcc2b052899e397575310de332
Author: Guillermo <guille411@hotmail.com>
Date:   Sat Nov 5 17:41:19 2016 -0300

    se agregaron archivos basicos para empezar a trabajar

commit d3c434b61f8c533b64f63e9bc1beb161fdb4123f
Author: guille411 <guille411@hotmail.com>
Date:   Sat Nov 5 17:26:06 2016 -0300

    Initial commit

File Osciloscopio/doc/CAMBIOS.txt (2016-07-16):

Historial de cambios realizados 
================================

Ver información de los commits del repositorio git.

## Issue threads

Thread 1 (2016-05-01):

Consulta: poncho CIAA-EDU para la enseñanza de programación de microcontroladores

fcladera, 2016-05-01:
Hola a todos,

Antes que nada, disculpas si este no es el lugar correcto para publicar
este mensaje. He solicitado adhesión al grupo EDUCIAA en google groups,
pero todavía no tengo respuesta.

Mi nombre es Fernando Cladera. Soy ingeniero en Mecatrónica, y
actualmente estoy participando como adscripto en la cátedra de
Microcontroladores y Electrónica de Potencia de la carrera de Ing.
Mecatrónica,  Facultad de Ingeniería, UNCuyo.

Nos gustaría dentro de la cátedra migrar de Microchip a la EDU-CIAA-NXP.
La plataforma presenta varias ventajas desde el punto de vista de la
enseñanza, por ejemplo el debug en tiempo de ejecución utilizando
OpenOCD, el hecho de que sea ARM, el desarrollo de un RTOS específico
para la plataforma, entre otros. La idea es utilizar la placa "bare
metal" en un principio, para que los alumnos aprendan a escribir
drivers, utilizar periféricos y entender los principios de
funcionamiento de un microcontrolador.

Como parte del proyecto, creo que sería una buena idea contar con una
placa similar a un "Developer's Kit" [1], para montar la EDU-CIAA. Había
pensado agregar los siguientes componentes:

 - Potenciómetros
 - Integrados que implementen comunicación SPI e I2C (memorias, o
   sensores de temperatura/presión como LM75)
 - Interfaz RS232 con MAX232
 - Conector de red
 - Salida de potencia con MOSFET
 - Display LCD o 7 segmentos
 - ULN20003 para manejar pequeños motores CC o PaP
 - ...?

Había pensado utilizar componentes convencionales (through-hole) para
facilitar la adquisición de componentes y el montaje en la placa (para
que pueda ser realizado por los alumnos). Además, espero desarrollar una
placa clase 2 o 3, para que sea más sencillo fabricarla.

¿Es interesante una contribución de este tipo? ¿Qué otro componente
consideran que podría ser útil?

He visto que hay un problema de licencia con el poncho "Interfaz de
Usuario". Espero que este desarrollo tenga las licencias adecuadas para
poder agregarlo al repositorio de ponchos.

Saludos,

Fernando Cladera
(fcladera [at] fcladera.com)

[1]: http://www.embeddedartists.com/products/kits/lpc2468_kit.php

[1]: http://www.embeddedartists.com/products/kits/lpc2468_kit.php

pridolfi, 2016-05-02:
Me parece buena idea. Lo que sí yo intentaría mantener el formato de poncho, sin extenderme demasiado en las dimensiones del PCB. Si querés andá armándolo en KiCad y te damos una mano para revisarlo.
Saludos!

fcladera, 2016-05-02:
Gracias Pablo por la rápida respuesta.

Seguimos la discusión por el grupo para evitar duplicados.

https://groups.google.com/forum/#!topic/embebidos32/JN9B8jVXWPc

Closed 2016-05-02.

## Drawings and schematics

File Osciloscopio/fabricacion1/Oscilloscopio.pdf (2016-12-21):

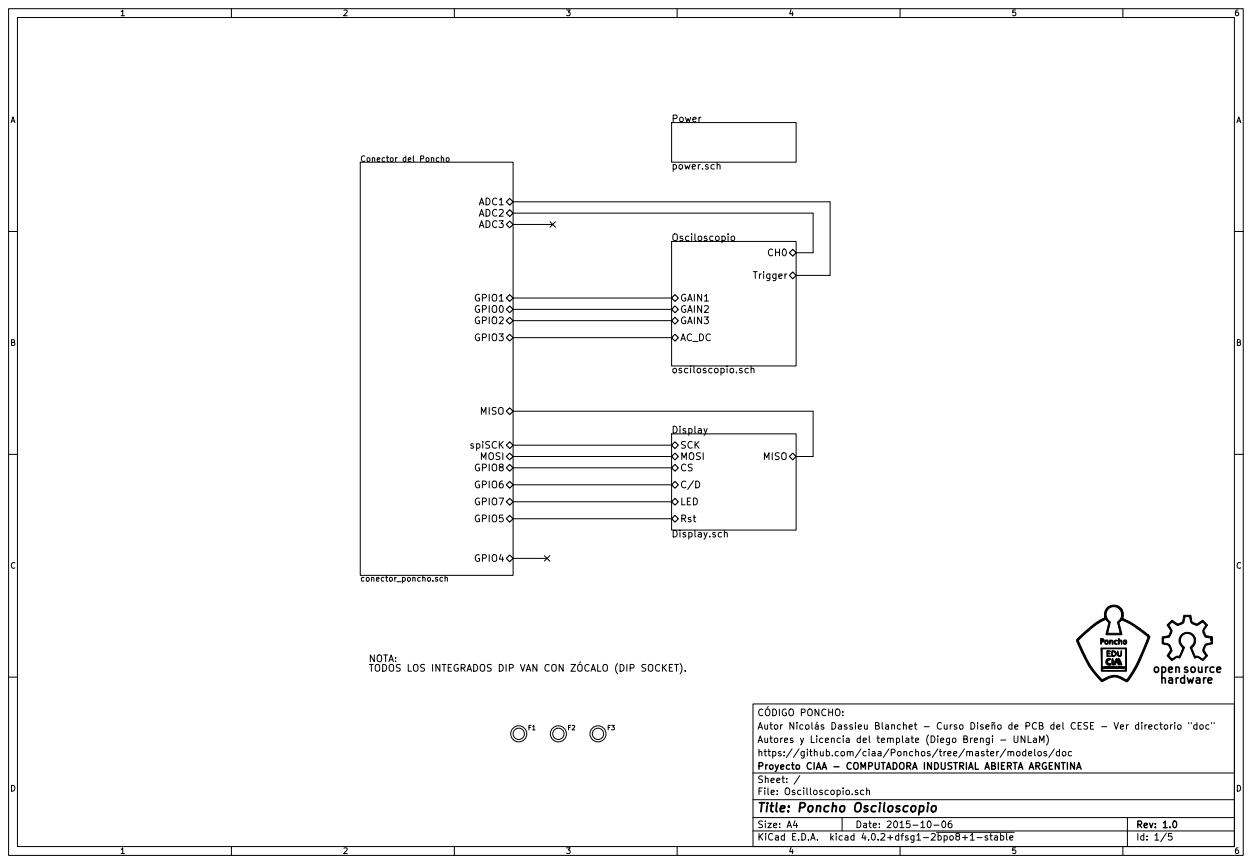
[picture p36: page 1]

NOTA:
TODOS LOS INTEGRADOS DIP VAN CON ZÓCALO (DIP SOCKET).

Autores y Licencia del template (Diego Brengi - UNLaM) Autor Nicolás Dassieu Blanchet - Curso Diseño de PCB del CESE - Ver directorio "doc" CÓDIGO PONCHO:

https://github.com/ciaa/Ponchos/tree/master/modelos/doc
File: Oscilloscopio.sch Sheet: / Proyecto CIAA - COMPUTADORA INDUSTRIAL ABIERTA ARGENTINA

Id: 1/5 Title: Poncho Osciloscopio

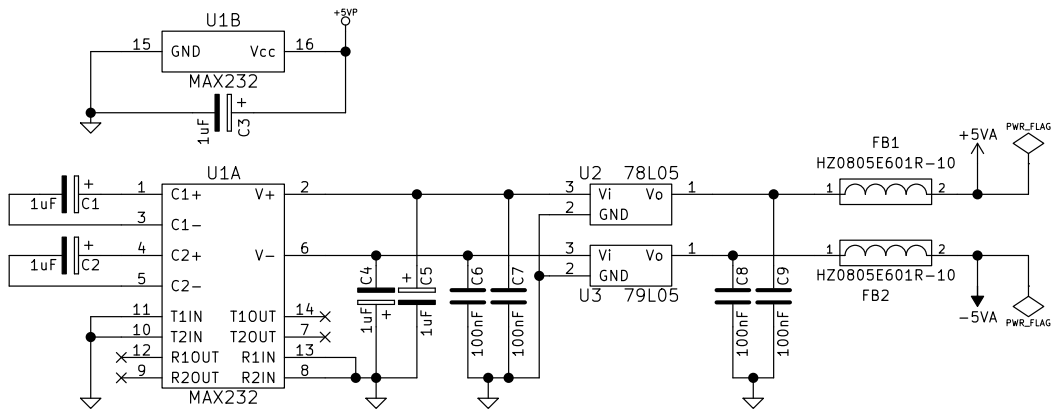
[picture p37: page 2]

https://github.com/ciaa/Ponchos/tree/master/modelos/doc
File: power.sch Sheet: /Power/ Proyecto CIAA - COMPUTADORA INDUSTRIAL ABIERTA ARGENTINA

Id: 2/5 Title: Poncho Osciloscopio

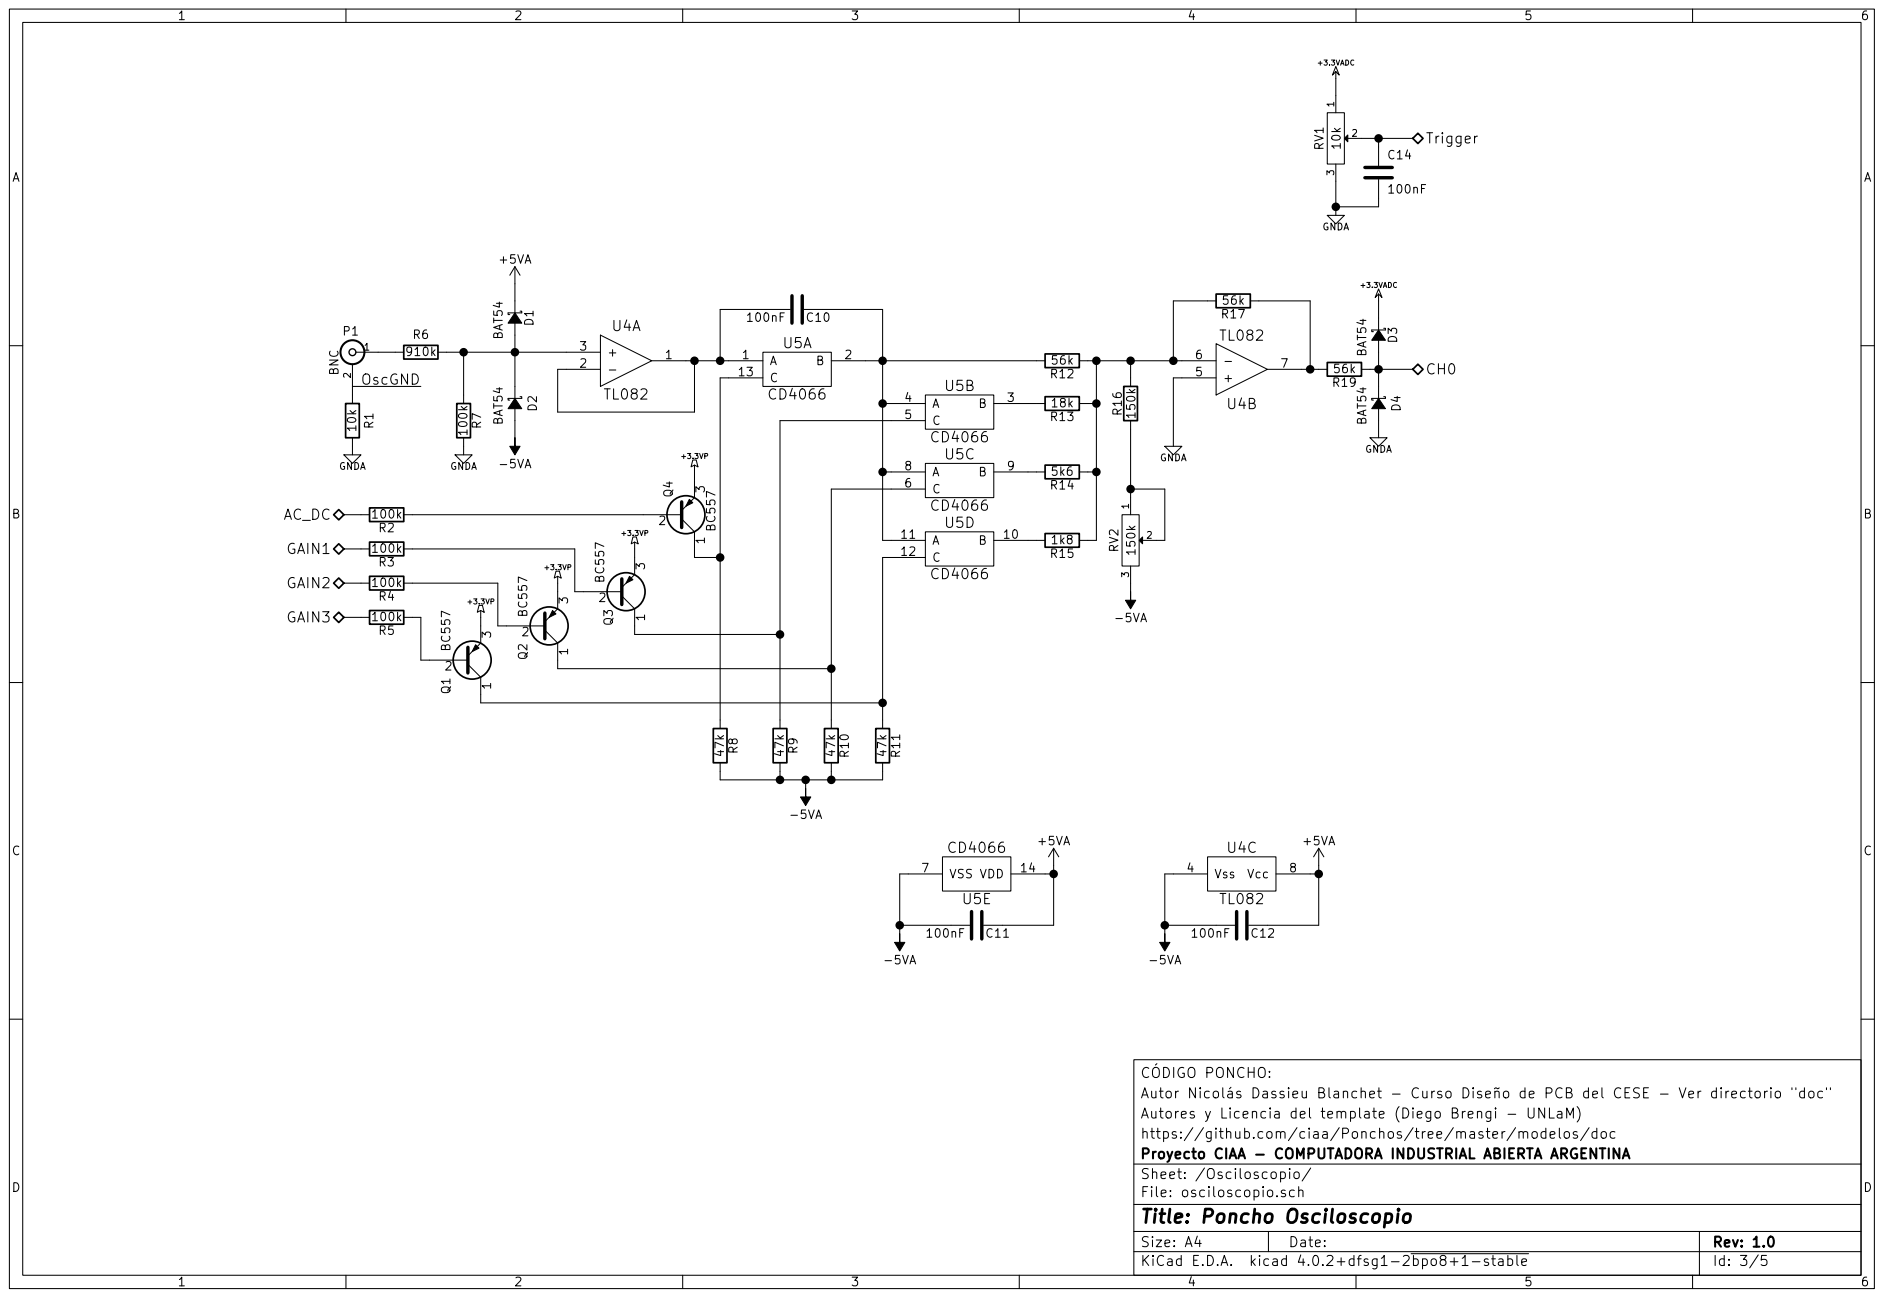
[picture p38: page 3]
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

https://github.com/ciaa/Ponchos/tree/master/modelos/doc
Proyecto CIAA - COMPUTADORA INDUSTRIAL ABIERTA ARGENTINA
Sheet: /Osciloscopio/
File: osciloscopio.sch
Id: 3/5 Title: Poncho Osciloscopio

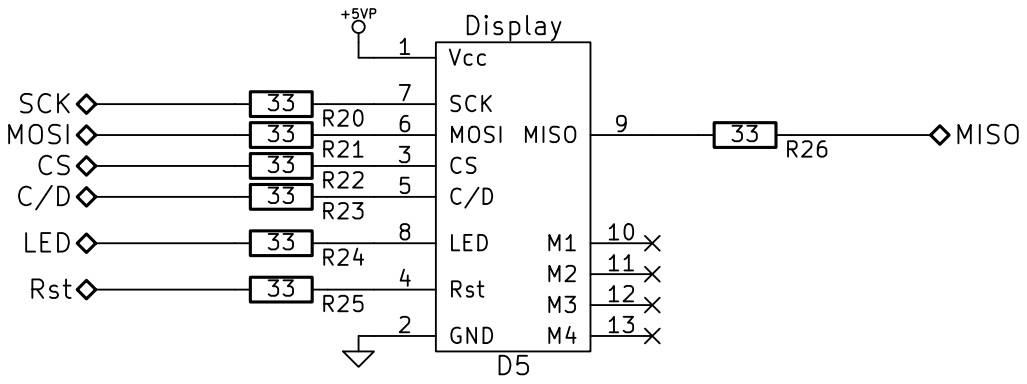
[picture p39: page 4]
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

https://github.com/ciaa/Ponchos/tree/master/modelos/doc
Proyecto CIAA - COMPUTADORA INDUSTRIAL ABIERTA ARGENTINA
Sheet: /Display/
File: Display.sch
Id: 4/5 Title: Poncho Osciloscopio

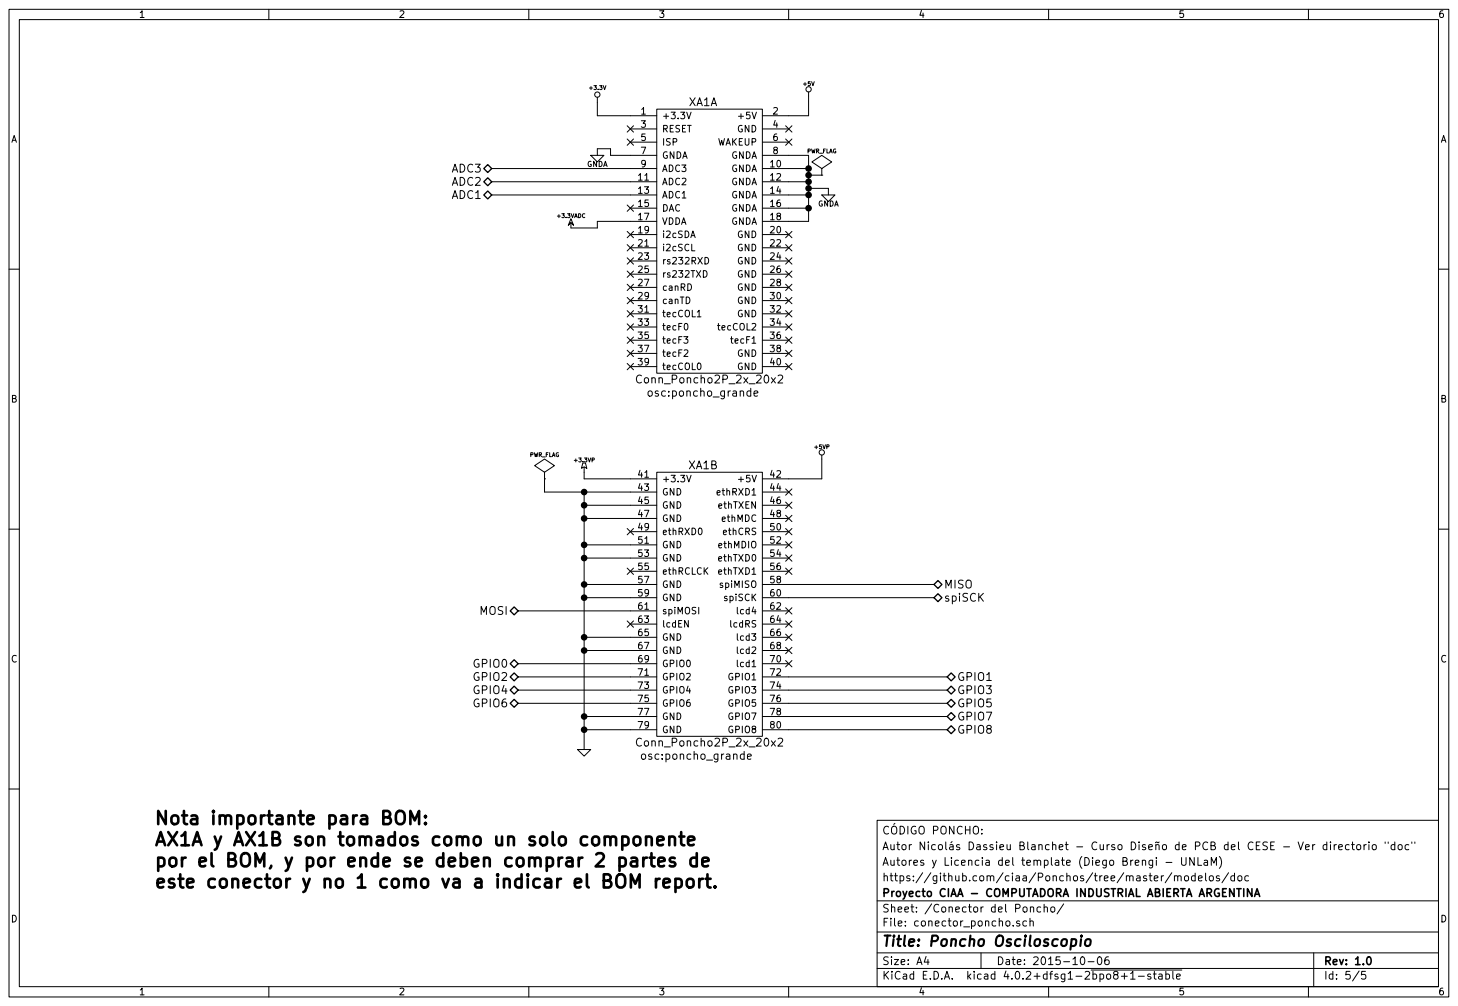
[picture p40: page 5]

Nota importante para BOM:
AX1A y AX1B son tomados como un solo componente
por el BOM, y por ende se deben comprar 2 partes de
este conector y no 1 como va a indicar el BOM report.

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

https://github.com/ciaa/Ponchos/tree/master/modelos/doc
File: conector_poncho.sch Sheet: /Conector del Poncho/ Proyecto CIAA - COMPUTADORA INDUSTRIAL ABIERTA ARGENTINA

Id: 5/5 Title: Poncho Osciloscopio

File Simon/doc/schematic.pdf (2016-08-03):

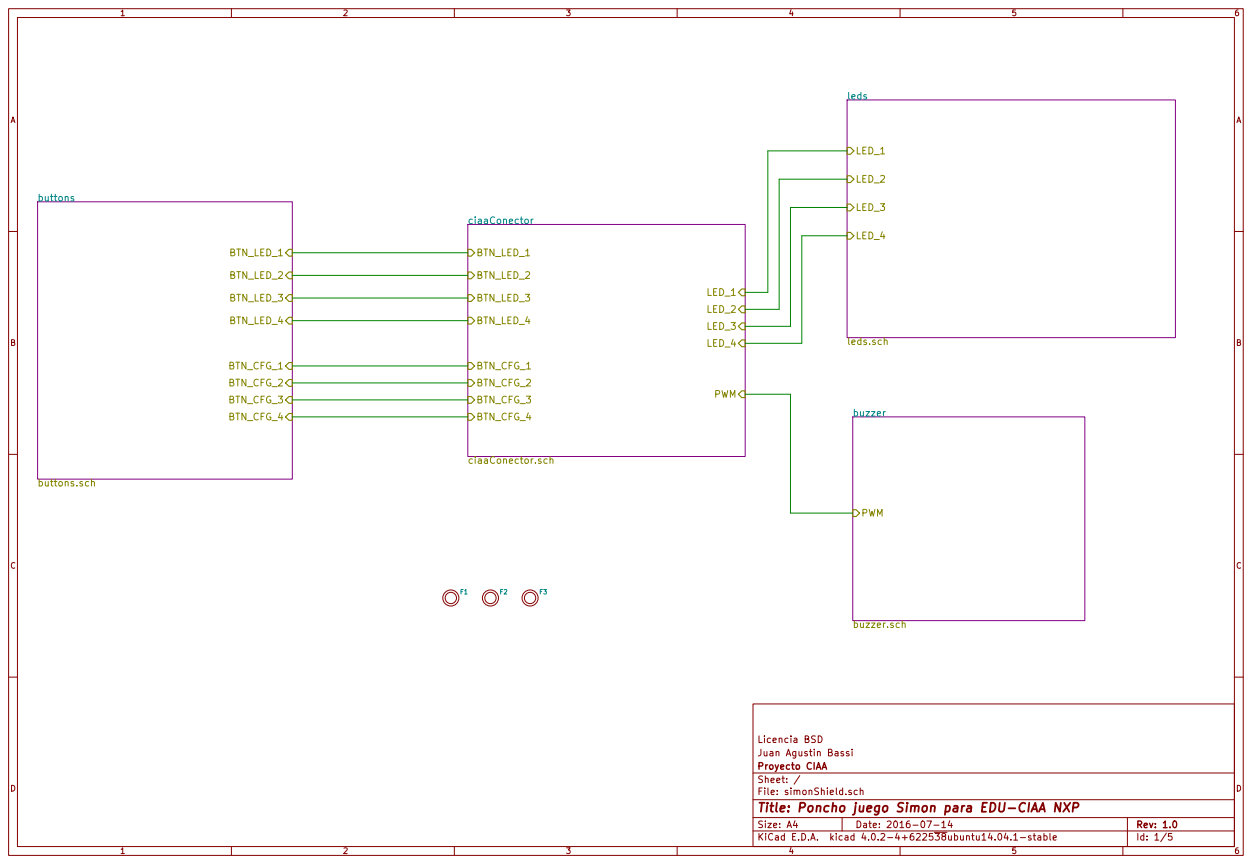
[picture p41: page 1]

Juan Agustin Bassi Licencia BSD

File: simonShield.sch Sheet: / Proyecto CIAA

Id: 1/5 Title: Poncho juego Simon para EDU-CIAA NXP

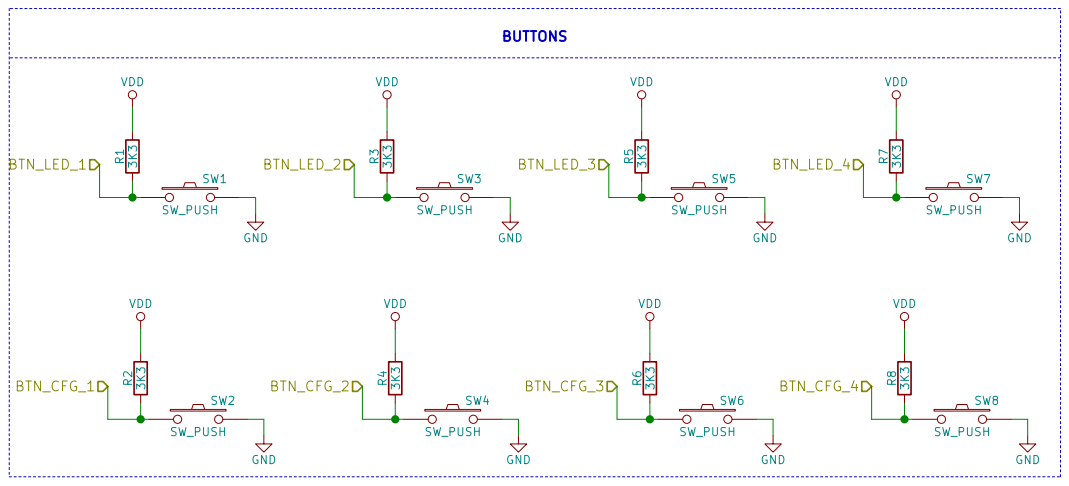
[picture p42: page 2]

Juan Agustin Bassi Licencia BSD

File: buttons.sch Sheet: /buttons/ Proyecto CIAA

Id: 2/5 Title: Poncho juego Simon para EDU-CIAA NXP

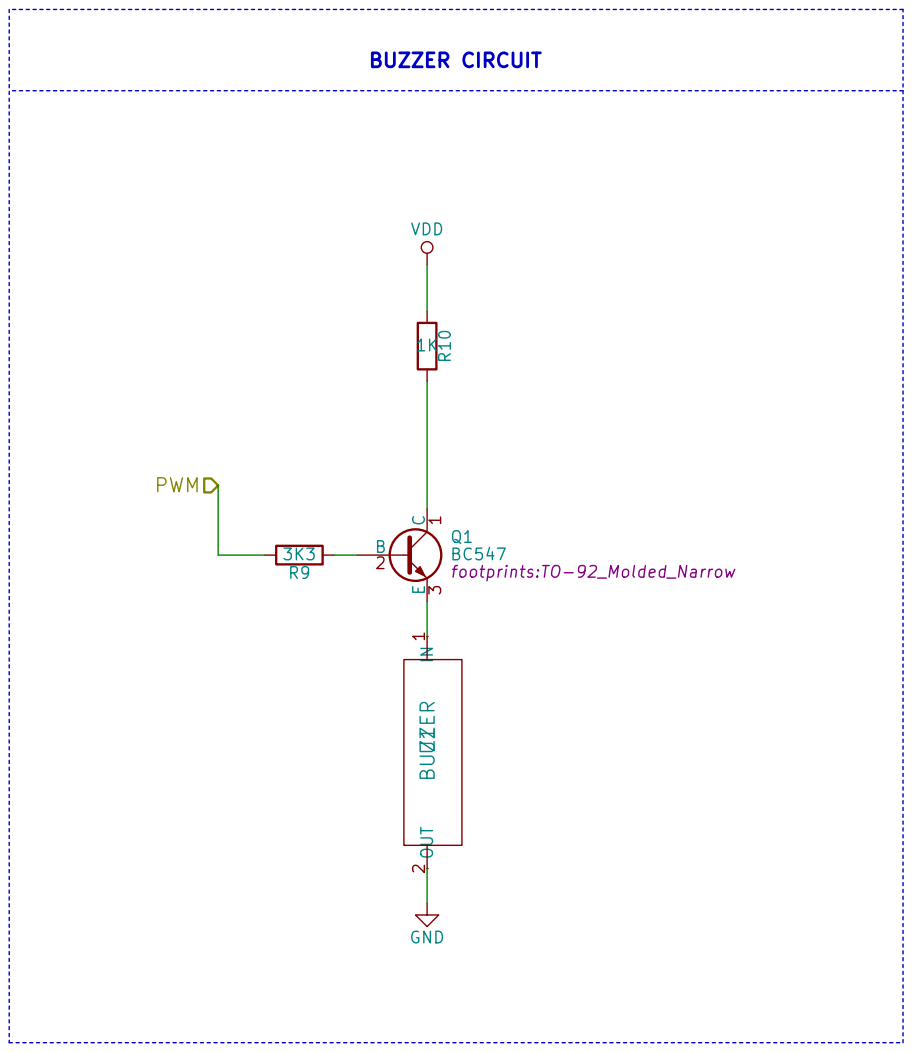
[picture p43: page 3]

1 OUT
Juan Agustin Bassi Licencia BSD IN

File: buzzer.sch Sheet: /buzzer/ Proyecto CIAA

Id: 3/5 Title: Poncho juego Simon para EDU-CIAA NXP

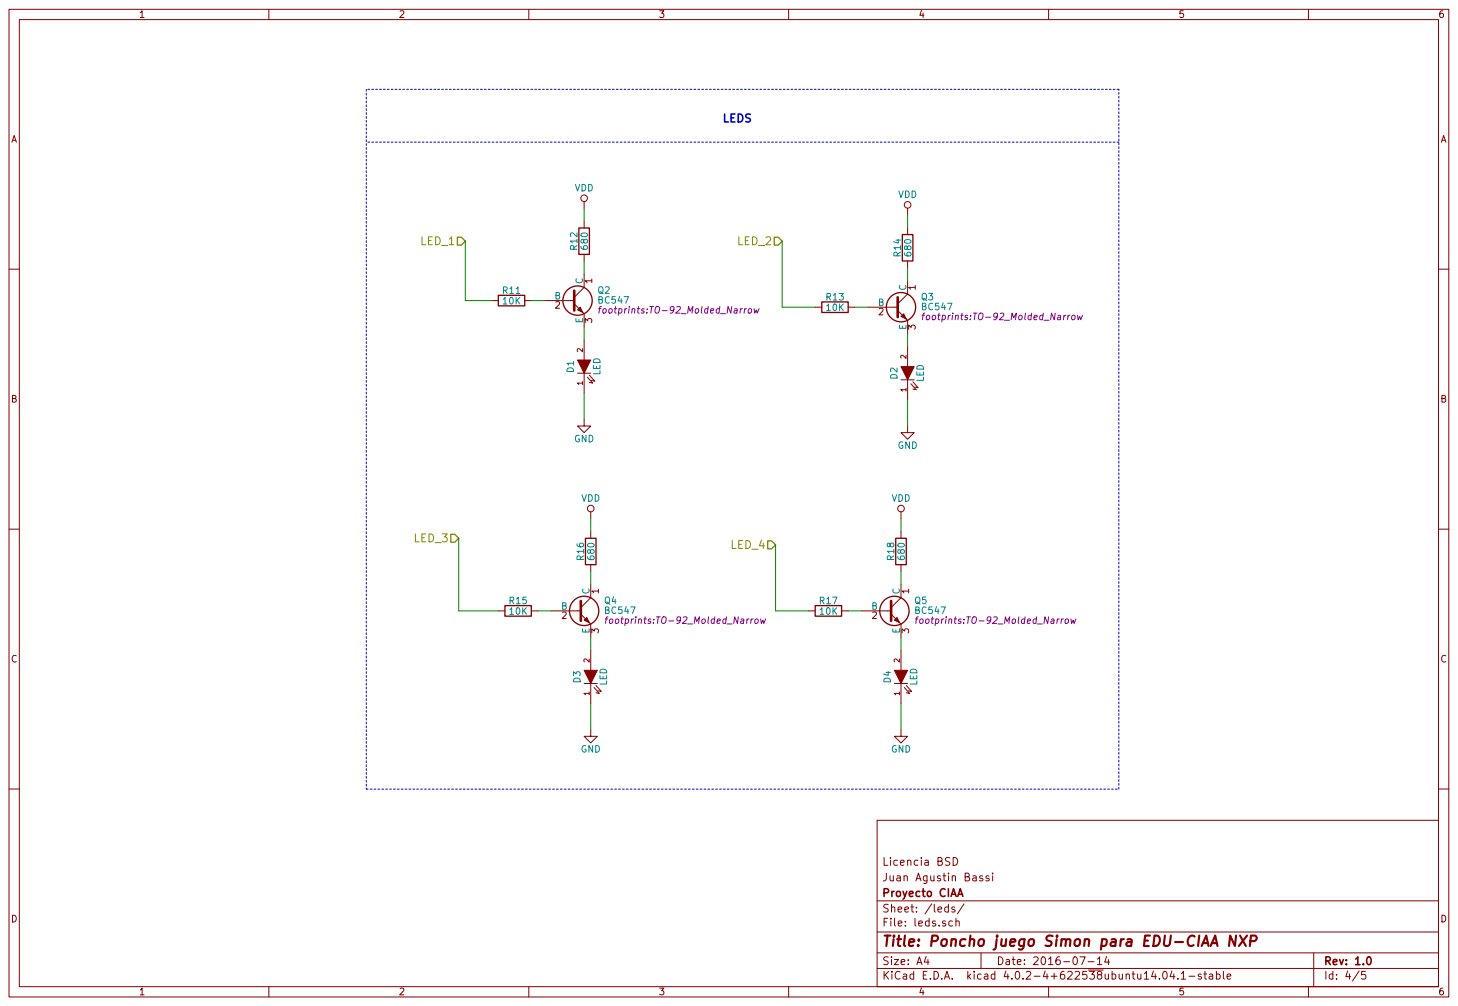
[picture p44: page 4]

Juan Agustin Bassi Licencia BSD

File: leds.sch Sheet: /leds/ Proyecto CIAA

Id: 4/5 Title: Poncho juego Simon para EDU-CIAA NXP

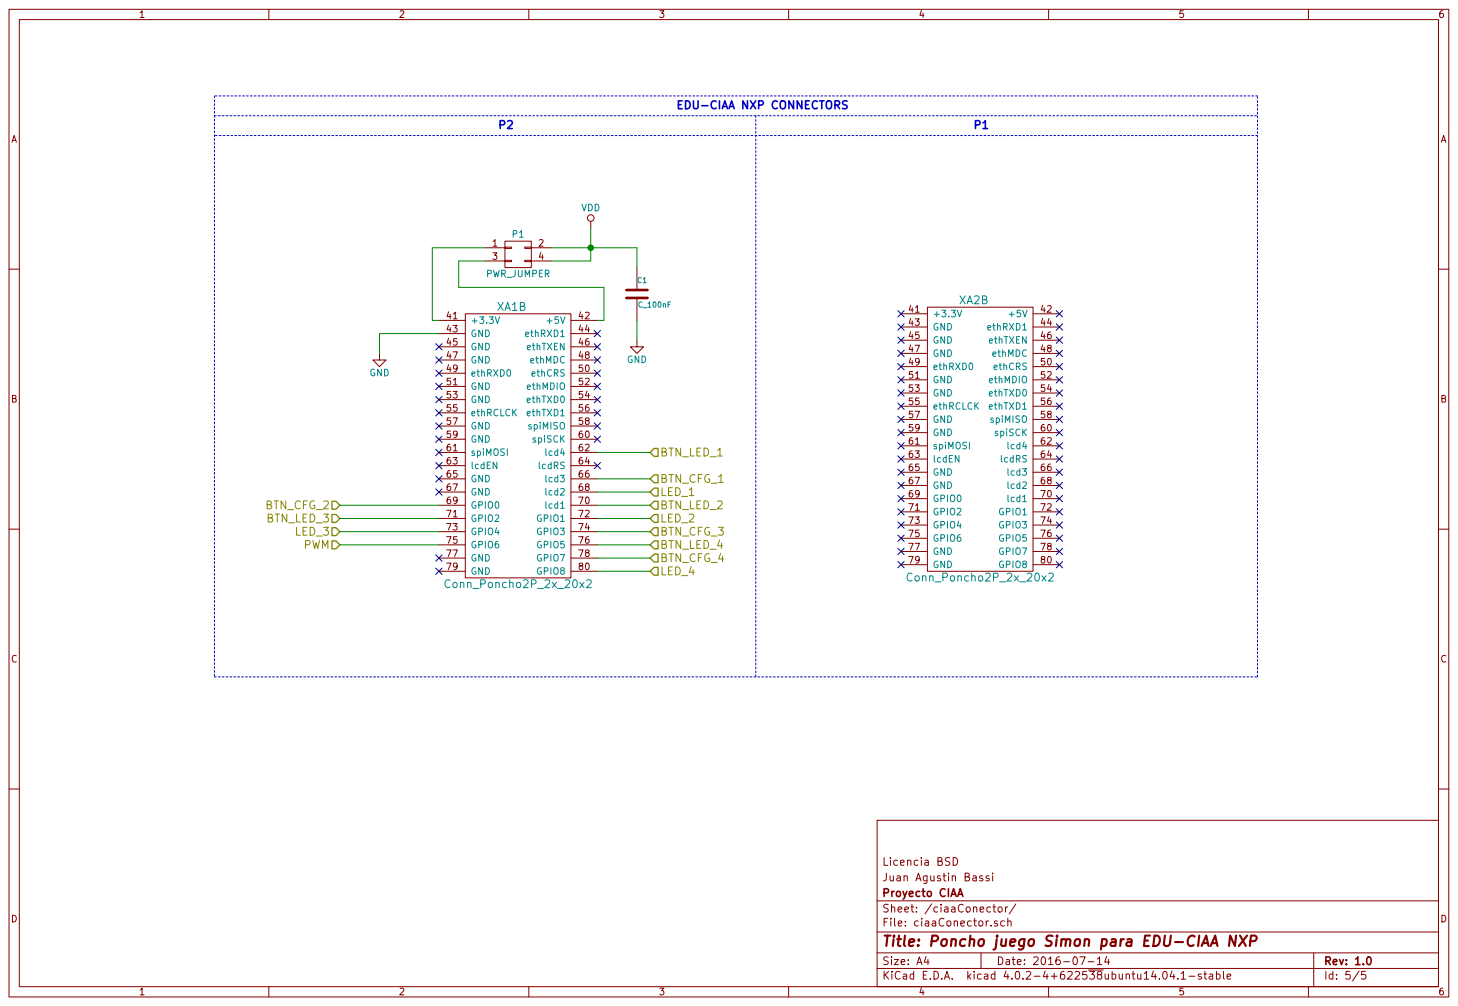
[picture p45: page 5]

EDU-CIAA NXP CONNECTORS

VDD

Juan Agustin Bassi Licencia BSD

File: ciaaConector.sch Sheet: /ciaaConector/ Proyecto CIAA

Id: 5/5 Title: Poncho juego Simon para EDU-CIAA NXP

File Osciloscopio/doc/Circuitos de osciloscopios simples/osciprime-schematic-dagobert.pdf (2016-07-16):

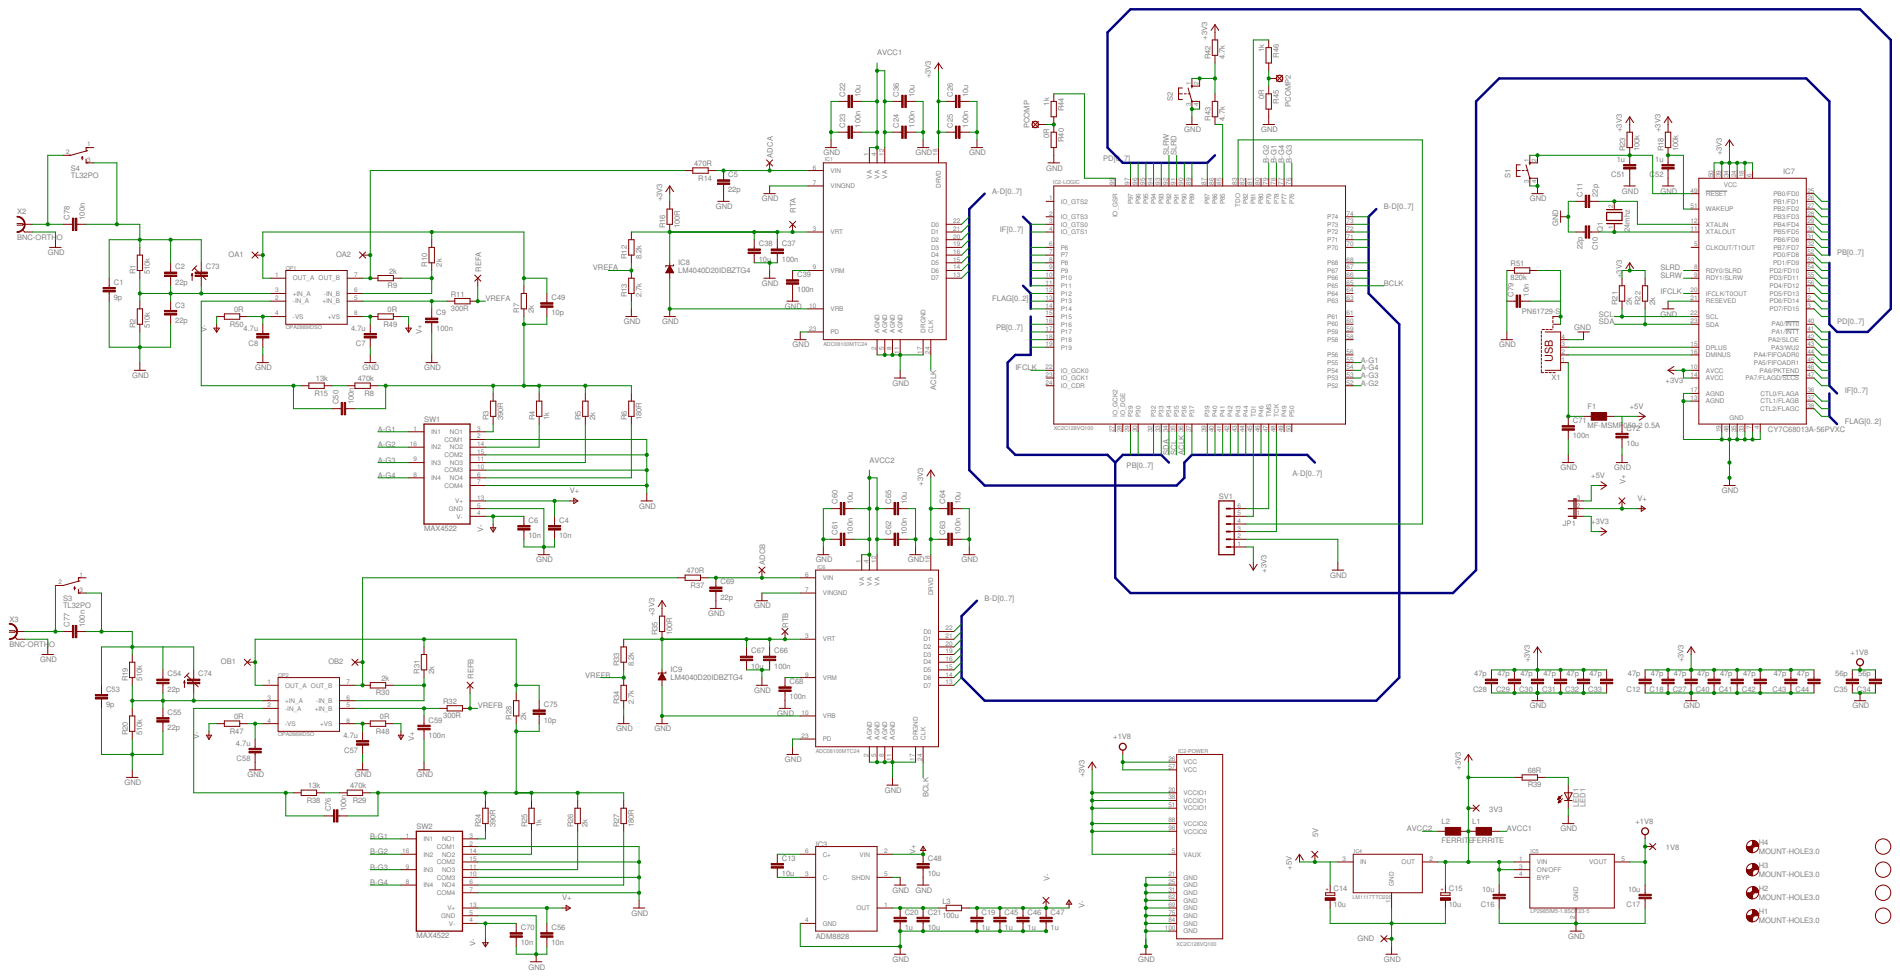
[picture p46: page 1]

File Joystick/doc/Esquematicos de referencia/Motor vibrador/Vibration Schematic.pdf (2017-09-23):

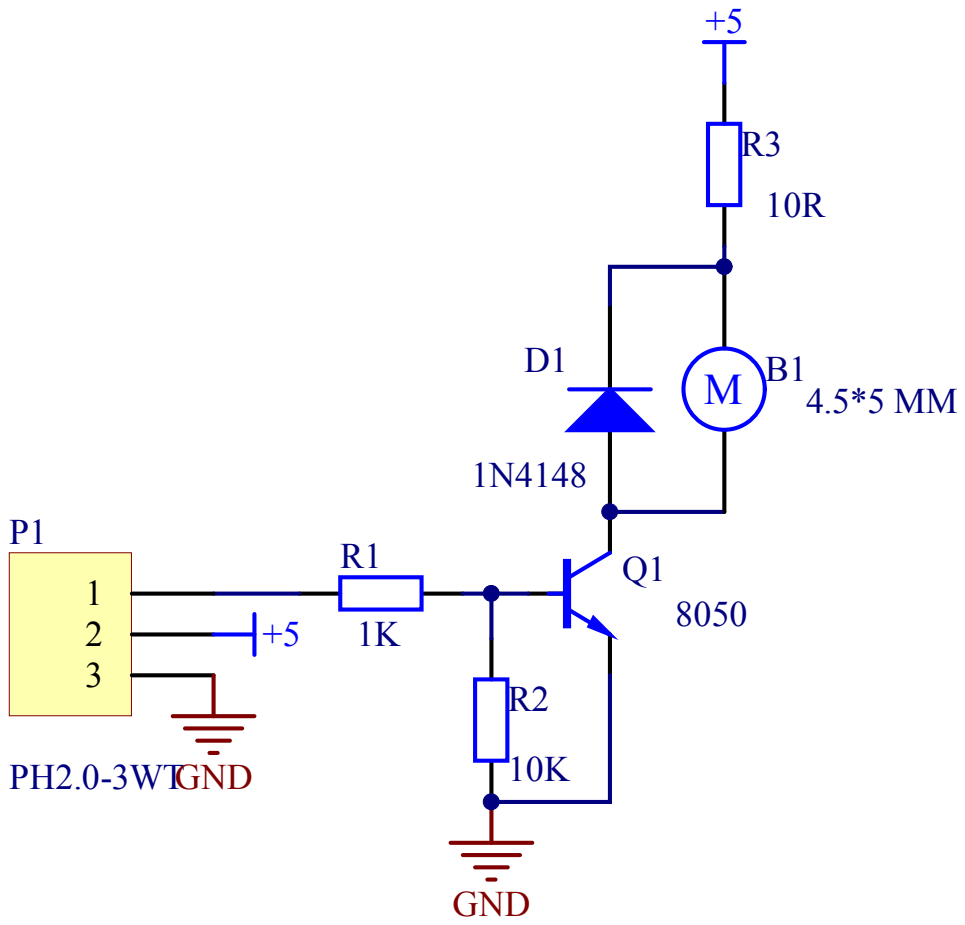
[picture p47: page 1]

Title: Vibration | SKU: DFR0440

Drawn: DongZi-CD | Revision: V1.0 | Size: A3

Date: 2016/5/20 | Time: 13:23:18

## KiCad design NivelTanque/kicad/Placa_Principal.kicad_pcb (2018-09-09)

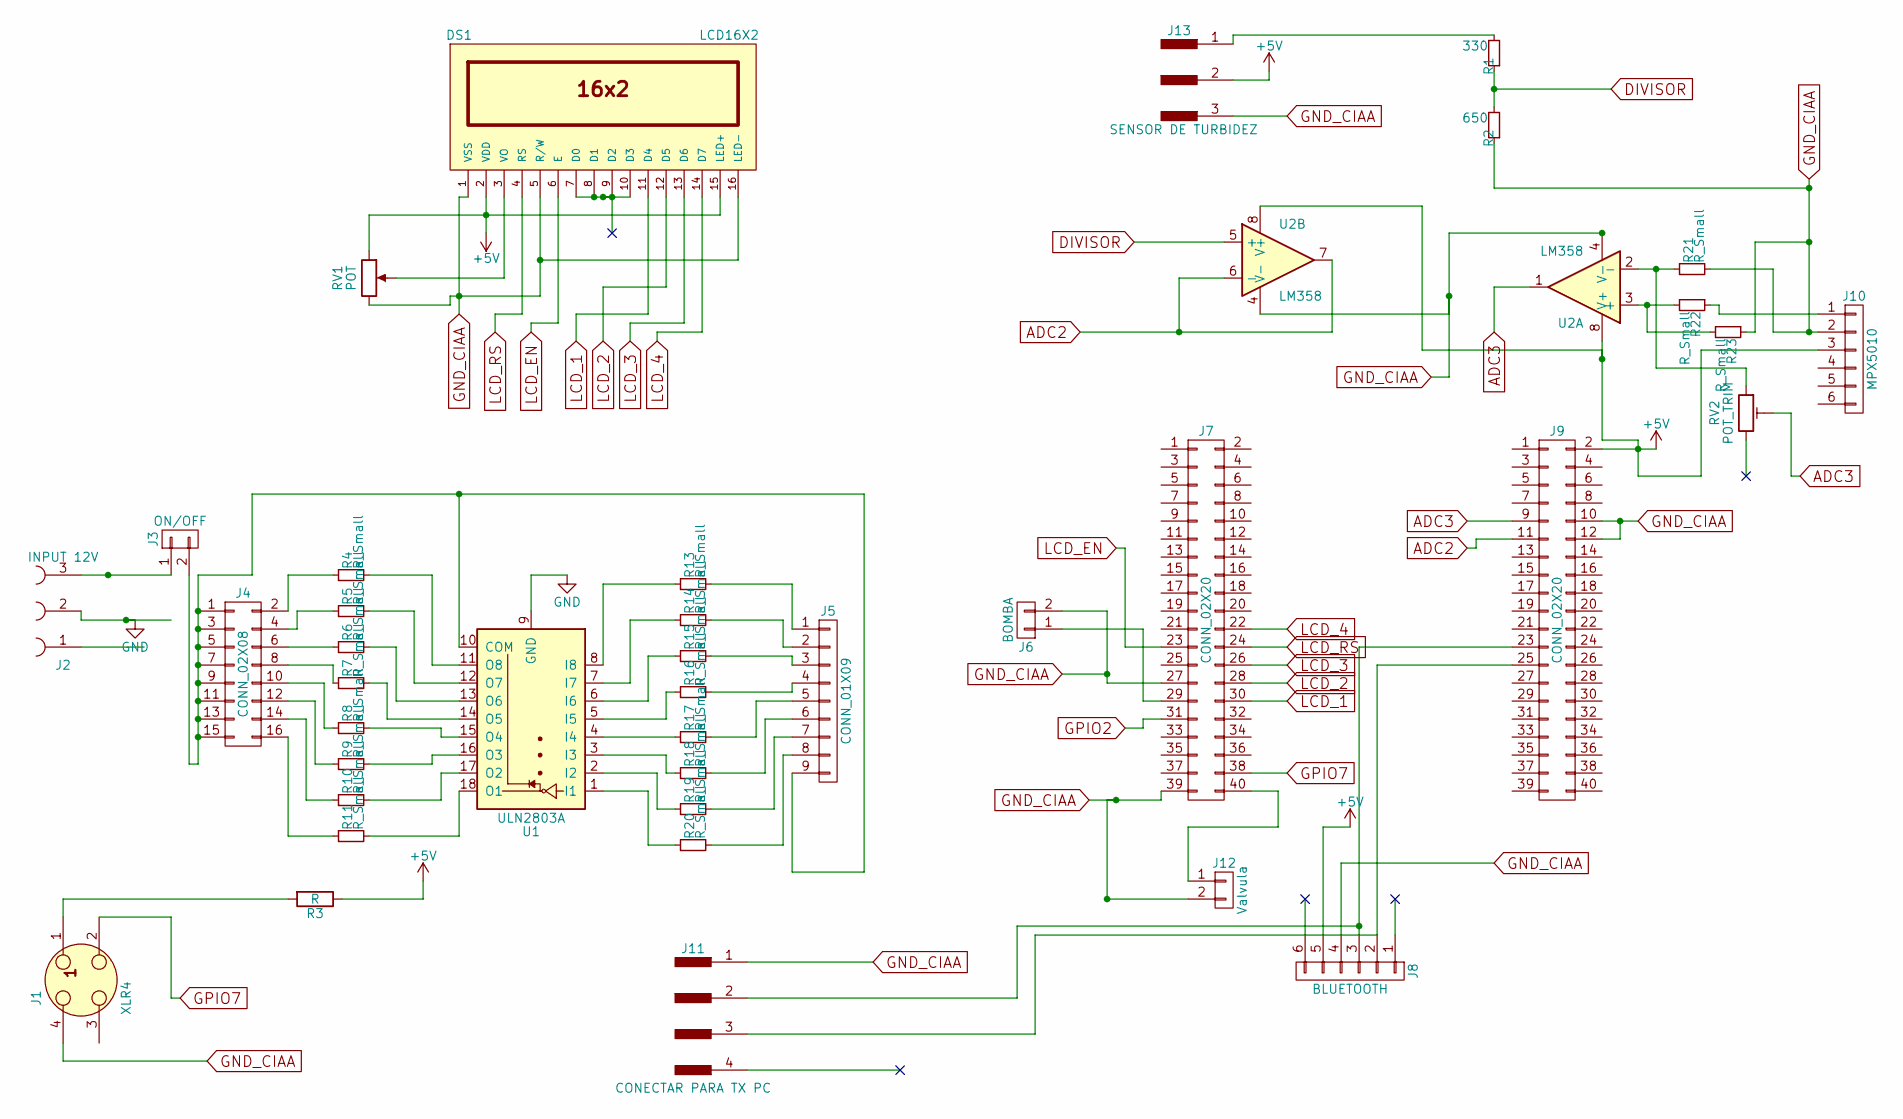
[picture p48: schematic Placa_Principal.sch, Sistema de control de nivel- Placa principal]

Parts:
DS1: LCD16X2; JST_XH_B16B-XH-A_16x2.50mm_Straight
J1: XLR4; Diode_Bridge_DIP-4_W7.62mm_P5.08mm
J2: INPUT 12V; TerminalBlock_bornier-3_P5.08mm
J3: ON/OFF; TerminalBlock_bornier-2_P5.08mm
J4: CONN_02X08; Pin_Header_Straight_2x08_Pitch2.54mm
J5: CONN_01X09; Pin_Header_Straight_1x09_Pitch2.54mm
J6: BOMBA; TerminalBlock_bornier-2_P5.08mm
J7, J9: CONN_02X20; Pin_Header_Straight_2x20_Pitch2.54mm
J8: BLUETOOTH; Pin_Header_Straight_1x06_Pitch2.54mm
J10: MPX5010; Pin_Header_Straight_1x06_Pitch2.54mm
J11: CONECTAR PARA TX PC; Pin_Header_Straight_1x04_Pitch2.54mm
J12: Valvula; TerminalBlock_bornier-2_P5.08mm
J13: SENSOR DE TURBIDEZ; Pin_Header_Straight_1x03_Pitch2.54mm
R1: 330; R_Axial_DIN0207_L6.3mm_D2.5mm_P15.24mm_Horizontal
R2: 650; R_Axial_DIN0207_L6.3mm_D2.5mm_P15.24mm_Horizontal
R3: R; R_Axial_DIN0207_L6.3mm_D2.5mm_P15.24mm_Horizontal
R4, R5, R6, R7, R8, R9, R10, R11, R13, R14, R15, R16, R17, R18, R19, R20, R21, R22, R23: R_Small; R_Axial_DIN0207_L6.3mm_D2.5mm_P15.24mm_Horizontal
RV1: POT; TerminalBlock_bornier-3_P5.08mm
RV2: POT_TRIM; Potentiometer_Trimmer_Bourns_3296W
U1: ULN2803A; DIP-18_W7.62mm_LongPads
U2: LM358; DIP-8_W7.62mm_LongPads

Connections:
+5V: DS1.2 (VDD), DS1.15 (LED+), J8.5, J9.2, J10.3, J13.2, R3.1, RV1.1, U2.8 (V+)
ADC2: J9.11, U2.6 (-), U2.7
ADC3: J9.9, RV2.2, U2.1
DIVISOR: R1.1, R2.2, U2.5 (+)
GND: J2.2, U1.9 (GND)
GND_CIAA: DS1.1 (VSS), DS1.5 (R/W), DS1.16 (LED-), J1.4, J6.2, J7.27, J7.39, J8.4, J9.10, J9.12, J10.2, J11.1, J12.2, J13.3, R2.1, R21.2, R23.1, RV1.3, U2.4 (V-)
GPIO2: J7.31
GPIO7: J1.2, J7.38
LCD_1: DS1.11 (D4), J7.30
LCD_2: DS1.12 (D5), J7.28
LCD_3: DS1.13 (D6), J7.26
LCD_4: DS1.14 (D7), J7.22
LCD_EN: DS1.6 (E), J7.23
LCD_RS: DS1.4 (RS), J7.24
unnamed: DS1.3 (VO), RV1.2
unnamed: DS1.7 (D0), DS1.8 (D1), DS1.9 (D2), DS1.10 (D3)
unnamed: J1.1, R3.2
unnamed: J2.3, J3.1
unnamed: J3.2, J4.1, J4.3, J4.5, J4.7, J4.9, J4.11, J4.13, J4.15, J5.9, U1.10 (COM)
unnamed: J4.2, R4.1
unnamed: J4.4, R5.1
unnamed: J4.6, R6.1
unnamed: J4.8, R7.1
unnamed: J4.10, R8.1
unnamed: J4.12, R9.1
unnamed: J4.14, R10.1
unnamed: J4.16, R11.1
unnamed: J5.1, R13.2
unnamed: J5.2, R14.2
unnamed: J5.3, R15.2
unnamed: J5.4, R16.2
unnamed: J5.5, R17.2
unnamed: J5.6, R18.2
unnamed: J5.7, R19.2
unnamed: J5.8, R20.2
unnamed: J6.1, J7.29
unnamed: J10.1, R22.1
unnamed: J8.3, J9.23, J11.2
unnamed: J8.2, J9.25, J11.3
unnamed: J7.40, J12.1
unnamed: J13.1, R1.2
unnamed: R4.2, U1.11 (O8)
unnamed: R5.2, U1.12 (O7)
unnamed: R6.2, U1.13 (O6)
unnamed: R7.2, U1.14 (O5)
unnamed: R8.2, U1.15 (O4)
unnamed: R9.2, U1.16 (O3)
unnamed: R10.2, U1.17 (O2)
unnamed: R11.2, U1.18 (O1)
unnamed: R13.1, U1.8 (I8)
unnamed: R14.1, U1.7 (I7)
unnamed: R15.1, U1.6 (I6)
unnamed: R16.1, U1.5 (I5)
unnamed: R17.1, U1.4 (I4)
unnamed: R18.1, U1.3 (I3)
unnamed: R19.1, U1.2 (I2)
unnamed: R20.1, U1.1 (I1)
unnamed: R21.1, RV2.1, U2.2 (-)
unnamed: R22.2, R23.2, U2.3 (+)

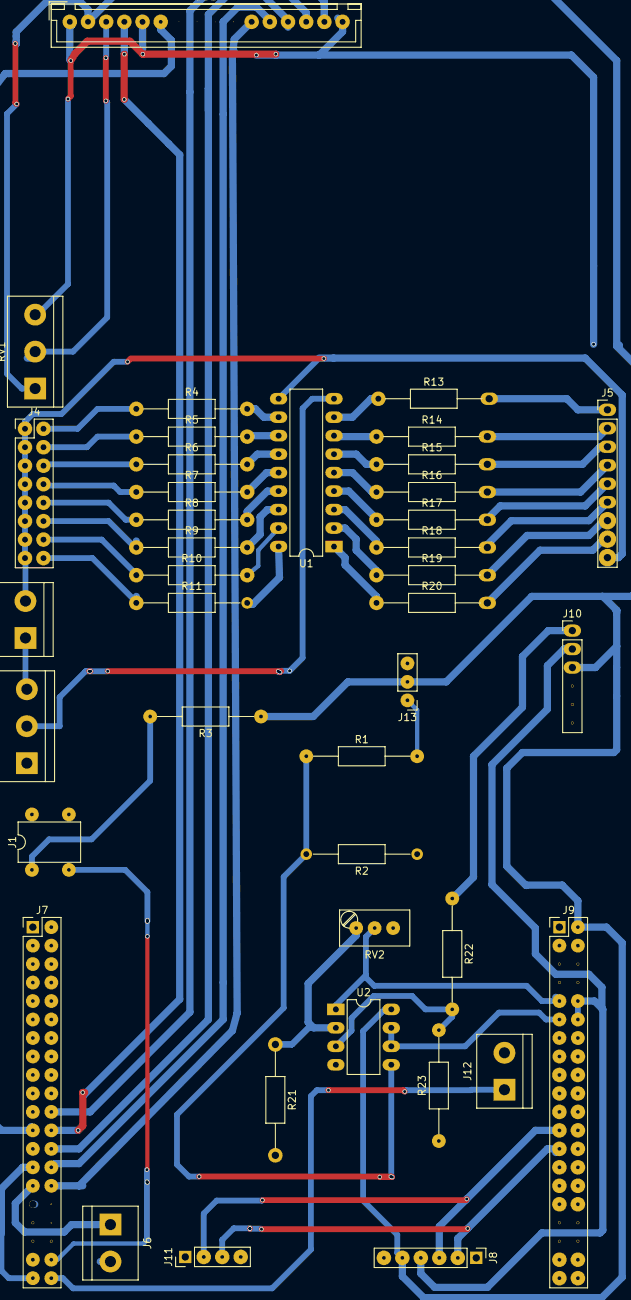
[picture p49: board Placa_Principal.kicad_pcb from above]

Board: 2 copper layers, 40 parts (0 on the bottom side), 58 nets.

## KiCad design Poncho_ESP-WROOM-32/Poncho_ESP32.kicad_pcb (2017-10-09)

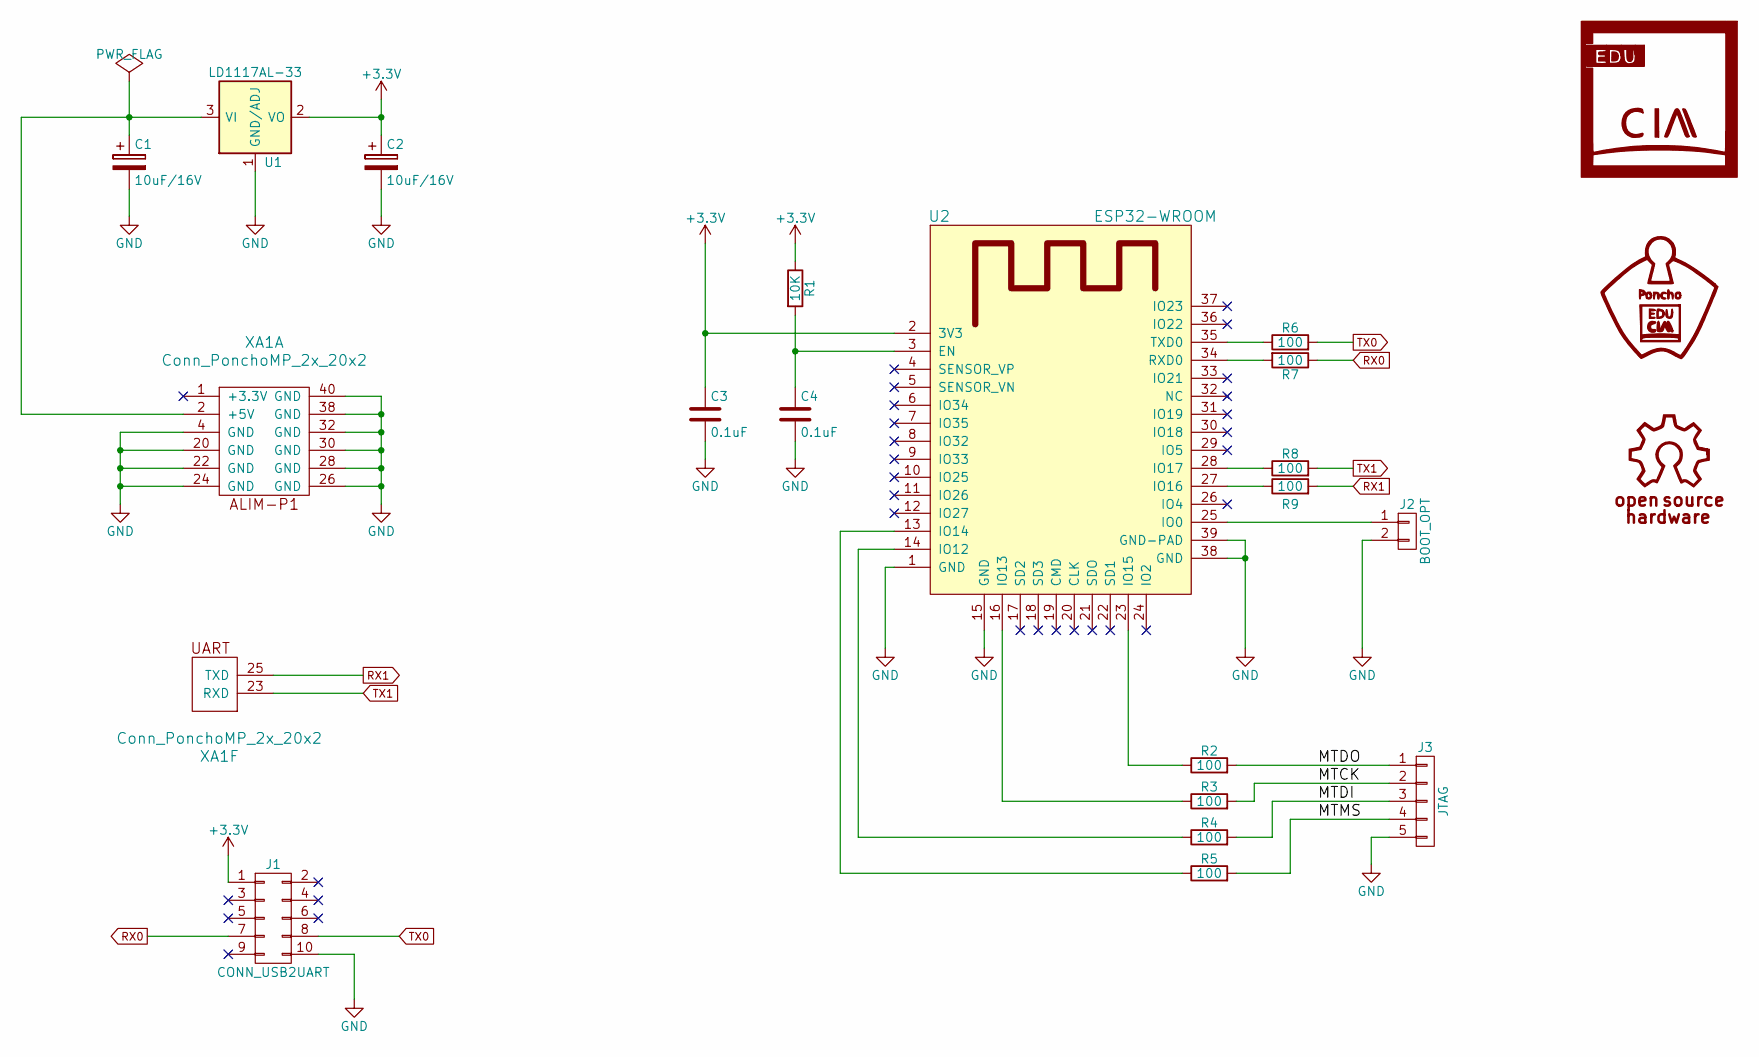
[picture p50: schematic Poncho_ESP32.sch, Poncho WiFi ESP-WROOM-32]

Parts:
C1, C2: 10uF/16V; CP_Elec_4x5.3
C3, C4: 0.1uF; C_0805_HandSoldering
J1: CONN_USB2UART; Socket_Strip_Angled_2x05_Pitch2.54mm
J2: BOOT_OPT; Pin_Header_Straight_1x02_Pitch2.54mm
J3: JTAG; Pin_Header_Straight_1x05_Pitch2.54mm
R1: 10K; R_0805_HandSoldering
R2, R3, R4, R5, R6, R7, R8, R9: 100; R_0805_HandSoldering
U1: LD1117AL-33; SOT-223
U2: ESP32-WROOM
XA1: Conn_PonchoMP_2x_20x2; Conn_Poncho_Derecha_Sin_Pin_Desc

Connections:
+3V3: C2.1, C3.1, J1.1, R1.1, U1.2 (VO), U1.4 (VO), U2.2 (3V3)
/MTCK: J3.2, R3.2
/MTDI: J3.3, R4.2
/MTDO: J3.1, R2.2
/MTMS: J3.4, R5.2
GND: C1.2, C2.2, C3.2, C4.2, J1.10, J2.2, J3.5, U1.1 (GND/ADJ), U2.1 (GND), U2.15 (GND), U2.38 (GND), U2.39 (GND-PAD), XA1.4 (GND), XA1.20 (GND), XA1.22 (GND), XA1.24 (GND), XA1.26 (GND), XA1.28 (GND), XA1.30 (GND), XA1.32 (GND), XA1.38 (GND), XA1.40 (GND)
unnamed: C1.1, U1.3 (VI), XA1.2 (+5V)
unnamed: C4.1, R1.2, U2.3 (EN)
unnamed: J2.1, U2.25 (IO0)
unnamed: R2.1, U2.23 (IO15)
unnamed: R3.1, U2.16 (IO13)
unnamed: R4.1, U2.14 (IO12)
unnamed: R5.1, U2.13 (IO14)
unnamed: R6.1, U2.35 (TXD0)
unnamed: R7.2, U2.34 (RXD0)
unnamed: R8.1, U2.28 (IO17)
unnamed: R9.1, U2.27 (IO16)
RX0: J1.7, R7.1
RX1: R9.2, XA1.25 (TXD)
TX0: J1.8, R6.2
TX1: R8.2, XA1.23 (RXD)

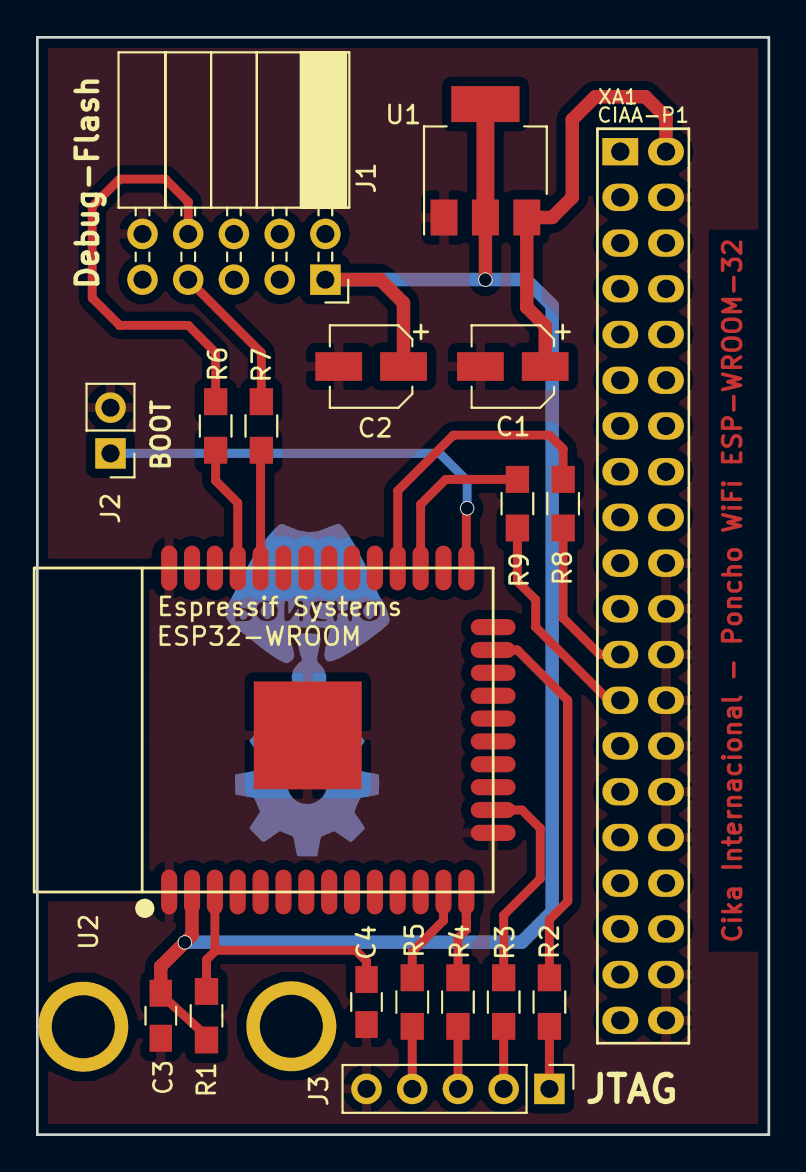
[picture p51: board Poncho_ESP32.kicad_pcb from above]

Board: 2 copper layers, 40.6 x 61.0 mm, 21 parts (0 on the bottom side), 21 nets.

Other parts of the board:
H2, H2#2: PCB_HOLE; Led_Hole

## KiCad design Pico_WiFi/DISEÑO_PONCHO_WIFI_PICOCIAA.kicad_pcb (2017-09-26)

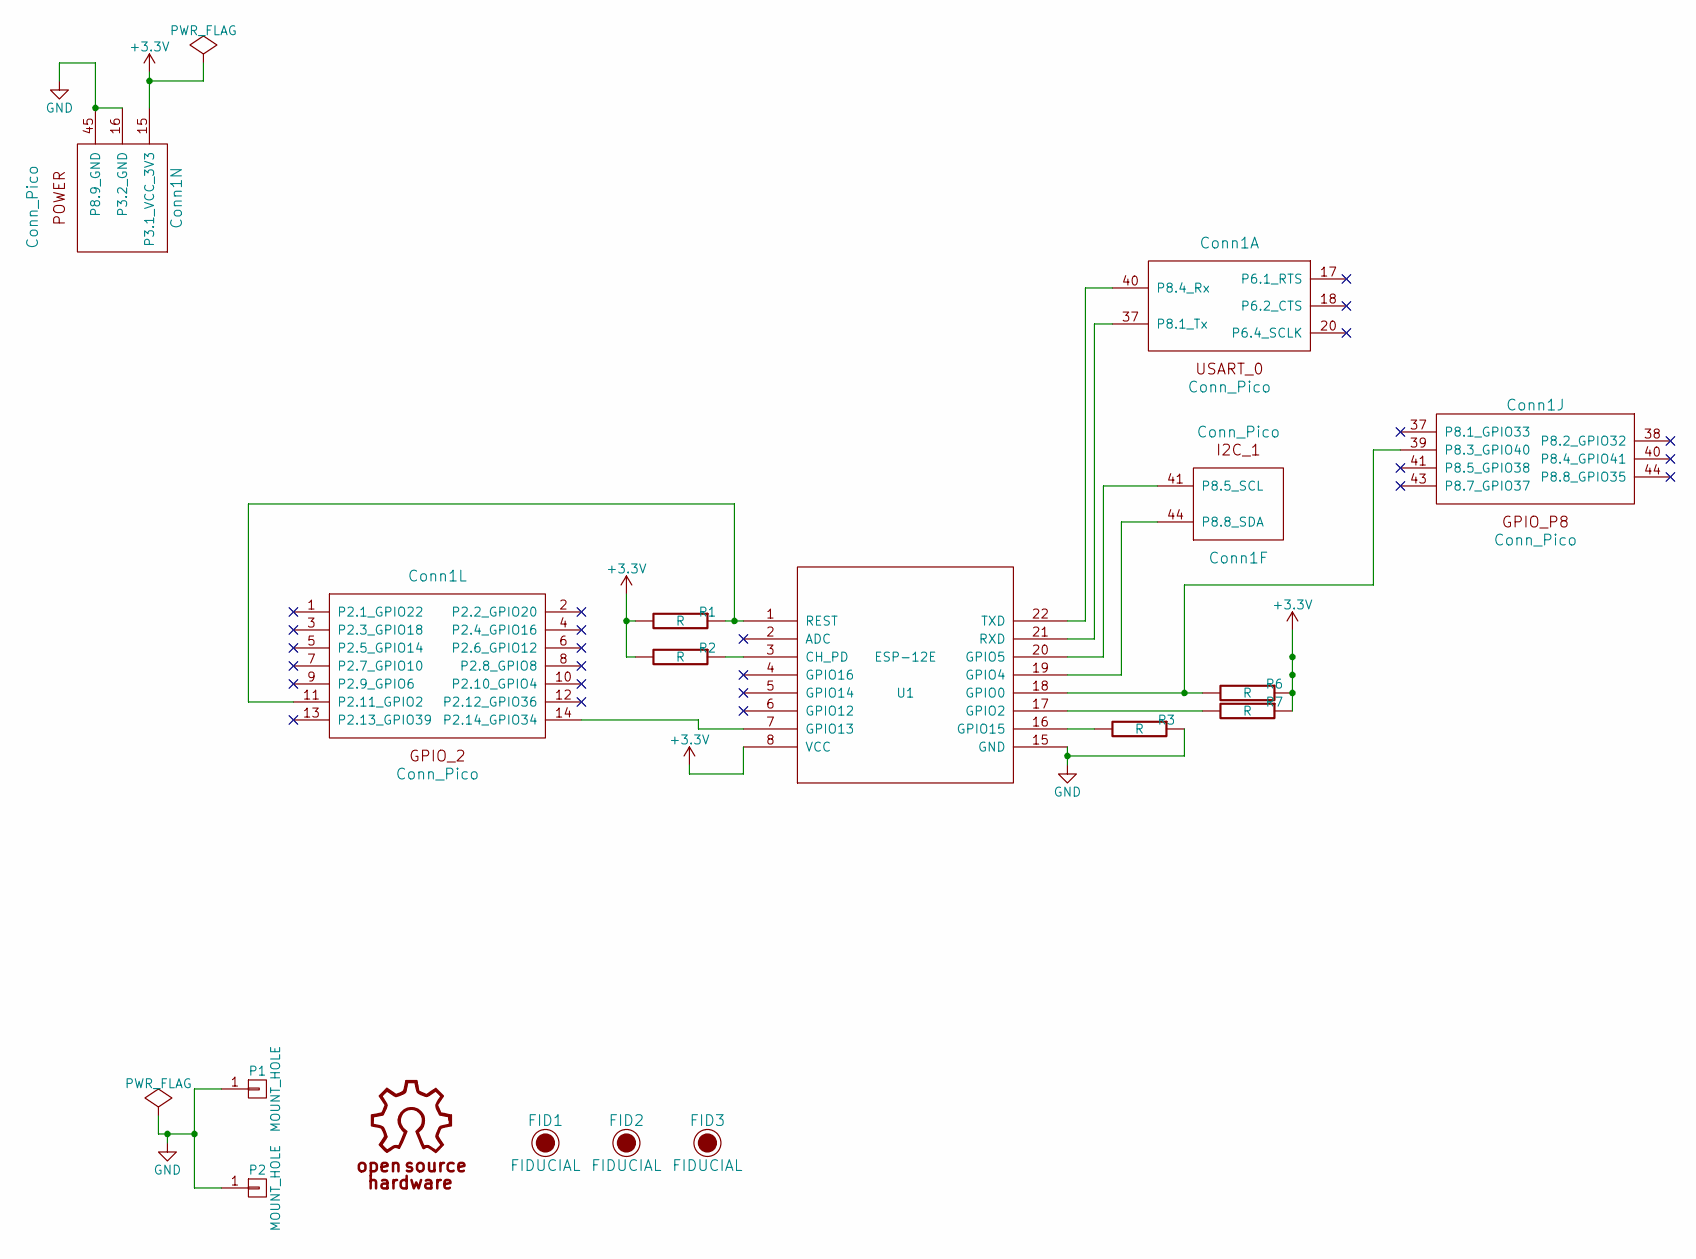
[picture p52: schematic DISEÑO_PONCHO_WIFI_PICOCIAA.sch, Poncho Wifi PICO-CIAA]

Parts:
Conn1: Conn_Pico; Conn_Pico_Ciaa; Digikey# Value
FID1, FID2, FID3: FIDUCIAL; Fiducial_1mm_Dia_2.54mm_Outer_CopperTop
P1, P2: MOUNT_HOLE; PIN_ARRAY_1
R1, R2, R3, R6, R7: R; R_0805_HandSoldering; Digikey# 1056-MCR10J103-CHP
U1: ESP-12E; Digikey# 1528-1438-ND

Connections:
+3V3: Conn1.15 (P3.1_VCC_3V3), R1.2, R2.2, R6.1, R7.1, U1.8 (VCC)
GND: Conn1.16 (P3.2_GND), Conn1.45 (P8.9_GND), P1.1, P2.1, R3.1, U1.15 (GND)
unnamed: Conn1.11 (P2.11_RTS), R1.1, U1.1 (REST)
unnamed: Conn1.14 (P2.14_GPIO34), U1.7 (GPIO13)
unnamed: Conn1.37 (P8.1_Tx), U1.21 (RXD)
unnamed: Conn1.39 (P8.3_SCL), R6.2, U1.18 (GPIO0)
unnamed: Conn1.40 (P8.4_Rx), U1.22 (TXD)
unnamed: Conn1.41 (P8.5_CTS), U1.20 (GPIO5)
unnamed: Conn1.44 (P8.8_SDA), U1.19 (GPIO4)
unnamed: R2.1, U1.3 (CH_PD)
unnamed: R3.2, U1.16 (GPIO15)
unnamed: R7.2, U1.17 (GPIO2)

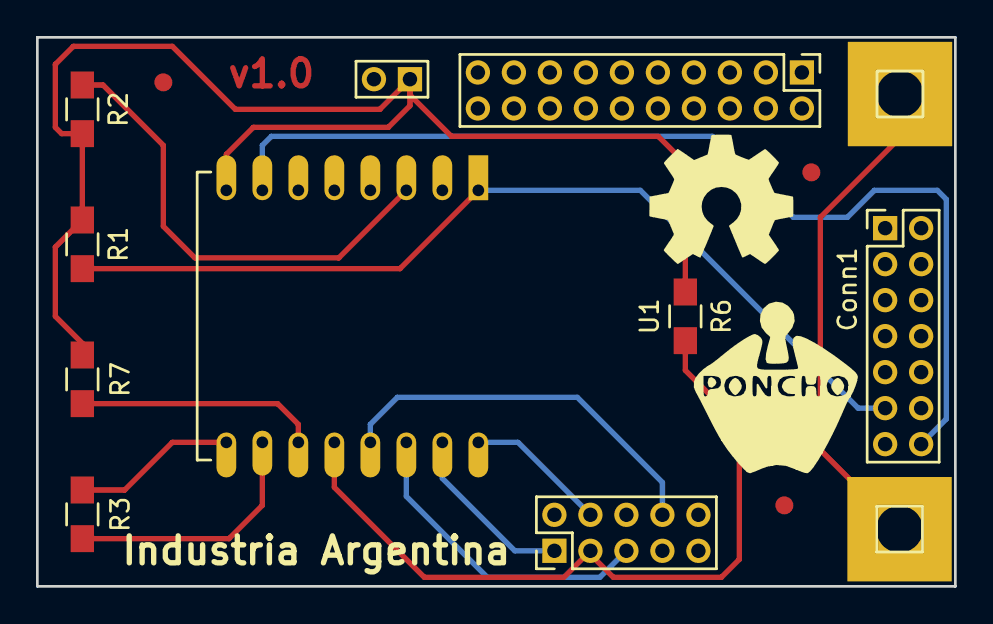
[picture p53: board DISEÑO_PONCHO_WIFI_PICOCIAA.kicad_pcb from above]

Board: 2 copper layers, 51.0 x 30.5 mm, 13 parts (0 on the bottom side), 12 nets.

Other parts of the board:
G101: Logo_OSHWA

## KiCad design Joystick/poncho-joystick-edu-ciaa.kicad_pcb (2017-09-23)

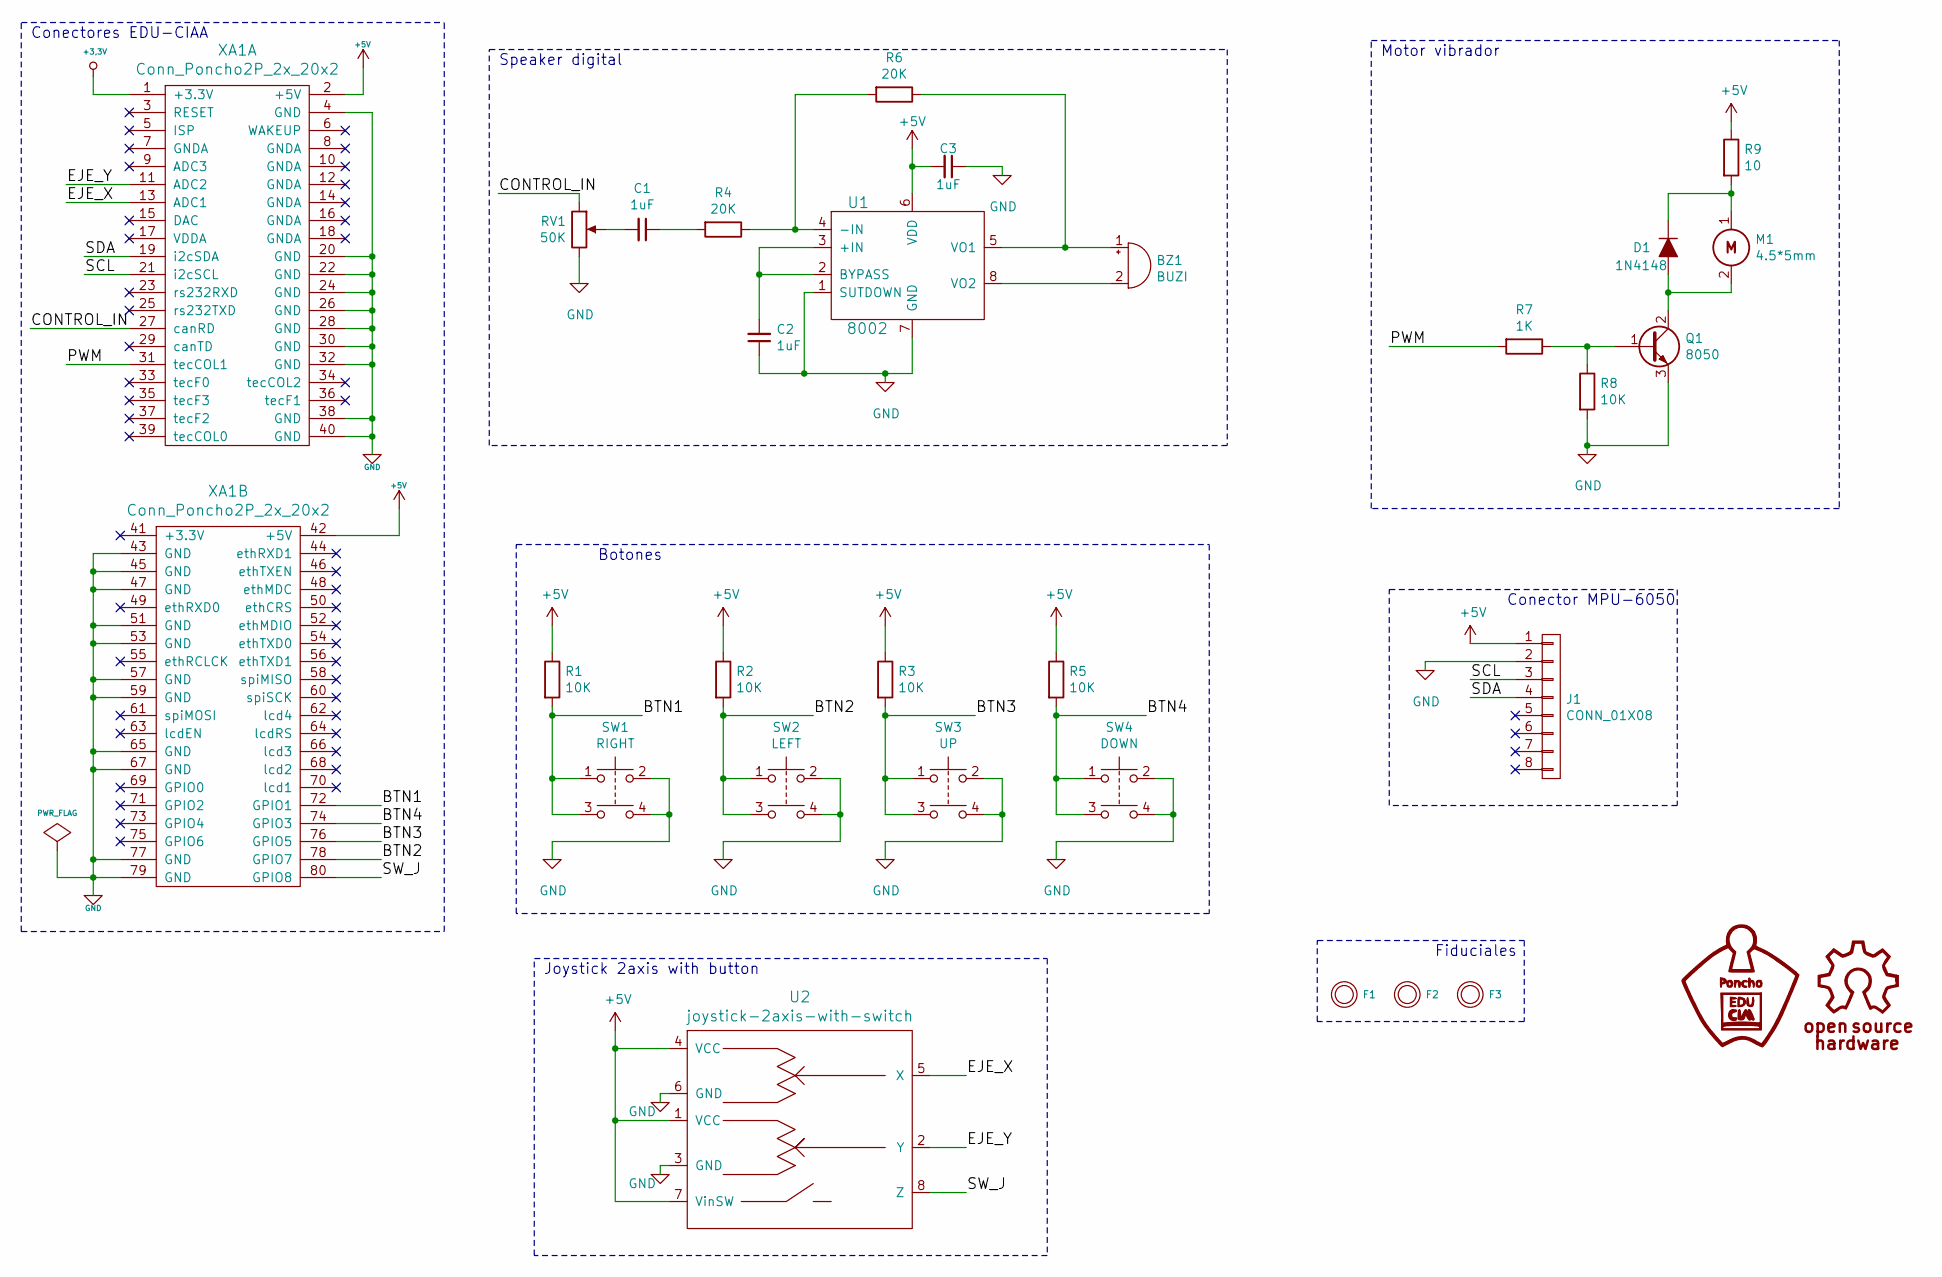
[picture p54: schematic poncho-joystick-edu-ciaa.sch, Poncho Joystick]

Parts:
BZ1: BUZI; Buzzer_12x9.5RM7.6; DigiKey# 102-2502-ND
C1, C2, C3: 1uF; C_0805_HandSoldering; DigiKey# 490-1536-2-ND
D1: 1N4148; D_0805; DigiKey# CD0603-S01575TR-ND
F1, F2, F3: FIDUCIAL; Fiducial_1mm
J1: CONN_01X08; adxl345
M1: 4.5*5mm; Vibration_motor; DigiKey# P122157-ND
Q1: 8050; SOT-23_Handsoldering; DigiKey# MMSS8050-L-TPMSTR-ND
R1, R2, R3, R5, R8: 10K; R_0805_HandSoldering; DigiKey# 311-10KERTR-ND
R4, R6: 20K; R_0805_HandSoldering; DigiKey# 311-20KERTR-ND
R7: 1K; R_0805_HandSoldering; DigiKey# 311-1.00KFRTR-ND
R9: 10; R_0805_HandSoldering; DigiKey# 311-10.0FRTR-ND
RV1: 50K; Potentiometer_Trimmer-EVM3E; DigiKey# ST32ETB503TR-ND
SW1: RIGHT; SW_SPST_KMR2; DigiKey# CKN10246TR-ND
SW2: LEFT; SW_SPST_KMR2; DigiKey# CKN10246TR-ND
SW3: UP; SW_SPST_KMR2; DigiKey# CKN10246TR-ND
SW4: DOWN; SW_SPST_KMR2; DigiKey# CKN10246TR-ND
U1: 8002; AD8002; DigiKey# AD8002ARMZ-ND
U2: joystick-2axis-with-switch; joystick-2axis-withswitch; DigiKey# 254SA103B50B-ND
XA1: Conn_Poncho2P_2x_20x2; Conn_Poncho_Completo_Modificado

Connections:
+3.3V: XA1.1 (+3.3V)
+5V: C3.2, J1.1, R1.1, R2.1, R3.1, R5.1, R9.1, U1.6 (VDD), U2.1 (VCC), U2.4 (VCC), U2.7 (VinSW), XA1.2 (+5V), XA1.42 (+5V)
/BTN1: R1.2, SW1.1, SW1.3, XA1.72 (GPIO1)
/BTN2: R2.2, SW2.1, SW2.3, XA1.78 (GPIO7)
/BTN3: R3.2, SW3.1, SW3.3, XA1.76 (GPIO5)
/BTN4: R5.2, SW4.1, SW4.3, XA1.74 (GPIO3)
/CONTROL_IN: RV1.1, XA1.27 (canRD)
/EJE_X: U2.5 (X), XA1.13 (ADC1)
/EJE_Y: U2.2 (Y), XA1.11 (ADC2)
/PWM: R7.2, XA1.31 (tecCOL1)
/SCL: J1.3, XA1.21 (i2cSCL)
/SDA: J1.4, XA1.19 (i2cSDA)
/SW_J: U2.8 (Z), XA1.80 (GPIO8)
GND: C2.1, C3.1, J1.2, Q1.3 (E), R8.2, RV1.3, SW1.2, SW1.4, SW2.2, SW2.4, SW3.2, SW3.4, SW4.2, SW4.4, U1.1 (SUTDOWN), U1.7 (GND), U2.3 (GND), U2.6 (GND), XA1.4 (GND), XA1.20 (GND), XA1.22 (GND), XA1.24 (GND), XA1.26 (GND), XA1.28 (GND), XA1.30 (GND), XA1.32 (GND), XA1.38 (GND), XA1.40 (GND), XA1.43 (GND), XA1.45 (GND), XA1.47 (GND), XA1.51 (GND), XA1.53 (GND), XA1.57 (GND), XA1.59 (GND), XA1.65 (GND), XA1.67 (GND), XA1.77 (GND), XA1.79 (GND)
unnamed 14: BZ1.1 (-), R6.1, U1.5 (VO1); also elsewhere on the board
unnamed 15: BZ1.2 (+), U1.8 (VO2); also elsewhere on the board
unnamed: C1.1, R4.2
unnamed: C1.2, RV1.2
unnamed: C2.2, U1.2 (BYPASS), U1.3 (+IN)
unnamed: D1.1 (K), M1.1 (+), R9.2
unnamed: D1.2 (A), M1.2 (-), Q1.2 (C)
unnamed: Q1.1 (B), R7.1, R8.1
unnamed: R4.1, R6.2, U1.4 (-IN)

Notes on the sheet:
Speaker digital
Motor vibrador
Botones
Conector MPU-6050
Conectores EDU-CIAA
Joystick 2axis with button
Fiduciales

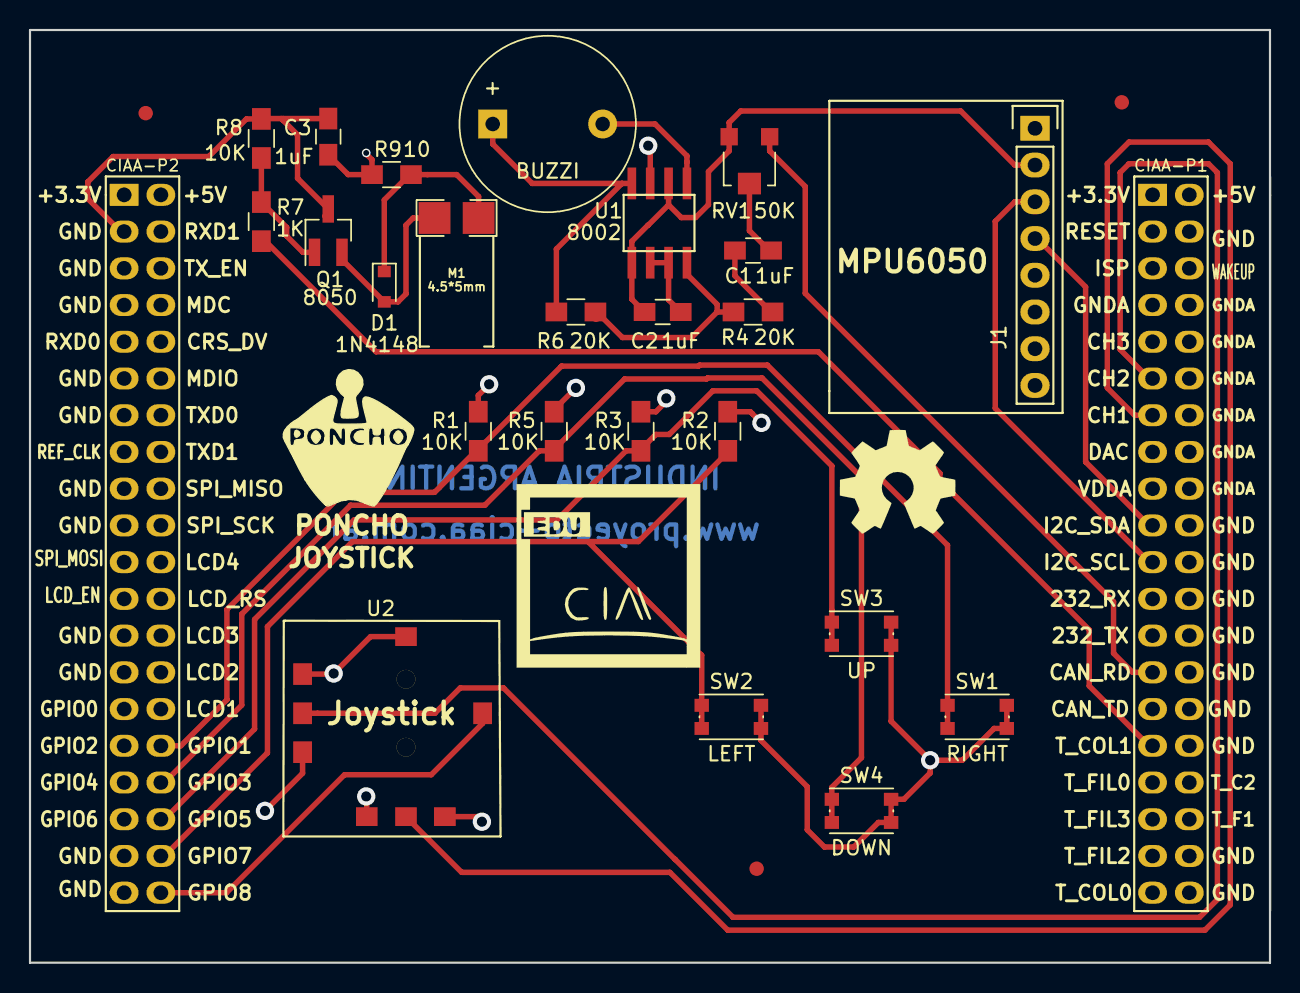
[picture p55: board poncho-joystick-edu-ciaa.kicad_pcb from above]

Board: 2 copper layers, 85.8 x 64.5 mm, 29 parts (0 on the bottom side), 22 nets.

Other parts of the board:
BUZZI: BUZI; Buzzer_12x9.5RM7.6
PONCHO: JOYSTICK; Logo_Poncho

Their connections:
unnamed 14: BUZZI.1; also elsewhere on the board
unnamed 15: BUZZI.2; also elsewhere on the board

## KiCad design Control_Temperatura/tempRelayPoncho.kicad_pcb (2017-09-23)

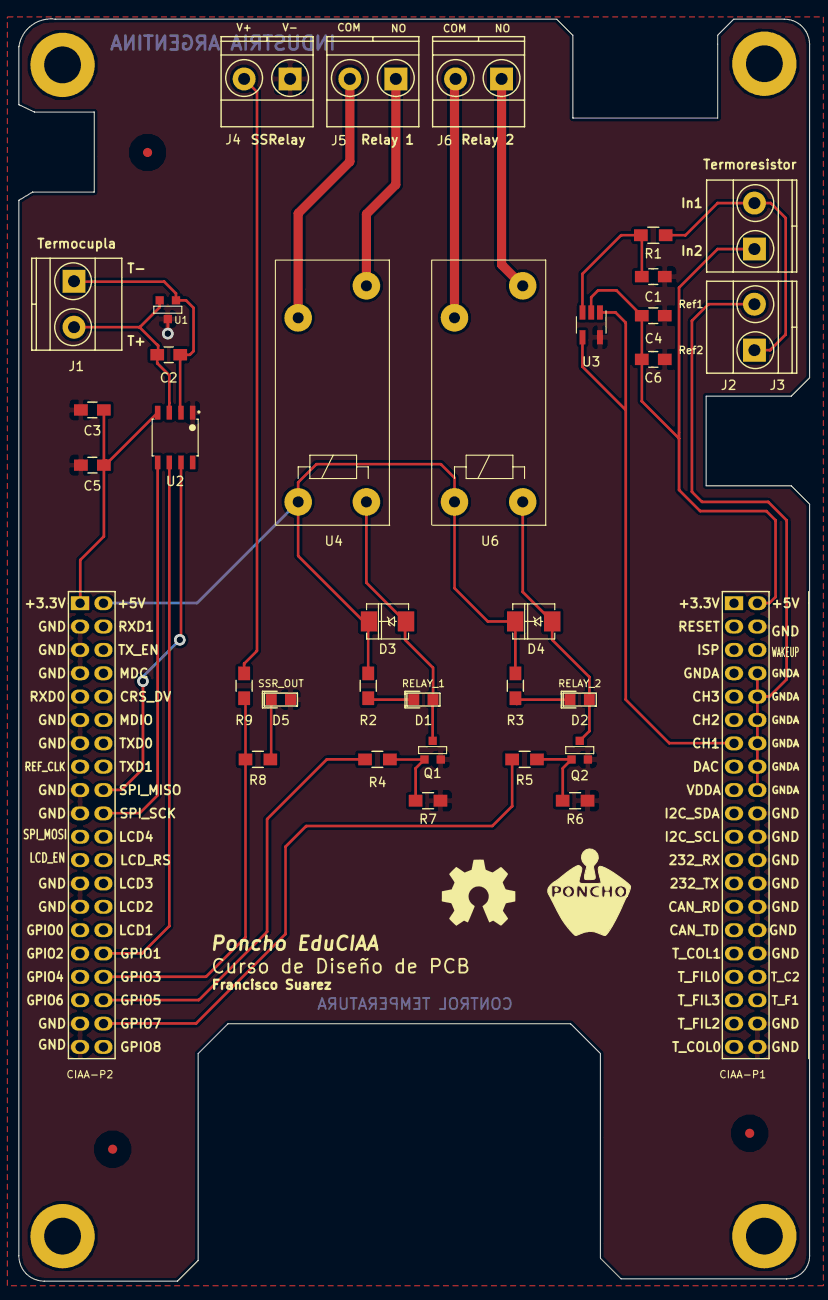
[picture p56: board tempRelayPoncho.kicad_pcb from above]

Board: 2 copper layers, 86.0 x 137.3 mm, 38 parts (0 on the bottom side), 28 nets.

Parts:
C1, C3, C4: 10u; C_0805_HandSoldering
C2, C5, C6: 100n; C_0805_HandSoldering
D1: RELAY_1; LED-0805
D2: RELAY_2; LED-0805
D3, D4: MRA4003T3G; DO-214AA(SMB)
D5: SSR_OUT; LED-0805
F1, F2, F3: FIDUCIAL; Fiducial_1mm
G101: Logo_OSHWA
J1, J2, J3, J4, J5, J6: Screw_Terminal_1x02; TerminalBlock_Pheonix_MKDS1.5-2pol
Q1, Q2: MMBT3904; SOT23_NPN
R1, R6, R7: 10k; R_0805_HandSoldering
R2, R3, R4, R5, R8: 1k; R_0805_HandSoldering
R9: 100; R_0805_HandSoldering
U1: NUP2105LT1G; SOT23_NPN
U2: MAX31855KASA+; SOIC-8
U3: MCP601R; SOT-23-5_HandSoldering
U4, U6: G5LE-1A-5DC; Relay_G5LE-1A-5DC-5mm
XA1: Conn_Poncho2P_2x_20x2; Conn_Poncho_Completo

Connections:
+3V3: C3.2, C5.2, U2.4, XA1.41
+5V: C4.2, C6.2, J2.1, U3.2, XA1.2
+5VD: D3.2, D4.2, R2.2, R3.2, U4.5, U6.5, XA1.42
/conector_ciaa/ADC_1: U3.1, U3.4, XA1.13
/conector_ciaa/GPIO_1: U2.6, XA1.72
/conector_ciaa/GPIO_3: R8.2, R9.2, XA1.74
/conector_ciaa/GPIO_5: R4.2, XA1.76
/conector_ciaa/GPIO_7: R5.2, XA1.78
/inputs_temp/MISO_TCUP: U2.7, XA1.58
/inputs_temp/SCK_TCUP: U2.5, XA1.60
GND: C1.1, C3.1, C4.1, C5.1, C6.1, D5.1, J4.1, Q1.2, Q2.2, R6.1, R7.1, U1.3, U2.1, U3.5, XA1.4, XA1.20, XA1.22, XA1.24, XA1.26, XA1.28, XA1.30, XA1.32, XA1.38, XA1.40, XA1.43, XA1.45, XA1.47, XA1.51, XA1.53, XA1.57, XA1.59, XA1.65, XA1.67, XA1.77, XA1.79
GNDA: J3.2, XA1.8, XA1.10, XA1.12, XA1.14, XA1.16, XA1.18
unnamed: C1.2, R1.1, U3.3
unnamed: C2.1, J1.2, U1.2, U2.3
unnamed: C2.2, J1.1, U1.1, U2.2
unnamed: D1.1, D3.1, Q1.3, U4.1
unnamed: D1.2, R2.1
unnamed: D2.1, D4.1, Q2.3, U6.1
unnamed: D2.2, R3.1
unnamed: D5.2, R8.1
unnamed: J2.2, J3.1, R1.2
unnamed: J4.2, R9.1
unnamed: J5.1, U4.3
unnamed: J5.2, U4.4
unnamed: J6.1, U6.3
unnamed: J6.2, U6.4
unnamed: Q1.1, R4.1, R7.2
unnamed: Q2.1, R5.1, R6.2

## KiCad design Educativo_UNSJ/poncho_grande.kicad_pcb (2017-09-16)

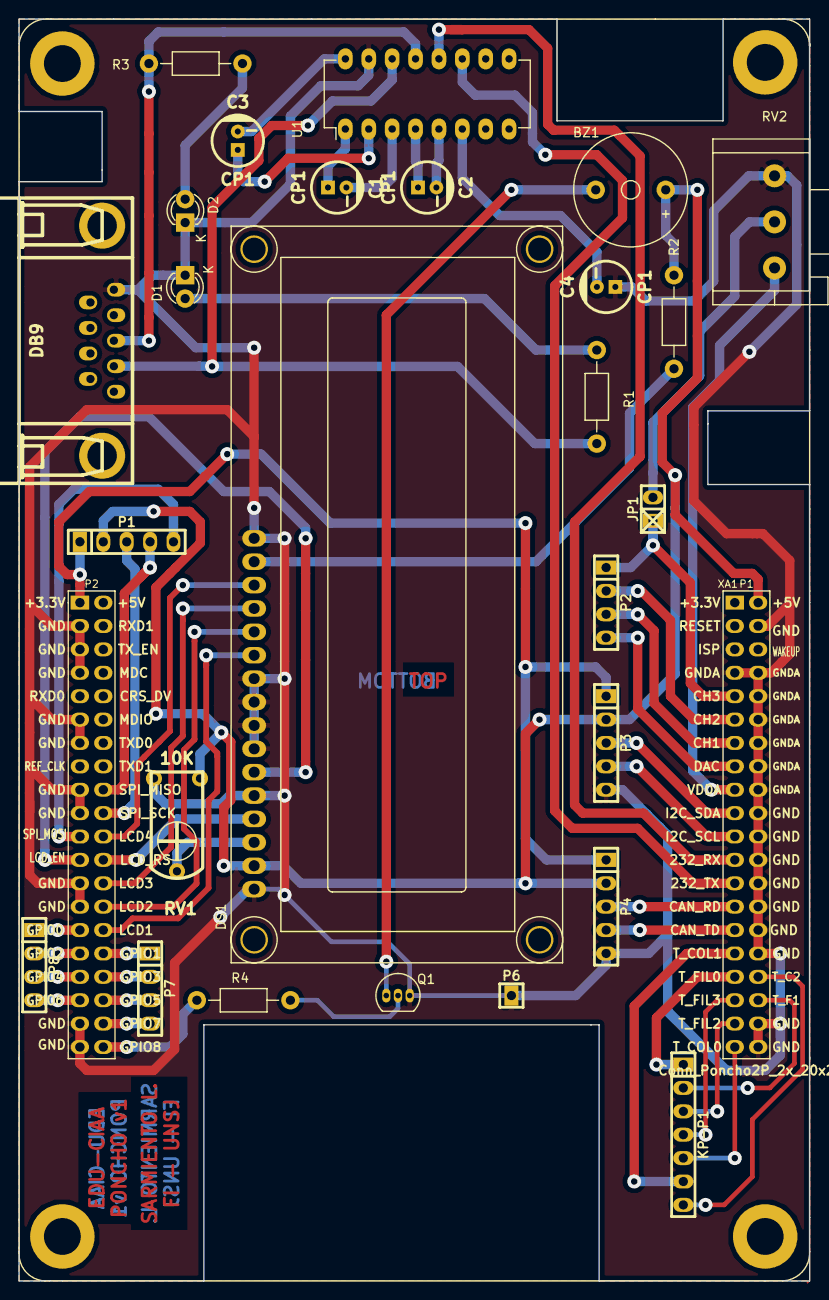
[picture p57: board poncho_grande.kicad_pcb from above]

Board: 2 copper layers, 85.9 x 137.0 mm, 27 parts (0 on the bottom side), 55 nets.

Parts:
BZ1: buzzer; Buzzer_12x9.5RM7.6
C1, C2, C3, C4: CP1; CP_5x11mm
D1, D2: Led_Small; LED-3MM
DS1: LCD16X2; WC1602A
J1: DB9; DB_9F
JP1: JUMPER; pin_strip_2
KP-P1: Keypad_-_Phone; pin_socket_7
P1, P3, P4: CONN_01X05; pin_strip_5
P2, P7, P8: CONN_01X04; pin_strip_4
P6: CONN_01X01; pin_strip_1
Q1: BC548; TO-92_Inline_Narrow_Oval
R1, R3: 470; Resistor_Horizontal_RM10mm
R2: 100; Resistor_Horizontal_RM10mm
R4: 1K; Resistor_Horizontal_RM10mm
RV1: 10K; trimmer_piher_pt10xv
RV2: 10K; Potentiometer_Alps-RK16-single
U1: MAX232; DIP-16_W7.62mm_LongPads
XA1: Conn_Poncho2P_2x_20x2; poncho_grande

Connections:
+3.3VADC: RV2.3, XA1.17
+3.3VP: P1.1, P3.1, P4.1, XA1.41
+5V: BZ1.1, DS1.2, P1.2, P3.2, P4.2, R2.1, RV1.1, XA1.2
/Circuito Principal/ADC1: P2.3, XA1.13
/Circuito Principal/ADC2: P2.2, XA1.11
/Circuito Principal/ADC3: JP1.1, P2.1, XA1.9
/Circuito Principal/COL0: KP-P1.5, XA1.39
/Circuito Principal/COL1: KP-P1.6, XA1.31
/Circuito Principal/COL2: KP-P1.7, XA1.34
/Circuito Principal/DAC: P2.4, XA1.15
/Circuito Principal/F0: KP-P1.1, XA1.33
/Circuito Principal/F1: KP-P1.2, XA1.36
/Circuito Principal/F2: KP-P1.3, XA1.37
/Circuito Principal/F3: KP-P1.4, XA1.35
/Circuito Principal/GPIO0: P8.1, XA1.69
/Circuito Principal/GPIO1: P7.1, XA1.72
/Circuito Principal/GPIO2: P8.2, XA1.71
/Circuito Principal/GPIO3: P7.2, XA1.74
/Circuito Principal/GPIO4: P8.3, XA1.73
/Circuito Principal/GPIO5: P7.3, XA1.76
/Circuito Principal/GPIO6: P8.4, XA1.75
/Circuito Principal/GPIO7: P7.4, XA1.78
/Circuito Principal/GPIO8: R4.2, XA1.80
/Circuito Principal/LCD1: DS1.11, XA1.70
/Circuito Principal/LCD2: DS1.12, XA1.68
/Circuito Principal/LCD3: DS1.13, XA1.66
/Circuito Principal/LCD4: DS1.14, XA1.62
/Circuito Principal/LCD_EN: DS1.6, XA1.63
/Circuito Principal/MISO: P1.4, XA1.58
/Circuito Principal/MOSI: P1.5, XA1.61
/Circuito Principal/RD: P4.3, XA1.27
/Circuito Principal/RS: DS1.4, XA1.64
/Circuito Principal/RXD: U1.12, XA1.23
/Circuito Principal/SCL: P3.4, XA1.21
/Circuito Principal/SDA: P3.3, XA1.19
/Circuito Principal/TD: P4.4, XA1.29
/Circuito Principal/TXD: U1.11, XA1.25
/Circuito Principal/spiCCK: P1.3, XA1.60
GND: C4.1, D1.1, D2.1, DS1.1, DS1.5, DS1.7, DS1.8, DS1.9, DS1.10, DS1.16, J1.5, P3.5, P4.5, P6.1, Q1.3, RV1.3, RV2.1, U1.15, XA1.4, XA1.7, XA1.8, XA1.10, XA1.12, XA1.14, XA1.16, XA1.18, XA1.20, XA1.22, XA1.24, XA1.26, XA1.28, XA1.30, XA1.32, XA1.38, XA1.40, XA1.43, XA1.45, XA1.47, XA1.51, XA1.53, XA1.57, XA1.59, XA1.65, XA1.67, XA1.77, XA1.79
unnamed: BZ1.2, Q1.1
unnamed: C1.1, U1.1
unnamed: C1.2, U1.3
unnamed: C2.1, U1.4
unnamed: C2.2, U1.5
unnamed: C3.1, U1.2
unnamed: C3.2, U1.16
unnamed: C4.2, U1.6
unnamed: D1.2, R1.1
unnamed: D2.2, R3.1
unnamed: DS1.3, RV1.2
unnamed: DS1.15, R2.2
unnamed: J1.2, R1.2, U1.14
unnamed: J1.3, R3.2, U1.13
unnamed: JP1.2, RV2.2
unnamed: Q1.2, R4.1

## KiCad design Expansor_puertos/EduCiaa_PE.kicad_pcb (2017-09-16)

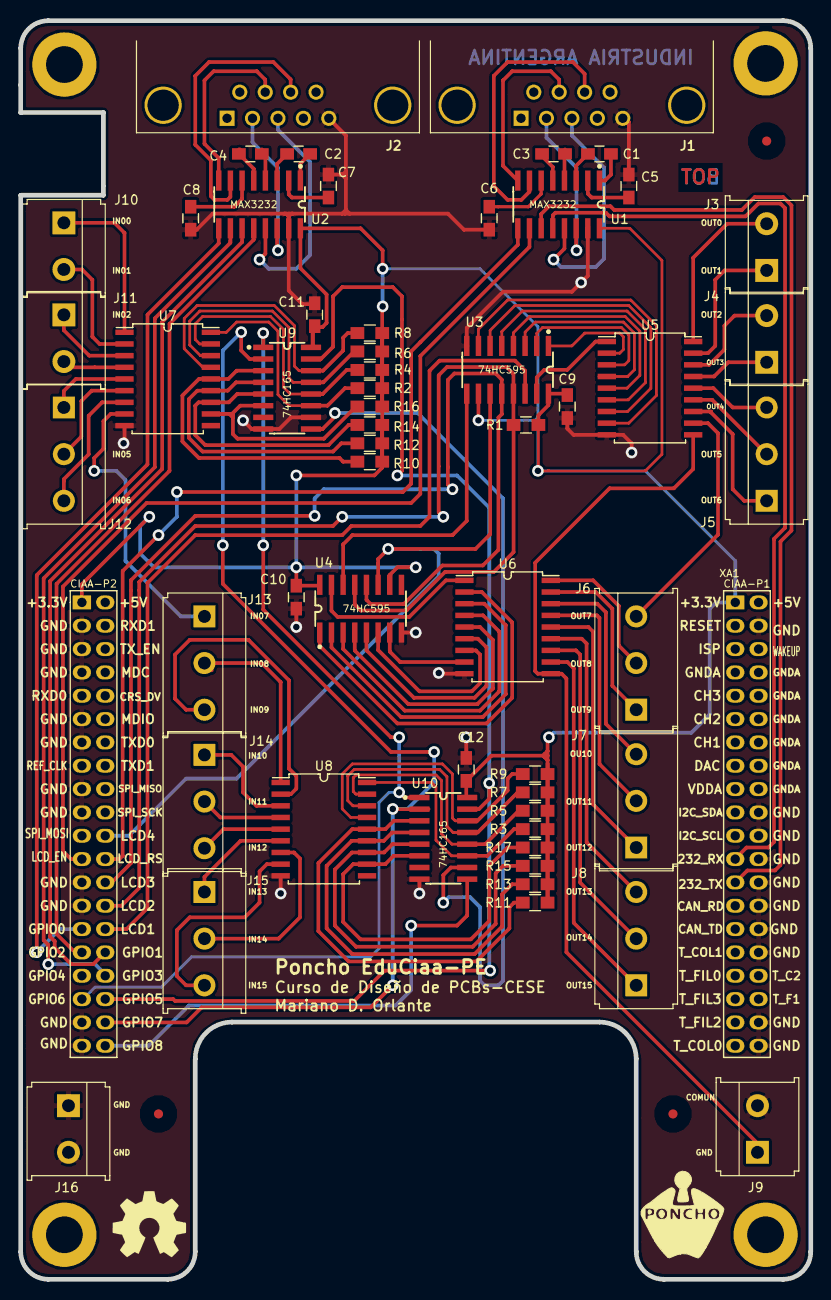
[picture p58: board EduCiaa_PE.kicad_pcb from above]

Board: 2 copper layers, 86.0 x 137.0 mm, 61 parts (0 on the bottom side), 105 nets.

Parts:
C1, C2, C3, C4, C5, C6, C7, C8, C9, C10, C11, C12: 100nF; C_0805_HandSoldering
F1, F2, F3: FIDUCIAL; Fiducial_1mm
G1: LOGO; Logo_Poncho
G2: Logo_OSHWA
J1, J2: DB9; DB9_F_TH
J3, J4, J9, J10, J11, J16: TB_1X2; bornier2
J5, J6, J7, J8, J12, J13, J14, J15: TB_1X3; bornier3
R1, R2, R3, R4, R5, R6, R7, R8, R9, R10, R11, R12, R13, R14, R15, R16, R17: 10K; R_0805_HandSoldering
U1, U2: MAX3232; SOIC-16N
U3, U4: 74HC595; SOIC-16N
U5, U6, U7, U8: ULN2803A; SOIC-18
U9, U10: 74HC165; SOIC-16N
XA1: Conn_Poncho2P_2x_20x2; Conn_Poncho_Completo

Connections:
+3V3: C9.1, C10.2, C11.1, C12.1, R1.2, R2.1, R3.1, R4.1, R5.1, R6.1, R7.1, R8.1, R9.1, R10.1, R11.1, R12.1, R13.1, R14.1, R15.1, R16.1, R17.1, U1.16, U2.16, U3.10, U3.16, U4.10, U4.16, U9.16, U10.16, XA1.1, XA1.41
/ConectoresEduCiaaNxp/GPIO6: U9.1, U10.1, XA1.75
/ConectoresEduCiaaNxp/LCD2: R1.1, U3.13, U4.13, XA1.68
/ConectoresEduCiaaNxp/LCD4: U3.11, U4.11, XA1.62
/EntradasDigitales/CLK: U9.2, U10.2, XA1.78
/EntradasDigitales/CLKINH: U9.15, U10.15, XA1.76
/EntradasDigitales/DATAIN: U10.9, XA1.80
/EntradasDigitales/I0: R2.2, U7.18, U9.11
/EntradasDigitales/I1: R4.2, U7.17, U9.12
/EntradasDigitales/I2: R6.2, U7.16, U9.13
/EntradasDigitales/I3: R8.2, U7.15, U9.14
/EntradasDigitales/I4: R10.2, U7.14, U9.3
/EntradasDigitales/I5: R12.2, U7.13, U9.4
/EntradasDigitales/I6: R14.2, U7.12, U9.5
/EntradasDigitales/I7: R16.2, U7.11, U9.6
/EntradasDigitales/I8: R3.2, U8.18, U10.11
/EntradasDigitales/I9: R5.2, U8.17, U10.12
/EntradasDigitales/I10: R7.2, U8.16, U10.13
/EntradasDigitales/I11: R9.2, U8.15, U10.14
/EntradasDigitales/I12: R11.2, U8.14, U10.3
/EntradasDigitales/I13: R13.2, U8.13, U10.4
/EntradasDigitales/I14: R15.2, U8.12, U10.5
/EntradasDigitales/I15: R17.2, U8.11, U10.6
/EntradasDigitales/IN00: J10.1, U7.1
/EntradasDigitales/IN01: J10.2, U7.2
/EntradasDigitales/IN02: J11.1, U7.3
/EntradasDigitales/IN03: J11.2, U7.4
/EntradasDigitales/IN04: J12.1, U7.5
/EntradasDigitales/IN05: J12.2, U7.6
/EntradasDigitales/IN06: J12.3, U7.7
/EntradasDigitales/IN07: J13.1, U7.8
/EntradasDigitales/IN08: J13.2, U8.1
/EntradasDigitales/IN09: J13.3, U8.2
/EntradasDigitales/IN10: J14.1, U8.3
/EntradasDigitales/IN11: J14.2, U8.4
/EntradasDigitales/IN12: J14.3, U8.5
/EntradasDigitales/IN13: J15.1, U8.6
/EntradasDigitales/IN14: J15.2, U8.7
/EntradasDigitales/IN15: J15.3, U8.8
/Puertos_Serie/COMA_CTS: U1.9, XA1.64
/Puertos_Serie/COMA_RTS: U1.10, XA1.63
/Puertos_Serie/COMA_RXD: U1.12, XA1.23
/Puertos_Serie/COMA_TXD: U1.11, XA1.25
/Puertos_Serie/COMB_CTS: U2.9, XA1.69
/Puertos_Serie/COMB_RTS: U2.10, XA1.74
/Puertos_Serie/COMB_RXD: U2.12, XA1.71
/Puertos_Serie/COMB_TXD: U2.11, XA1.72
/SalidasDigitales/COMUN: J9.1, U5.10, U6.10
/SalidasDigitales/DATA: U3.14, XA1.70
/SalidasDigitales/LATCH: U3.12, U4.12, XA1.66
/SalidasDigitales/OUT0: J3.2, U5.18
/SalidasDigitales/OUT1: J3.1, U5.17
/SalidasDigitales/OUT2: J4.2, U5.16
/SalidasDigitales/OUT3: J4.1, U5.15
/SalidasDigitales/OUT4: J5.3, U5.14
/SalidasDigitales/OUT5: J5.2, U5.13
/SalidasDigitales/OUT6: J5.1, U5.12
/SalidasDigitales/OUT7: J6.3, U5.11
/SalidasDigitales/OUT8: J6.2, U6.18
/SalidasDigitales/OUT9: J6.1, U6.17
/SalidasDigitales/OUT10: J7.3, U6.16
/SalidasDigitales/OUT11: J7.2, U6.15
/SalidasDigitales/OUT12: J7.1, U6.14
/SalidasDigitales/OUT13: J8.3, U6.13
/SalidasDigitales/OUT14: J8.2, U6.12
/SalidasDigitales/OUT15: J8.1, U6.11
GND: C5.1, C6.1, C7.1, C8.1, C9.2, C10.1, C11.2, C12.2, J1.5, J2.5, J9.2, J16.1, J16.2, U1.15, U2.15, U3.8, U4.8, U5.9, U6.9, U7.9, U8.9, U9.8, U9.10, U10.8, XA1.4, XA1.20, XA1.22, XA1.24, XA1.26, XA1.28, XA1.30, XA1.32, XA1.38, XA1.40, XA1.43, XA1.45, XA1.47, XA1.51, XA1.53, XA1.57, XA1.59, XA1.65, XA1.67, XA1.77, XA1.79
unnamed: C1.1, U1.1
unnamed: C1.2, U1.3
unnamed: C2.1, U2.1
unnamed: C2.2, U2.3
unnamed: C3.1, U1.4
unnamed: C3.2, U1.5
unnamed: C4.1, U2.4
unnamed: C4.2, U2.5
unnamed: C5.2, U1.2
unnamed: C6.2, U1.6
unnamed: C7.2, U2.2
unnamed: C8.2, U2.6
unnamed: J1.2, U1.14
unnamed: J1.3, U1.13
unnamed: J1.7, U1.8
unnamed: J1.8, U1.7
unnamed: J2.2, U2.14
unnamed: J2.3, U2.13
unnamed: J2.7, U2.8
unnamed: J2.8, U2.7
unnamed: U3.1, U5.2
unnamed: U3.2, U5.3
unnamed: U3.3, U5.4
unnamed: U3.4, U5.5
unnamed: U3.5, U5.6
unnamed: U3.6, U5.7
unnamed: U3.7, U5.8
unnamed: U3.9, U4.14
unnamed: U3.15, U5.1
unnamed: U4.1, U6.2
unnamed: U4.2, U6.3
unnamed: U4.3, U6.4
unnamed: U4.4, U6.5
unnamed: U4.5, U6.6
unnamed: U4.6, U6.7
unnamed: U4.7, U6.8
unnamed: U4.15, U6.1
unnamed: U9.9, U10.10

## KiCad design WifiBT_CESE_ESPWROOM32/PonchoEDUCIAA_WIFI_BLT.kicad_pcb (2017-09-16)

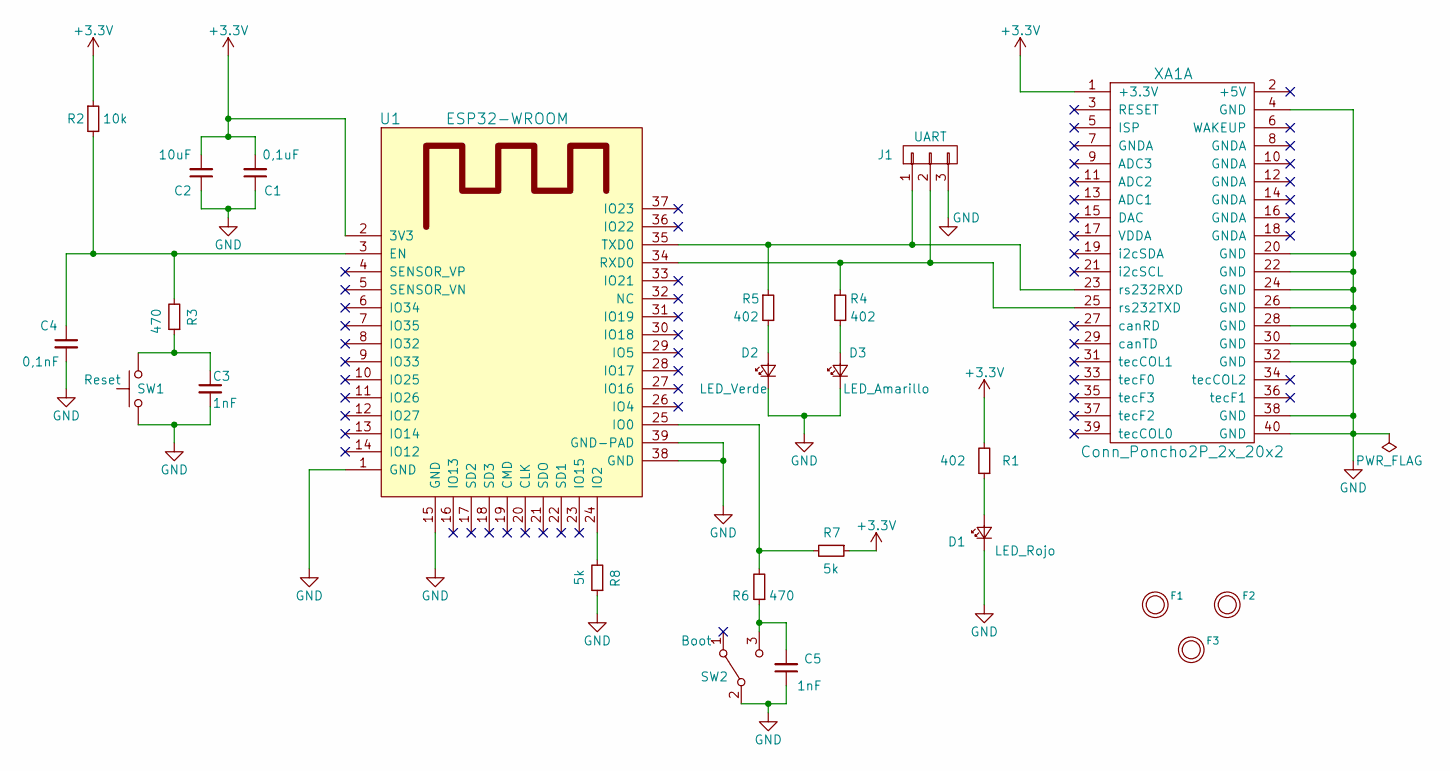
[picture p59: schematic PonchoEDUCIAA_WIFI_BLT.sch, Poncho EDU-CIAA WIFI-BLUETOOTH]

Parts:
C1: 0,1uF; C_0603_HandSoldering; Mouser# 581-02016D104KAT2A; Digikey# 478-5266-1-ND
C2: 10uF; C_0603_HandSoldering; Mouser# 81-GRM219R60J106KE9D; Digikey# 490-3340-1-ND
C3: 1nF; C_0603_HandSoldering; Mouser# 81-GRM1555C1H101JA1D; Digikey# 490-5922-1-ND
C4: 0,1nF; C_0603_HandSoldering; Mouser# 81-GRM1555C1H100JA1D; Digikey# 490-5921-1-ND
C5: 1nF; C_0603_HandSoldering; Mouser# 581-0201ZA101JAT2A; Digikey# 478-1026-1-ND
D1: LED_Rojo; LED_0805; Mouser# 720-LSR976-NR-1; Digikey# 475-1278-1-ND
D2: LED_Verde; LED_0805; Mouser# 720-LGR971-KN-1; Digikey# 475-1410-1-ND
D3: LED_Amarillo; LED_0805; Mouser# 720-LYR976-PS-36; Digikey# 475-2560-1-ND
F1, F2, F3: FIDUCIAL; Fiducial_1mm
J1: UART; CON_PALETA_3; Mouser# 538-22-27-2031; Digikey# WM4112-ND
R1, R4, R5: 402; R_0805_HandSoldering; Mouser# 603-RC0805FR-07402RL; Digikey# 311-402CRCT-ND
R2: 10k; R_0805_HandSoldering; Mouser# 667-ERA-6AEB103V; Digikey# P10KDACT-ND
R3, R6: 470; R_0805_HandSoldering; Mouser# 603-RC0805FR-07470RL; Digikey# 311-470CRCT-ND
R7, R8: 5k; R_0805_HandSoldering; Mouser# 71-CRCW0805-5K; Digikey# CRCW08055K00FKTA-ND
SW1: Reset; SW_PUSH_6mm; Mouser# 611-D6C90F1LFS; Digikey# 401-1969-ND
SW2: Boot; SW_Micro_SPST; Mouser# 611-JS202011CQN; Digikey# 401-2001-ND
U1: ESP32-WROOM; Mouser# 485-3320; Digikey# 1528-1801-ND
XA1: Conn_Poncho2P_2x_20x2; Conn_Poncho_Derecha; Mouser# 855-M50-3501042; Digikey# 952-1386-ND

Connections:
+3V3: C1.2, C2.2, R1.2, R2.1, R7.1, U1.2 (3V3), XA1.1 (+3.3V)
GND: C1.1, C2.1, C3.2, C4.2, C5.1, D1.1 (K), D2.1 (K), D3.1 (K), J1.3, R8.1, SW1.1, SW2.2 (B), U1.1 (GND), U1.15 (GND), U1.38 (GND), U1.39 (GND-PAD), XA1.4 (GND), XA1.20 (GND), XA1.22 (GND), XA1.24 (GND), XA1.26 (GND), XA1.28 (GND), XA1.30 (GND), XA1.32 (GND), XA1.38 (GND), XA1.40 (GND)
unnamed: C3.1, R3.1, SW1.2
unnamed: C4.1, R2.2, R3.2, U1.3 (EN)
unnamed: C5.2, R6.1, SW2.3 (C)
unnamed: D1.2 (A), R1.1
unnamed: D2.2 (A), R5.2
unnamed: D3.2 (A), R4.2
unnamed: J1.1, R5.1, U1.35 (TXD0), XA1.23 (rs232RXD)
unnamed: J1.2, R4.1, U1.34 (RXD0), XA1.25 (rs232TXD)
unnamed: R6.2, R7.2, U1.25 (IO0)
unnamed: R8.2, U1.24 (IO2)


Board: 2 copper layers, 51.7 x 57.2 mm, 25 parts (0 on the bottom side), 12 nets.

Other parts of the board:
G1: WIFI-BLTH; Logo_Poncho

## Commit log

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2015-09-28 * Agrego hoja adicional, ediciones varias y remuevo bibliotecas que no se usan.
    [ethernet.sch, poncho_base.sch]
2015-09-28 * Agregadas conexionespropuestas de RESET y de RXER.
    [ethernet.sch, poncho_base.sch]
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2015-09-30 * Cambio el conector de poncho por un cambio de nombre en la biblioteca.
    [conector_poncho.sch, poncho_grande.sch, principal.sch]
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2015-10-01 * Cambios en el esquemático. Ejemplo de Poncho simple con área para prototipado.
    [conector_poncho.sch, poncho_grande.sch, principal.sch]
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2015-10-03 * Agrego leyendas e instructivos de uso en el esquema y el PCB. Agrego carpeta ./doc modelo.
    [poncho_grande.kicad_pcb, poncho_grande.sch]
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2015-12-03 Numeración, corrección de nombres de etiquetas de jerarquía (letra o por cero), pasa el ERC.
    [conector_poncho.sch, ethernet.sch, ethernet_LAN8720A_v2.sch]
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2015-12-19 Ubicación del conector Ethernet (distancia que sobresale de 5mm copiada de CIAA NXP).
    [ethernet_LAN8720A_v2.kicad_pcb]
2016-03-10 Directorio del ponchoPLC
    Agrego el directorio del poncho propuesto en su versión inicial. .
    [DOut_PonchoPLC.sch, Din_PonchoPLC.sch, PonchoPLC.kicad_pcb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]
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2016-05-14 Posicionamiento de componentes para ruteo
    Modificación de posición de componentes teniendo en cuenta el ruteo.
    Ruteo preliminar para confirmar la posición de los componentes.
    [ethernet_LAN8720A_v2.kicad_pcb]
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2016-06-09 pares aceptables, con componentes situados para no cortar el plano de masa.
    [ethernet_LAN8720A_v2.kicad_pcb]
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2016-06-16 Borro pistas y footprints del modelo, edito textos y separo componentes automáticamente por hojas.
    [PonchoPLC.kicad_pcb]
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2016-06-23 Solo queda conectar 3v3. Luego de definir diferenciales, primer intento de completar la placa.
    [ethernet_LAN8720A_v2.kicad_pcb]
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2016-07-07 Acomodo el PCB para Poncho Izquierdo. Borde PCB para ver LEDs. Borro ruteos corridos. Agrego footprints plantilla EDU-CIAA.
    [ethernet_LAN8720A_v2.kicad_pcb]
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2016-07-07 Redibujo planos, agrego keepout en diferenciales, quito rulo grande en diferencial, muevo oscilador 50MHZ entre PHY y MAC, muevo capacitores filtro 3.3v.
    [ethernet_LAN8720A_v2.kicad_pcb]
2016-07-11 Netlist y librería de footprint del proyecto
    Generación y carga del archivo de conexiones del proyecto.
    Se creo la librería de footprint propia del proyecto y se eliminó las
    librerias que se utilizaron de soporte en la etapa inicial.
    Se reemplazaron las líneas "model " por "model
    ${KIPRJMOD}/footprints/EESTN5.3dshapes/" pertenecientes al archivo
    .kicad_pcb del proyecto para que se puedan visualizar correctamente los
    modelos 3D.
    [PonchoPLC.kicad_pcb]
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2016-07-13 Primera version de los esquematicos a partir del modelo de poncho grande
    [Display.sch, Oscilloscopio.kicad_pcb, Oscilloscopio.sch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]
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2016-07-13 Ruteo de todas las lineas restantes luego de RMII y conexión solo izquierda.
    [ethernet_LAN8720A_v2.kicad_pcb]
2016-07-16 Acomdado de serigrafía y algunas pistas para que el pleno llegue a toda la placa.
    [ethernet_LAN8720A_v2.kicad_pcb]
2016-07-18 Se definen los footprints y numeros de parte de todos los componentes Se elimina el Boton de Gain dado que un solo boton es insuficiente para controlar el osciloscopio y no se disponen de señales dig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
    [Display.sch, conector_poncho.sch, osciloscopio.sch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]
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2016-07-19 Se crea el proyecto y se carga todo el esquematico del circuito.
    [ADC.sch, Acon.sch, Conector.sch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]
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2016-07-19 agregado buzzer y medidor de batería
    [conector_poncho.sch, principal.sch, trabajo_final.sch]
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2016-07-21 Reorganizo bibliotecas en esquemático y PCB. Reparo señal de 12V. Agrego Footprints. Coloco plantilla EDU-CIAA. Reparo asociación conector EDU-CIAA en sch y pcb.
    [Inflarrojos.sch, PonchoSumoRobot.kicad_pcb, PonchoSumoRobot.sch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]
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2016-07-23 Se realiza el Placement de los componentes y un prerouteo para mostrar que el placement elegido permite un adecuado routeo del mismo.
    [Oscilloscopio.kicad_pcb, osciloscopio.sch, principal.sch]
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2016-07-25 Cambio SCH
    Se modificaron algunas etiquetas para beneficiar el routeo del pcb en la
    conexión Rele-Bornera.
    Se actualizaron las referencias de las huellas de la librería anterior a
    la actual, para lograr compatibilidad en el netlist y poder cargarlo al
    pcb.
    Se actualizaron los filtros de búsqueda de huellas en algunos
    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
    [DOut_PonchoPLC.sch, Din_PonchoPLC.sch, PonchoPLC.kicad_pcb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]
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2016-07-26 Se finaliza el prerouteo y se realizan las primeras correcciones de la revision
    Este routeo cumple chequeo de DRC pero no es definitivo, le faltan planos y detalles finos.
    Se realiza este commit antes de continuar con los demas cambios sugeridos por la revisión que son más peligrosos, como quitar una hoja del esquematico y quitar todos aquellos pines del AX1 que no se 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
    [Display.sch, Oscilloscopio.kicad_pcb, Oscilloscopio.sch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]
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2016-07-27 Finaliza proyecto en ultima clase de diseno PCB. Ultimos cambios en el repo.
    [buttons.sch, buzzer.sch, ciaaConector.sch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]
2016-07-27 Routeo Definitivo
    Queda pendiente volver locales los footprints y reparar el 3D de la placa
    [Oscilloscopio.kicad_pcb, Poncho_osc_rev1_DJB.ods, osciloscopio.sch]
2016-07-27 Ultimas correciones de la revisión
    _ Se copian localmente footprints y se los linkead
    _ Se copian localmente los modelos 3D y se los linkea
    [Display.sch, Oscilloscopio.kicad_pcb, Poncho_osc_rev1_DJB.ods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]
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2016-07-29 Avance posicionamiento
    Posicione las borneras de las entradas digitales.
    Arregle el footprint de las borneras para que tengan un pitch de 100mils
    Cambie a bottom layer algunos componentes para acercarme a un tamaño de
    placa de 150X100mm
    [PonchoPLC.kicad_pcb, PonchoPLC.sch]
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2016-08-07 ajustes en esquematicos y PCB con los planos de tierra y PWR
    [ECG_CIAA.kicad_pcb, ECG_CIAA.sch]
2016-08-07 se agregan mas campos para el BOM y se genran archivos GERBERS
    [ECG_CIAA.kicad_pcb, ECG_CIAA.sch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]
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2016-08-18 se eliminan etiquetas nenecesarias en esquematico y se corrige error
    [ECG_CIAA.sch]
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2016-09-29 Agrego JP1. Agrego pullup a línea de reset.
    [ethernet_LAN8720A_v2.kicad_pcb]
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2016-09-30 Agrego fiduciales y agujeros al PCB. Configuro DRC. Agrando vía debajo del IC, quito errores de DRC, reorganizo textos.
    [ethernet_LAN8720A_v2.kicad_pcb]
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2016-11-19 Corregido error de grilla en la plantilla
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2016-11-21 Correcion de errores, asignacion de footprints y ubicacion prelimilar de componentes.
    [ConectorPoncho.sch, EduPoncho.kicad_pcb, EduPoncho.sch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]
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2016-11-26 drills ok. fix size de rele
    [bom.csv, ponchoeduciaaiot.kicad_pcb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]
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2016-12-03 Se agregaron cotas, fiducidales y escrituras en cobre. Tambien se corrigieron algunos errores.
    [EduPoncho.kicad_pcb]
2016-12-03 Corregido: footprint batería, footprint GY-521, conector poncho para pasar ERC en esquemático, placement de footprints, dimensión del poncho para dejar descubierto el botón de reset de la EDU-CIAA. A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
    [Conector.sch, Mision_SAE.kicad_pcb, XBee.sch]
2016-12-12 Reubicacion de optoacopladores, cambio de footoprins de resistencias a 0805, correcion general.Falta arreglar archivos vista 3d y completar los campos #digikey
    [ConectorPoncho.sch, EduPoncho.kicad_pcb, EduPoncho.sch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]
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2016-12-14 Se corrigieron las cotas
    [EduPoncho.kicad_pcb]
2016-12-14 se corrigen errores de ERC, inicio de trabajo en pcb
    [driver_motores_EDU_CIAA.sch]
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2016-12-21 Corrección de errores in progress...
    [Conector.sch, Mision_SAE.kicad_pcb, Mision_SAE.sch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]
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2016-12-23 se borran las carpetas sobrantes, completa el rotulo, se corrige el esquematico, se agrega serigrafia, se agrega tabla con las grillas
    [driver_motores_EDU_CIAA.kicad_pcb, driver_motores_EDU_CIAA.sch]
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2017-03-14 Varios
    Cambio de logo CIAA por EDU-CIAA.
    Se ensancharon algunas pistas.
    Se cambio el conector del poncho hacia la EduCIAA para que no aparezcan
    los agujeros de sujeción y poder generar el gerber correctamente.
    [PonchoPLC.kicad_pcb, conector_poncho.sch]
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2017-04-20 Corrección icono
    Se cambió el nombre y la extensión del icono para que Kicad lo reconozca
    sin errores.
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2017-06-11 Corrección menor de librería de símbolos
    > Se corrige numeración de algunos pads en el símbolo ENCODER_w_SWITCH.
    > Se modifican propiedades de pines de alimentación 3,3v y 5v en el símbolo Conn_Poncho2P_2x_20x2 para evitar falsos errores de ERC.
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2017-06-14 Corrección menor de librería de símbolos
    Se corrige asignación incorrecta de pines en símbolo multiparte regular de CD40106.
2017-06-14 Se prosigue el trabajo en el esquemático
    > Se incluyen campos utilizados por KiCost en los componentes.
    > Se corrigen errores menores.
    > Se asignan algunos valores pendientes.
    > Se mejoran los rótulos.
    > Detalles cosméticos.
    [Conectores.sch, Interfaz_MIDI.sch, MIDI.kicad_pcb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]
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2017-06-18 Se corrige error en el esquematico
    > Se elimina conexión errónea entre 5v y GND en el conector XA1B.
    > Se incluye power flag conectado a GND.
    > Se reasignan las compuertas del buffer CD4050 para facilitar el ruteo.
    > Se trabaja sobre archivo de PCB:
    > Se completa el rótulo.
    > Se reacomodan los footprints según su relación con los componentes principales.
    [Conectores.sch, Interfaz_MIDI.sch, MIDI.kicad_pcb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]
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2017-07-03 Actualización de Readme.md
    Corrección de dos errores ortográficos menores.
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2017-07-12 Se corrige error en hoja de proyecto
    > Se corrige un error en los requisitos específicos: donde debía leerse "11. Su diseño no debe resultar prohibitivo(...)" se leía "11. Su diseño de debe resultar prohibitivo(...)"
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2017-07-15 Se corrige posición de modelo 3D
    > Se corrige los parametros de ajuste para el posicionamiento del modelo 3D correspondientes al footprint del header 2x20.
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2017-07-17 Correcciones menores en campos para BOM
    > Se corrigen error observados luego de la generación de la BOM.
    [Conectores.sch, Interfaz_MIDI.sch, MIDI.sch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]
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

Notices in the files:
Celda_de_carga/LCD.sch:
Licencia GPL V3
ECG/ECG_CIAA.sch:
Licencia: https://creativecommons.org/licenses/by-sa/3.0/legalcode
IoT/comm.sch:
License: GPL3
